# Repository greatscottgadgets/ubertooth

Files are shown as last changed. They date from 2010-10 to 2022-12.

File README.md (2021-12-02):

# Ubertooth

Project Ubertooth is an open source wireless development platform
suitable for Bluetooth experimentation. Ubertooth ships with a capable
BLE (Bluetooth Smart) sniffer and can sniff some data from Basic Rate
(BR) Bluetooth Classic connections.

The latest release is [2020-12-R1](https://github.com/greatscottgadgets/ubertooth/releases/tag/2020-12-R1).
The latest firmware build can be found on the release page.

This release is paired with [libbtbb 2020-12-R1](https://github.com/greatscottgadgets/libbtbb/releases/tag/2020-12-R1).

Instructions for flashing the firmware can be found [on the corresponding readthedocs.io firmware page](https://ubertooth.readthedocs.io/en/latest/firmware.html).
Instructions for building libbtbb can be found [on the corresponding readthedocs.io build_guide page](https://ubertooth.readthedocs.io/en/latest/build_guide.html).

--------------------

# Documentation

Documentation for Ubertooth can be viewed on [Read the Docs](https://ubertooth.readthedocs.io/en/latest/). The raw documenation files for Ubertooth are in the [docs folder](https://github.com/greatscottgadgets/ubertooth/tree/master/docs) in this repository. Documentation changes can be submitted through pull request and suggestions can be made as GitHub issues. 

--------------------

# Getting Help

Before asking for help with Ubertooth, check to see if your question is listed in the [FAQ](https://ubertooth.readthedocs.io/en/latest/faq.html).

For assistance with Ubertooth general use or development, please look at the [issues on the GitHub project](https://github.com/greatscottgadgets/ubertooth/issues). This is the preferred place to ask questions or open issues so that others may locate the answer to your question in the future.

We invite you to join our community discussions on [Discord](https://discord.gg/rsfMw3rsU8). Note that while technical support requests are welcome here, we do not have support staff on duty at all times. Be sure to also submit an issue on GitHub if you’ve found a bug or if you want to ensure that your request will be tracked and not overlooked.

GitHub issues on this repository that are labelled "technical support" by Great Scott Gadgets employees can expect a response time of two weeks. We currently do not have expected response times for other GitHub issues or pull requests for this repository.

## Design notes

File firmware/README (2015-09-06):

For testing a new board, see: assembly_test/README

The general purpose firmware including Bluetooth functions is bluetooth_rxtx.

This firmware is intended to be compiled with a particular toolchain:

    https://launchpad.net/gcc-arm-embedded

If you are using a recent Ubuntu or Debian system, the toolchain can be installed
from their apt repositorities as follows:

    apt-get install gcc-arm-none-eabi

The default hardware target is Ubertooth One.  If you are compiling for
Ubertooth Zero, you must set the environment variable BOARD=UBERTOOTH_ZERO.

By default the bluetooth-rxtx firmware has transmit capabilities.  If you wish
to build firmware without the ability to transmit, you may do so by setting an
envoronment variable called DISABLE_TX.  For example:

    make clean
    DISABLE_TX=1 make bluetooth_rxtx

The resulting firmware will still be named bluetooth_rxtx.bin.dfu but will be
receive only.  It is advisable to make clean first, to clear up any artifacts 
from previous builds that may have transmit functions enabled.

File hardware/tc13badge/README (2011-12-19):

Copyright 2010, 2011 Michael Ossmann

These files are part of Project Ubertooth.

This is a free hardware design; you can redistribute it and/or modify
it under the terms of the GNU General Public License as published by
the Free Software Foundation; either version 2, or (at your option)
any later version.

This design is distributed in the hope that it will be useful,
but WITHOUT ANY WARRANTY; without even the implied warranty of
MERCHANTABILITY or FITNESS FOR A PARTICULAR PURPOSE.  See the
GNU General Public License for more details.

You should have received a copy of the GNU General Public License
along with this design; see the file COPYING.  If not, write to
the Free Software Foundation, Inc., 51 Franklin Street,
Boston, MA 02110-1301, USA.

ToorCon 13 Badge

This is a special purpose Ubertooth design.  See:

http://greatscottgadgets.com/tc13badge/

hardware notes:

Schematic and layout files were designed in KiCad, an open source electronic
design automation package.

PCB description: 2 layer PCB 1.6 mm
DE104iML or equivalent substrate (Er=4.42@2.4GHz TanD=0.016)
double side solder mask black
double side silkscreen white
6 mil min trace width and
6 mil min isolation

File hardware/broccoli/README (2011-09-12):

Copyright 2010, 2011 Michael Ossmann

These files are part of Project Ubertooth.

This is a free hardware design; you can redistribute it and/or modify
it under the terms of the GNU General Public License as published by
the Free Software Foundation; either version 2, or (at your option)
any later version.

This design is distributed in the hope that it will be useful,
but WITHOUT ANY WARRANTY; without even the implied warranty of
MERCHANTABILITY or FITNESS FOR A PARTICULAR PURPOSE.  See the
GNU General Public License for more details.

You should have received a copy of the GNU General Public License
along with this design; see the file COPYING.  If not, write to
the Free Software Foundation, Inc., 51 Franklin Street,
Boston, MA 02110-1301, USA.

project code name: Broccoli

Trying out another wireless transceiver IC (TRC104).  It isn't finished yet.
There are problems with the TRC104 oscillator that need to be resolved before
testing can be completed.  Firmware for this design is being developed in
branches/broccoli but the hardware is in trunk.

hardware notes:

Schematic and layout files were designed in KiCad, an open source electronic
design automation package.

PCB description: 2 layer PCB 1.6 mm
DE104iML or equivalent substrate (Er=4.42@2.4GHz TanD=0.016)
double side solder mask black
double side silkscreen white
6 mil min trace width and
6 mil min isolation

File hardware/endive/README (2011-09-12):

Copyright 2010, 2011 Michael Ossmann

These files are part of Project Ubertooth.

This is a free hardware design; you can redistribute it and/or modify
it under the terms of the GNU General Public License as published by
the Free Software Foundation; either version 2, or (at your option)
any later version.

This design is distributed in the hope that it will be useful,
but WITHOUT ANY WARRANTY; without even the implied warranty of
MERCHANTABILITY or FITNESS FOR A PARTICULAR PURPOSE.  See the
GNU General Public License for more details.

You should have received a copy of the GNU General Public License
along with this design; see the file COPYING.  If not, write to
the Free Software Foundation, Inc., 51 Franklin Street,
Boston, MA 02110-1301, USA.

project code name: Endive

This is an adapter for the E8a programming connector on Dandelion.  It can be
used with either a Renesas E8a or a Pogoprog or similar FTDI board.

hardware notes:

Schematic and layout files were designed in KiCad, an open source electronic
design automation package.

PCB description: 2 layer PCB 1.6 mm
DE104iML or equivalent substrate (Er=4.42@2.4GHz TanD=0.016)
double side solder mask black
double side silkscreen white
10 mil min trace width and
10 mil min isolation

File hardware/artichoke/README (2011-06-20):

Copyright 2010 Michael Ossmann

These files are part of Project Ubertooth.

This is a free hardware design; you can redistribute it and/or modify
it under the terms of the GNU General Public License as published by
the Free Software Foundation; either version 2, or (at your option)
any later version.

This design is distributed in the hope that it will be useful,
but WITHOUT ANY WARRANTY; without even the implied warranty of
MERCHANTABILITY or FITNESS FOR A PARTICULAR PURPOSE.  See the
GNU General Public License for more details.

You should have received a copy of the GNU General Public License
along with this design; see the file COPYING.  If not, write to
the Free Software Foundation, Inc., 51 Franklin Street,
Boston, MA 02110-1301, USA.

project code name: Artichoke

This is candidate to become Ubertooth Two.  It isn't finished yet.

hardware notes:

Schematic and layout files were designed in KiCad, an open source electronic
design automation package.

order of copper layers:
	Front
	Inner3
	Inner2
	Back

PCB description: 4 layer PCB 1.6 mm
	Copper        1   35 um
	Dielectric  1-2   0.35 mm
	Copper        2   18 um
	Dielectric  2-3   0.76 mm
	Copper        3   18 um
	Dielectric  3-4   0.35 mm
	Copper        4   35 um
DE104iML or equivalent substrate (Er=4.42@2.4GHz TanD=0.016)
double side solder mask black
double side silkscreen white
6 mil min trace width and
6 mil min isolation

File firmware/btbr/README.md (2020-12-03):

# UBTBR firmware

This firmware implements partial support of the Bluetooth BR/EDR baseband layer.

## Supported features

- Inquiry/Inquiry scan: Perform inquiry to discover nearby devices, or reply to inquiries to be visible.
- Page/Page scan: Establish a connection as a master, or allow connection as slave.
- Link-Layer: Poor-man link-layer to maintain a connection.
- Monitoring: Spy on pairing procedures of remote devices

## Limitations / TODOs
- Due to limitations of the cc2400, only BR packets are supported.
- Packet types supported: ID, NULL, POLL, FHS, DM*, DH*.
- Link-layer only supports ACL packets.
- Master side of link-layer drains too much battery of the slave (FIXME: POLL less).
- Role-switching and related LMP procedures are not yet implemented.
- Encryption of packets is not yet implemented.

## Host code
The *ubtbr* python modules contains the host control interface and a minimal implementation of the LMP protocol. 

UBTBR can be controlled using the *ubtbr* python module, and the ubertooth-btbr tool.

See host/python/ubtbr/README.

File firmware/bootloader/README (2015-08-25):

bootloader.c is the first level firmware on the Ubertooth.  With this installed
you can update the main application over USB.

The bootloader must be installed using a hardware programmer (serial or JTAG).
For example, a Pogoprog (serial programmer) may be used with the In-System
Programming (ISP) mode.  Once the bootloader is installed, application firmware
may be loaded repeatedly over USB without requiring additional hardware.
Commercially produced Ubertooth devices should have the bootloader installed at
the factory.

Operation:

The bootloader executes every time the device starts up from reset or power
cycle.  Normally it just gets out of the way and passes control to the
application firmware very quickly.  Alternatively it can enter DFU mode which
permits firmware upload and download over USB.  There are two ways to tell the
bootloader that you want it to enter DFU mode:

1. soft bootloader entry: By setting a flag in RAM, the application firmware
can instruct the bootloader to enter DFU mode following a reset (without loss
of power).  For example, with the bluetooth_rxtx firmware running you can
update the firmware via DFU mode using the 'ubertooth-dfu' (located in
host/ubertooth-tools/src/).  Soft entry only works on Ubertooth One, not
Ubertooth Zero.

2. hard bootloader entry (aka pin entry): By connecting two pins on the
expansion header with a jumper during reset (either soft or hard boot), you can
force the bootloader into DFU mode.  When using pin entry, the bootloader will
enter DFU mode for only a few seconds and will then execute the application if
no DFU activity has started during that period.  This allows developers to
permanently or semi-permanently jumper the pins providing a DFU opportunity on
every reset.  The permanent jumper method works on Ubertooth One but not
Ubertooth Zero.

The bootloader indicates DFU mode by flashing the LEDs in a distinctive
pattern.  It also identifies itself as "usb_bootloader" on USB.

During DFU mode, firmware may be uploaded or downloaded using ubertooth-dfu.
For usage instructions, run 'ubertooth-dfu -h'.

It is possible that soft bootloader entry may be broken by installing a faulty
application or an application that does not provide a method of triggering soft
entry.  In this case, pin entry must be used (e.g. by holding a paper clip in
the expansion header while plugging in the device) to "unbrick" the unit.

For Ubertooth One, the pins to connect are pins 1 and 3 of the expansion header
(P4).  For Ubertooth Zero, the pins to connect are pins 1 and 13 of the
expansion header (J1).

The bootloader is installed at 0x0000.  It installs application firmware at
0x4000.

To build the bootloader you will need to install libstdc++ for ARM.
On Debian based systems:
apt-get install libstdc++-arm-none-eabi-newlib

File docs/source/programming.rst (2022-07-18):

===========
Programming
===========

This page describes how to load compiled firmware onto an Ubertooth One. Other pages describe how to write `firmware <https://ubertooth.readthedocs.io/en/latest/firmware.html>`__ or `host code <https://ubertooth.readthedocs.io/en/latest/software.html>`__ for the platform.

There are three ways to program an Ubertooth board: the USB bootloader, the ISP bootloader, and JTAG.

Please note that it is not possible to replace the board's USB bootloader via ubertooth-dfu as there is software protection in place. 

USB bootloader
~~~~~~~~~~~~~~

This is the recommended method of loading code onto an Ubertooth Zero or Ubertooth One provided that the USB bootloader is already installed (at the time of manufacture, for example). If you need to install the bootloader itself, you will have to use either ISP or JTAG.

The bootloader executes every time the device starts up from reset or power cycle. Normally it just gets out of the way and passes control to the application firmware very quickly. Alternatively it can enter Device Firmware Upgrade (DFU) mode which permits firmware upload and download over USB. There are two ways to tell the bootloader that you want it to enter DFU mode:

    #. soft bootloader entry: By setting a flag in RAM, the application firmware can instruct the bootloader to enter DFU mode following a reset (without loss of power). For example, with the bluetooth_rxtx firmware running you can trigger a reset into DFU mode using 'ubertooth-util -f' (located in host/bluetooth_rxtx/). Soft entry only works on Ubertooth One, not Ubertooth Zero.

    #. hard bootloader entry (also known as pin entry): By connecting two pins (for Ubertooth Zero it's pin 1 and 3) on the expansion header with a jumper during reset (either soft or hard boot), you can force the bootloader into DFU mode. When using pin entry, the bootloader will enter DFU mode for only a few seconds and will then execute the application if no DFU activity has started during that period. This allows developers to permanently or semi-permanently jumper the pins providing a DFU opportunity on every reset. This method works on Ubertooth One but not Ubertooth Zero.

The bootloader indicates DFU mode by flashing the LEDs in a distinctive pattern. It also identifies itself as "usb_bootloader" on USB.

During DFU mode, firmware may be uploaded or downloaded using ubertooth-dfu.

It is possible that soft bootloader entry may be broken by installing a faulty application or an application that does not provide a method of triggering soft entry. In this case, pin entry must be used (e.g. by holding a paper clip in the expansion header while plugging in the device) to "unbrick" the unit.

For Ubertooth One, the pins to connect are pins 1 and 3 of the expansion header (P4). For Ubertooth Zero, the pins to connect are pins 1 and 13 of the expansion header (J1).

ISP bootloader
~~~~~~~~~~~~~~

The LPC175x features an In-System Programming (ISP) bootloader that allows code to be loaded over a serial interface. In order to use ISP, you will need `lpc21isp <http://sourceforge.net/projects/lpc21isp>`__ and a 3.3V serial programming device such as one of the following:

Pogoprog
^^^^^^^^

The official Ubertooth ISP programmer is Pogoprog, an open source board that can be assembled using a process similar to Ubertooth One assembly.

An FTDI Basic Breakout - 3.3V
^^^^^^^^^^^^^^^^^^^^^^^^^^^^^

You can use SparkFun's `FTDI Basic Breakout - 3.3V <http://www.sparkfun.com/products/9873>`__ to program an Ubertooth. Adafruit's `FTDI Friend <http://www.adafruit.com/index.php?main_page=product_info&products_id=284>`__ is a similar board that should work as well. To allow lpc21isp to automatically activate the LPC175x's ISP bootloader, you must modify the board in one of two ways.

Method one: the easy way
++++++++++++++++++++++++

Just short the CTS pin to GND. This will force the microcontroller into ISP mode every time it resets while the programmer is connected. In order to perform a normal reset to run the newly loaded code, you will have to first disconnect the programmer.

Method two: the better way
++++++++++++++++++++++++++

Connect the CTS pin to the RTS pin (pin 3) on the FT232RL using fine gauge wire such as wire wrap wire. This is trickier to solder, but it has the advantage that the pin will be fully controlled by lpc21isp. This means that you can leave the programmer connected to the Ubertooth board throughout multiple program/test cycles.

Using ISP
+++++++++

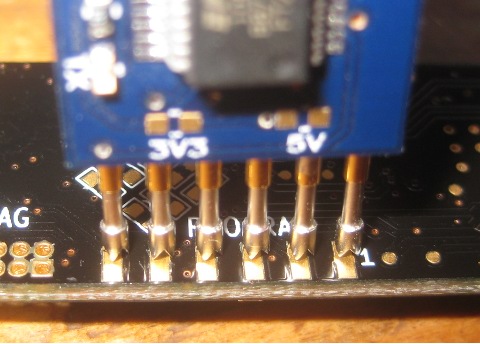
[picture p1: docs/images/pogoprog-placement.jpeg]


Warning: Code loaded via ISP will blow away the bootloader. It is generally recommended to use this method only for installing the bootloader itself.

Connect your serial programmer to the Ubertooth board and type "make program" in the firmware source code directory. If you have a precompiled binary in .hex format, you can invoke lpc21isp directly with "lpc21isp -control firmware.hex /dev/ttyUSB0 230400 4000" (replacing firmware.hex with the firmware filename and /dev/ttyUSB0 with the device file of your serial programmer.

JTAG
^^^^

Warning: Code loaded via JTAG will blow away the bootloader. It is generally recommended to use this method only for installing the bootloader itself.

Connect your ARM Cortex-M3 JTAG debugger (such as one supported by `OpenOCD <http://openocd.berlios.de/web>`__) to the standard Cortex Debug Connector on the Ubertooth One or the non-standard JTAG connector on the Ubertooth Zero. You know what to do.

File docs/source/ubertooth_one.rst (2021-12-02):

=============
Ubertooth One
=============

Ubertooth One is the hardware platform of Project Ubertooth. It supersedes `Ubertooth Zero <https://ubertooth.readthedocs.io/en/latest/ubertooth_zero.html>`__ and is currently the preferred platform.

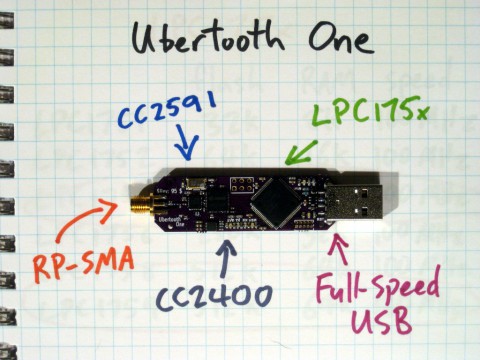
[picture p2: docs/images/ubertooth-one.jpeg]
	

Architecture
~~~~~~~~~~~~

* `RP-SMA <http://en.wikipedia.org/wiki/SMA_connector>`__ RF connector: connects to test equipment, antenna, or dummy load.

* `CC2591 <http://www.ti.com/product/cc2591>`__ RF front end.

* `CC2400 <http://www.ti.com/product/cc2400>`__ wireless transceiver.

* `LPC175x <http://www.nxp.com/products/microcontrollers-and-processors/arm-processors/lpc-cortex-m-mcus/lpc1700-cortex-m3:MC_1403790745385>`__ ARM Cortex-M3 microcontroller with Full-Speed USB 2.0.

* USB A plug: connects to host computer running `Kismet <https://www.kismetwireless.net/>`__ or other host code.

Features
~~~~~~~~

* 2.4 GHz transmit and receive.

* Transmit power and receive sensitivity comparable to a Class 1 Bluetooth device.

* Standard `Cortex Debug Connector <http://infocenter.arm.com/help/topic/com.arm.doc.faqs/attached/13634/cortex_debug_connectors.pdf>`__ (10-pin 50-mil JTAG).

* In-System Programming (ISP) serial connector.

* Expansion connector: intended for inter-Ubertooth communication or other future uses.

* Six indicator LEDs.

Design
~~~~~~

Ubertooth One was designed in `KiCad <https://www.kicad.org/>`__, an open source electronic design automation software package, with surface mount components suitable for `reflow <http://www.sparkfun.com/tutorials/59>`__.

Pins and LEDs
^^^^^^^^^^^^^

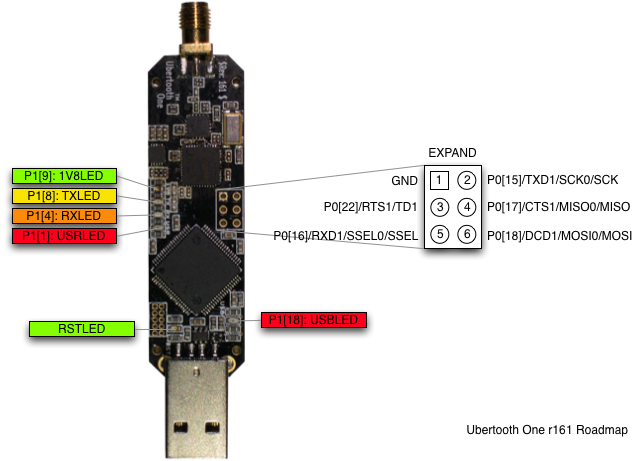
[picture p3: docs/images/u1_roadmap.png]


This diagram shows the location of LEDs and the pins of the expansion connector.

LED guide:

    * RST: indicates that the LPC175x is powered on. This should always be on during operation except during a full reset of the LPC175x (e.g., while entering ISP mode).

    * 1V8: indicates that the CC2400 is being supplied with 1.8 V. Control of this supply depends on firmware. 1V8 power is required to activate the crystal oscillator which is required to activate USB.

    * USB: indicates that USB has passed enumeration and configuration.

    * TX: Control of this LED depends on firmware. It typically indicates radio transmission.

    * RX: Control of this LED depends on firmware. It typically indicates radio reception.

    * USR: Control of this LED depends on firmware.

The TX, RX, and USR LEDs blink in a distinctive chasing pattern when the bootloader is ready to accept USB DFU commands.

Power Usage
^^^^^^^^^^^

These measurements were taken using Ubertooth One running firmware revision 2014-02-R2. Zero_Chaos took these measurements using a Centech CT-USB-PW, available via `eBay <http://www.ebay.com/itm/Century-JAPAN-USB-Power-Meter-voltage-measuring-instrument-Centech-CT-USB-PW-/151281911884>`__ and `others <http://store.mcetech.com/Merchant2/merchant.mvc?Screen=PROD&Product_Code=CT-USB-PW&Category_Code=USBPERIPH>`__.

.. list-table :: 
  :header-rows: 1
  :widths: 1 1 1

  * - Command
    - Description
    - Power draw (amps)
  * -
    - Idle
    - 0.09A
  * - ``ubertooth-dump``
    - Receive
    - 0.13A
  * - ``ubertooth-util -t``
    - Transmit
    - 0.22A
  * - ``ubertooth-dfu --write``
    - Firmware upgrade
    - 0.10A

Demonstration
^^^^^^^^^^^^^

Michael Ossmann presented `Project Ubertooth: Building a Better Bluetooth Adapter <http://www.shmoocon.org/schedule#ubertooth>`__ at `ShmooCon <http://www.shmoocon.org/>`__ 2011.

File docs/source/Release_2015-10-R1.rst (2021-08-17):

==================
Release 2015-10-R1
==================

Prerequisites
~~~~~~~~~~~~~

There are some prerequisites that need to be installed before building libbtbb and the Ubertooth tools. Many of these are available from your operating system's package repositories, for example:

Debian/Ubuntu
^^^^^^^^^^^^^

	.. code-block:: sh

		sudo apt-get install cmake libusb-1.0-0-dev make gcc g++ libbluetooth-dev \
		pkg-config libpcap-dev python-numpy python-pyside python-qt4

Fedora / Red Hat
^^^^^^^^^^^^^^^^

	.. code-block:: sh

		su -c "yum install libusb1-devel make gcc wget tar bluez-libs-devel"

Mac OS X users can use either MacPorts or Homebrew to install the required packages:
^^^^^^^^^^^^^^^^^^^^^^^^^^^^^^^^^^^^^^^^^^^^^^^^^^^^^^^^^^^^^^^^^^^^^^^^^^^^^^^^^^^^

	.. code-block:: sh

		sudo port install libusb wget cmake python27 py27-numpy py27-pyside
		or
		brew install libusb wget cmake pkg-config homebrew/dupes/libpcap

libbtbb
~~~~~~~

Next the Bluetooth baseband library (libbtbb) needs to be built for the Ubertooth tools to decode Bluetooth packets:

	.. code-block:: sh

		wget https://github.com/greatscottgadgets/libbtbb/archive/2015-10-R1.tar.gz -O libbtbb-2015-10-R1.tar.gz
		tar xf libbtbb-2015-10-R1.tar.gz
		cd libbtbb-2015-10-R1
		mkdir build
		cd build
		cmake ..
		make
		sudo make install

**Linux users:** if you are installing for the first time, or you receive errors about finding the library, you should run:

	.. code-block:: sh

		sudo ldconfig

Wireshark
~~~~~~~~~

Wireshark version 1.12 and newer includes the Ubertooth BLE plugin by default. It is also possible to `capture BLE from Ubertooth directly into Wireshark <https://ubertooth.readthedocs.io/en/latest/capturing_BLE_Wireshark.html>`__ with a little work.

The Wireshark BTBB and BR/EDR plugins allow Bluetooth baseband traffic that has been captured using Kismet to be analysed and disected within the Wireshark GUI. They are built separately from the rest of the Ubertooth and libbtbb software. The directory passed to cmake as ``MAKE_INSTALL_LIBDIR`` varies from system to system, but it should be the location of existing Wireshark plugins, such as ``asn1.so`` and ``ethercat.so``.

	.. code-block:: sh

		sudo apt-get install wireshark wireshark-dev libwireshark-dev cmake
		cd libbtbb-2015-10-R1/wireshark/plugins/btbb
		mkdir build
		cd build
		cmake -DCMAKE_INSTALL_LIBDIR=/usr/lib/x86_64-linux-gnu/wireshark/libwireshark3/plugins ..
		make
		sudo make install

Then repeat for the BT BR/EDR plugin:

	.. code-block:: sh

		sudo apt-get install wireshark wireshark-dev libwireshark-dev cmake
		cd libbtbb-2015-10-R1/wireshark/plugins/btbredr
		mkdir build
		cd build
		cmake -DCMAKE_INSTALL_LIBDIR=/usr/lib/x86_64-linux-gnu/wireshark/libwireshark3/plugins ..
		make
		sudo make install

Third Party Software
~~~~~~~~~~~~~~~~~~~~

There are a number of pieces of `third party software <https://ubertooth.readthedocs.io/en/latest/third_party_software.html>`__ that support the Ubertooth. Some support Ubertooth out of the box, while others require plugins to be built.

Firmware
^^^^^^^^

This completes the install of the Ubertooth tools, the next step is to look at the getting started guide. You should always `update the firmware <https://ubertooth.readthedocs.io/en/latest/firmware.html>`__ on the Ubertooth device to match the software release version that you are using.

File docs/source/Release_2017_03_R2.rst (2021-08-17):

==================
Release 2017-03-R2
==================

`for Release 2015-10-R1 see here <https://ubertooth.readthedocs.io/en/latest/Release_2015-10-R1.html>`__

Prerequisites
~~~~~~~~~~~~~

There are some prerequisites that need to be installed before building libbtbb and the Ubertooth tools. Many of these are available from your operating system's package repositories, for example:

Debian / Ubuntu

	.. code-block:: sh

		sudo apt-get install cmake libusb-1.0-0-dev make gcc g++ libbluetooth-dev \
		pkg-config libpcap-dev python-numpy python-pyside python-qt4

Fedora / Red Hat

	.. code-block:: sh

		su -c "yum install libusb1-devel make gcc wget tar bluez-libs-devel"

Mac OS X users can use either MacPorts or Homebrew to install the required packages:

	.. code-block:: sh

		sudo port install libusb wget cmake python27 py27-numpy py27-pyside
		or
		brew install libusb wget cmake pkg-config libpcap

FreeBSD users can install the host tools and library directly from the ports and package system:

	.. code-block:: sh

		sudo pkg install ubertooth

libbtbb
~~~~~~~

Next the Bluetooth baseband library (libbtbb) needs to be built for the Ubertooth tools to decode Bluetooth packets:

	.. code-block:: sh

		wget https://github.com/greatscottgadgets/libbtbb/archive/2017-03-R2.tar.gz -O libbtbb-2017-03-R2.tar.gz
		tar xf libbtbb-2017-03-R2.tar.gz
		cd libbtbb-2017-03-R2
		mkdir build
		cd build
		cmake ..
		make
		sudo make install

Linux users: if you are installing for the first time, or you receive errors about finding the library, you should run:	

	.. code-block:: sh

		sudo ldconfig

Ubertooth tools
~~~~~~~~~~~~~~~

The Ubertooth repository contains host code for sniffing Bluetooth packets, configuring the Ubertooth and updating firmware. All three are built and installed by default using the following method:

	.. code-block:: sh

		wget https://github.com/greatscottgadgets/ubertooth/releases/download/2017-03-R2/ubertooth-2017-03-R2.tar.xz -O ubertooth-2017-03-R2.tar.xz
		tar xf ubertooth-2017-03-R2.tar.xz
		cd ubertooth-2017-03-R2/host
		mkdir build
		cd build
		cmake ..
		make
		sudo make install

Linux users: if you are installing for the first time, or you receive errors about finding the library, you should run:

	.. code-block:: sh

		sudo ldconfig

Wireshark
~~~~~~~~~

Wireshark version 1.12 and newer includes the Ubertooth BLE plugin by default. It is also possible to `capture BLE from Ubertooth directly into Wireshark <https://ubertooth.readthedocs.io/en/latest/capturing_BLE_Wireshark.html>`__ with a little work.

The Wireshark BTBB and BR/EDR plugins allow Bluetooth baseband traffic that has been captured using Kismet to be analysed and disected within the Wireshark GUI. They are built separately from the rest of the Ubertooth and libbtbb software. The directory passed to cmake as ``MAKE_INSTALL_LIBDIR`` varies from system to system, but it should be the location of existing Wireshark plugins, such as ``asn1.so`` and ``ethercat.so``.

	.. code-block:: sh

		sudo apt-get install wireshark wireshark-dev libwireshark-dev cmake
		cd libbtbb-2017-03-R2/wireshark/plugins/btbb
		mkdir build
		cd build
		cmake -DCMAKE_INSTALL_LIBDIR=/usr/lib/x86_64-linux-gnu/wireshark/libwireshark3/plugins ..
		make
		sudo make install

Then repeat for the BT BR/EDR plugin:

	.. code-block:: sh

		sudo apt-get install wireshark wireshark-dev libwireshark-dev cmake
		cd libbtbb-2017-03-R2/wireshark/plugins/btbredr
		mkdir build
		cd build
		cmake -DCMAKE_INSTALL_LIBDIR=/usr/lib/x86_64-linux-gnu/wireshark/libwireshark3/plugins ..
		make
		sudo make install

Third Party Software
~~~~~~~~~~~~~~~~~~~~

There are a number of pieces of `third party software <https://ubertooth.readthedocs.io/en/latest/third_party_software.html>`__ that support the Ubertooth. Some support Ubertooth out of the box, while others require plugins to be built.

Firmware
^^^^^^^^

This completes the install of the Ubertooth tools, the next step is to look at the getting started guide. You should always `update the firmware <https://ubertooth.readthedocs.io/en/latest/firmware.html>`__ on the Ubertooth device to match the software release version that you are using.

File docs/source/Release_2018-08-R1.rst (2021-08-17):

======================================
Release 2018-08-R1: the DEFCON release
======================================

`for Release 2017-03-R2 see here <https://ubertooth.readthedocs.io/en/latest/Release_2017_03_R2.html>`__

Preequisites
~~~~~~~~~~~~

There are some prerequisites that need to be installed before building libbtbb and the Ubertooth tools. Many of these are available from your operating system's package repositories, for example:

Debian / Ubuntu

	.. code-block:: sh

		sudo apt-get install cmake libusb-1.0-0-dev make gcc g++ libbluetooth-dev \
		pkg-config libpcap-dev python-numpy python-pyside python-qt4

Fedora / Red Hat

	.. code-block:: sh

		su -c "yum install libusb1-devel make gcc wget tar bluez-libs-devel"s

Mac OS X users can use either MacPorts or Homebrew to install the required packages:

	.. code-block:: sh

		brew install libusb wget cmake pkg-config libpcap
		or
		sudo port install libusb wget cmake python27 py27-numpy py27-pyside

FreeBSD users can install the host tools and library directly from the ports and package system:

	.. code-block:: sh

		sudo pkg install ubertooth

libbtbb
~~~~~~~

Next the Bluetooth baseband library (libbtbb) needs to be built for the Ubertooth tools to decode Bluetooth packets:

	.. code-block:: sh

		wget https://github.com/greatscottgadgets/libbtbb/archive/2018-08-R1.tar.gz -O libbtbb-2018-08-R1.tar.gz
		tar -xf libbtbb-2018-08-R1.tar.gz
		cd libbtbb-2018-08-R1
		mkdir build
		cd build
		cmake ..
		make
		sudo make install	

Linux users: if you are installing for the first time, or you receive errors about finding the library, you should run:

	.. code-block:: sh

		sudo ldconfig

Ubertooth tools
~~~~~~~~~~~~~~~

The Ubertooth repository contains host code for sniffing Bluetooth packets, configuring the Ubertooth and updating firmware. All three are built and installed by default using the following method:

	.. code-block:: sh

		wget https://github.com/greatscottgadgets/ubertooth/releases/download/2018-08-R1/ubertooth-2018-08-R1.tar.xz
		tar xf ubertooth-2018-08-R1.tar.xz
		cd ubertooth-2018-08-R1/host
		mkdir build
		cd build
		cmake ..
		make
		sudo make install

Linux users: if you are installing for the first time, or you receive errors about finding the library, you should run:

	.. code-block:: sh

		sudo ldconfig

Wireshark
~~~~~~~~~

Wireshark version 1.12 and newer includes the Ubertooth BLE plugin by default. It is also possible to `capture BLE from Ubertooth directly into Wireshark <https://ubertooth.readthedocs.io/en/latest/capturing_BLE_Wireshark.html>`__ with a little work.

The Wireshark BTBB and BR/EDR plugins allow Bluetooth baseband traffic that has been captured using Kismet to be analysed and disected within the Wireshark GUI. They are built separately from the rest of the Ubertooth and libbtbb software.

The directory passed to cmake as ``MAKE_INSTALL_LIBDIR`` varies from system to system, but it should be the location of existing Wireshark plugins, such as ``asn1.so`` and ``ethercat.so``. On macOS this is likely ``/Applications/Wireshark.app/Contents/PlugIns/wireshark/``.

	.. code-block:: sh

		sudo apt-get install wireshark wireshark-dev libwireshark-dev cmake
		cd libbtbb-2018-08-R1/wireshark/plugins/btbb
		mkdir build
		cd build
		cmake -DCMAKE_INSTALL_LIBDIR=/usr/lib/x86_64-linux-gnu/wireshark/libwireshark3/plugins ..
		make
		sudo make install

Then repeat for the BT BR/EDR plugin:

	.. code-block:: sh

		sudo apt-get install wireshark wireshark-dev libwireshark-dev cmake
		cd libbtbb-2018-08-R1/wireshark/plugins/btbredr
		mkdir build
		cd build
		cmake -DCMAKE_INSTALL_LIBDIR=/usr/lib/x86_64-linux-gnu/wireshark/libwireshark3/plugins ..
		make
		sudo make install

Third Party Software
~~~~~~~~~~~~~~~~~~~~

There are a number of pieces of `third party software <https://ubertooth.readthedocs.io/en/latest/third_party_software.html>`__ that support the Ubertooth. Some support Ubertooth out of the box, while others require plugins to be built.

Firmware
^^^^^^^^

This completes the install of the Ubertooth tools, the next step is to look at the getting started guide. You should always `update the firmware <https://ubertooth.readthedocs.io/en/latest/firmware.html>`__ on the Ubertooth device to match the software release version that you are using.

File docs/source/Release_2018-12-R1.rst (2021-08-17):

==================
Release 2018-12-R1
==================

Prerequisites
~~~~~~~~~~~~~

There are some prerequisites that need to be installed before building libbtbb and the Ubertooth tools. Many of these are available from your operating system's package repositories, for example:

Debian / Ubuntu / Kali

	.. code-block:: sh

		sudo apt-get install cmake libusb-1.0-0-dev make gcc g++ libbluetooth-dev \
		  pkg-config python3-numpy python3-qtpy

Fedora / Red Hat

	.. code-block:: sh

		su -c "yum install libusb1-devel make gcc wget tar bluez-libs-devel"

Mac OS X users can use either MacPorts or Homebrew to install the required packages:

	.. code-block:: sh

		brew install libusb wget cmake pkg-config
		or
		sudo port install libusb wget cmake python38 py38-numpy py38-qtpy

FreeBSD users can install the host tools and library directly from the ports and package system:

	.. code-block:: sh

		sudo pkg install ubertooth

libbtbb
~~~~~~~

Next the Bluetooth baseband library (libbtbb) needs to be built for the Ubertooth tools to decode Bluetooth packets:

	.. code-block:: sh

		wget https://github.com/greatscottgadgets/libbtbb/archive/2018-12-R1.tar.gz -O libbtbb-2018-12-R1.tar.gz
		tar -xf libbtbb-2018-12-R1.tar.gz
		cd libbtbb-2018-12-R1
		mkdir build
		cd build
		cmake ..
		make
		sudo make install

Linux users: if you are installing for the first time, or you receive errors about finding the library, you should run:

	.. code-block:: sh

		sudo ldconfig

Ubertooth tools
~~~~~~~~~~~~~~~

The Ubertooth repository contains host code for sniffing Bluetooth packets, configuring the Ubertooth and updating firmware. All three are built and installed by default using the following method:

	.. code-block:: sh

		wget https://github.com/greatscottgadgets/ubertooth/releases/download/2018-12-R1/ubertooth-2018-12-R1.tar.xz
		tar xf ubertooth-2018-12-R1.tar.xz
		cd ubertooth-2018-12-R1/host
		mkdir build
		cd build
		cmake ..
		make
		sudo make install

Linux users: if you are installing for the first time, or you receive errors about finding the library, you should run:

	.. code-block:: sh

		sudo ldconfig

Wireshark
~~~~~~~~~

Wireshark version 1.12 and newer includes the Ubertooth BLE plugin by default. It is also possible to `capture BLE from Ubertooth directly into Wireshark <https://ubertooth.readthedocs.io/en/latest/capturing_BLE_Wireshark.html>`__ with a little work.

The Wireshark BTBB and BR/EDR plugins allow Bluetooth baseband traffic that has been captured using Kismet to be analysed and disected within the Wireshark GUI. They are built separately from the rest of the Ubertooth and libbtbb software.

The directory passed to cmake as ``MAKE_INSTALL_LIBDIR`` varies from system to system, but it should be the location of existing Wireshark plugins, such as ``asn1.so`` and ``ethercat.so``. On macOS this is likely ``/Applications/Wireshark.app/Contents/PlugIns/wireshark/``.

	.. code-block:: sh 

		sudo apt-get install wireshark wireshark-dev libwireshark-dev cmake
		cd libbtbb-2018-12-R1/wireshark/plugins/btbb
		mkdir build
		cd build
		cmake -DCMAKE_INSTALL_LIBDIR=/usr/lib/x86_64-linux-gnu/wireshark/libwireshark3/plugins ..
		make
		sudo make install	

Then repeat for the BT BR/EDR plugin:

	.. code-block:: sh

		sudo apt-get install wireshark wireshark-dev libwireshark-dev cmake
		cd libbtbb-2018-12-R1/wireshark/plugins/btbredr
		mkdir build
		cd build
		cmake -DCMAKE_INSTALL_LIBDIR=/usr/lib/x86_64-linux-gnu/wireshark/libwireshark3/plugins ..
		make
		sudo make install

Third Party Software
~~~~~~~~~~~~~~~~~~~~

There are a number of pieces of `third party software <https://ubertooth.readthedocs.io/en/latest/third_party_software.html>`__ that support the Ubertooth. Some support Ubertooth out of the box, while others require plugins to be built.

Firmware
^^^^^^^^

This completes the install of the Ubertooth tools, the next step is to look at the getting started guide. You should always `update the firmware <https://ubertooth.readthedocs.io/en/latest/firmware.html>`__ on the Ubertooth device to match the software release version that you are using.

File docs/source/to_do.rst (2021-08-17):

=========
ToDo List
=========

PCAP
~~~~

* Obtain DLT/linktype from libPCAP devs for BTBB, see `here <https://ubertooth.readthedocs.io/en/latest/bluetooth_captures_PCAP.html>`__.

* Define format for including meta-data (using PPI), see `here <https://ubertooth.readthedocs.io/en/latest/bluetooth_captures_PCAP.html>`__.

* Move Wireshark plugins to Wireshark repo.

* Add pcap support to ubertooth tools (currently only in kismet) by moving it to libbtbb.

Basic rate / libbtbb
~~~~~~~~~~~~~~~~~~~~

* Better handling of AFH maps when trying clock values. The code currently makes the assumption that AFH is enabled but all channels are in use.

* Detect syncword on Ubertooth for known piconets

* Make logging configurable - possibly combine text based logging, file dumps and pcap writing in to one logging system.

Releases
~~~~~~~~

* Binary packages for both libbtbb and ubertooth - rpm, deb, others?

* More frequent releases - requires better testing of code in git and separation of half-implemented features. This is more about process than an actionable todo item.

* DONE: Add uninstall to Makefile.

* Add WICD headers to support windows users (requires switch to libusbx).

GR-Bluetooth
~~~~~~~~~~~~

* Finish migration to libbtbb.

* Add BTLE support.

* General performance improvements (there must be some!).

Bigger / more vague projects
~~~~~~~~~~~~~~~~~~~~~~~~~~~~

* Transmit basic rate packets - inquiry scan to start with.

* Implement full BTLE device in firmware.

* ANT/ANT+ sniffing.

    * `http://www.thisisant.com/developer/resources/downloads/#documents_tab <http://www.thisisant.com/developer/resources/downloads/#documents_tab>`__

    * `http://www.thisisant.com/developer/resources/tech-faq/ <http://www.thisisant.com/developer/resources/tech-faq/>`__

* Communicate between Ubertooth devices using SPI on the expansion port.

* Communicate with other devices using SPI on the expansion port.

* Write to SD card using SPI on the expansion port.

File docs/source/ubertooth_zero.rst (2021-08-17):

==============
Ubertooth Zero
==============

Ubertooth Zero was the first working prototype hardware platform of Project Ubertooth. It has been superseded by `Ubertooth One <https://ubertooth.readthedocs.io/en/latest/ubertooth_one.html>`__.

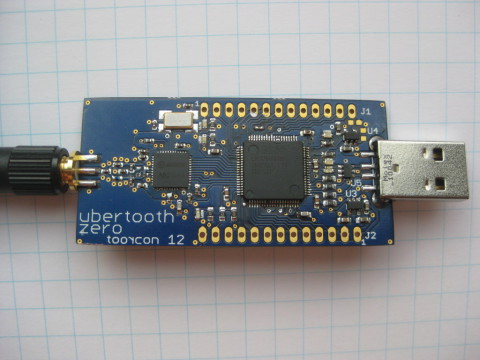
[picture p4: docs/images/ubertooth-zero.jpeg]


Architecture
~~~~~~~~~~~~

* `RP-SMA <http://en.wikipedia.org/wiki/SMA_connector>`__ RF connector: connects to test equipment, antenna, or dummy load.

* `CC2400 <http://focus.ti.com/docs/prod/folders/print/cc2400.html>`__ wireless transceiver IC.

* `LPC175x <http://ics.nxp.com/products/lpc1000/lpc17xx/>`__ ARM Cortex-M3 microcontroller with Full-Speed USB 2.0.

* USB A plug: connects to host computer running Kismet or other host code.

Features
~~~~~~~~

* 2.4 GHz transmit and receive.

* Transmit power and receive sensitivity comparable to a Class 3 Bluetooth device.

* Non-standard JTAG connector.

* In-System Programming (ISP) serial connector.

* Expansion connector: intended for inter-Ubertooth communication or other future uses.

* Six indicator LEDs.

Design
~~~~~~

Ubertooth Zero was designed in `CadSoft EAGLE <http://www.cadsoft.de/>`__ with surface mount components suitable for `reflow <http://www.sparkfun.com/tutorials/59>`__.

Demonstration
~~~~~~~~~~~~~

Michael Ossmann presented Ubertooth Zero, a preview (video: part 1, part 2) at ToorCon 12 in October, 2010.

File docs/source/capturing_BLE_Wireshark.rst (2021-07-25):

Capturing BLE in Wireshark
~~~~~~~~~~~~~~~~~~~~~~~~~~

You can capture BLE in Wireshark with standard Wireshark builds. This guide assumes Linux.

    #. Run the command: ``mkfifo /tmp/pipe``
    #. Open Wireshark
    #. Click Capture -> Options
    #. Click "Manage Interfaces" button on the right side of the window
    #. Click the "New" button
    #. In the "Pipe" text box, type "/tmp/pipe"
    #. Click Save, then click Close
    #. Click "Start"

In a terminal, run ``ubertooth-btle``:

	.. code-block:: sh

		ubertooth-btle -f -c /tmp/pipe

In the Wireshark window you should see packets scrolling by.

Note: If you get `User encapsulation not handled: DLT=147, check your Preferences->Protocols->DLT_USER <https://github.com/greatscottgadgets/ubertooth/issues/61>`__ the steps you want are:

    #. Click Edit -> Preferences
    #. Click Protocols -> DLT_USER
    #. Click Edit (Encapsulations Table)
    #. Click New
    #. Under DLT, select "User 0 (DLT=147)" (adjust this selection as appropriate if the error message showed a different DLT number than 147)
    #. Under Payload Protocol, enter: btle
    #. Click OK
    #. Click OK

Capturing BLE in scapy
^^^^^^^^^^^^^^^^^^^^^^

#. Do not use mkfifo for the filename, it will cause scapy to slow dramatically.

#. In a terminal, run ubertooth-btle:

	.. code-block:: sh

		ubertooth-btle -f -q /tmp/pipe

#. Open python and run:

	.. code-block:: sh

		from scapy.all import *
		p = sniff(offline='/tmp/pipe')

p is now a list of the packets captured!

Sniffing connection data
^^^^^^^^^^^^^^^^^^^^^^^^

With recent Ubertooth firmware, only advertisements are captured by default. Once you have identified the device address of the target device you would like to sniff, run:

	.. code-block:: sh

		ubertooth-btle -t aa:bb:cc:dd:ee:ff

The Ubertooth will follow connections involving this target until -t none is passed or the device is reset.

You may need to attempt connecting several times until Ubertooth is able to follow the connection successfully.

Capturing from a remote host
^^^^^^^^^^^^^^^^^^^^^^^^^^^^

You can use `sshdump <https://www.wireshark.org/docs/man-pages/sshdump.html>`__ to remotely capture packets from a Ubertooth attached to another host or virtual machine. In the Wireshark UI, this may show up as an interface named "SSH remote capture: ``sshdump``" which needs to be configured first with the following "remote capture command":

	.. code-block:: sh

		killall ubertooth-btle; unlink /tmp/btlepipe; mkfifo /tmp/btlepipe; ubertooth-btle -f -c /tmp/btlepipe &>/dev/null & cat /tmp/btlepipe

The "remote interface" option is ignored and can be set to any value.

Useful display filters
^^^^^^^^^^^^^^^^^^^^^^

Only connection requests and non-zero data packets:

	.. code-block:: sh

		btle.data_header.length > 0 || btle.advertising_header.pdu_type == 0x05

Only attribute read responses, write requests, and notifications:

	.. code-block:: sh

		btatt.opcode in { 0x0b 0x12 0x1b }

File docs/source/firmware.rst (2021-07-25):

========
Firmware
========

How To Update Firmware
~~~~~~~~~~~~~~~~~~~~~~

First, grab the `latest Ubertooth release <https://github.com/greatscottgadgets/ubertooth/releases/latest>`__. Then, extract the archive and change into directory ``ubertooth-one-firmware-bin``.

You may then run the ``ubertooth-dfu`` command like so:

	.. code-block:: Sh

		$ ubertooth-dfu -d bluetooth_rxtx.dfu -r
		Switching to DFU mode...
		Checking firmware signature
		........................................
		........................................
		................

The device will automatically enter DFU mode and flash the firmware.

If you see ``control message unsupported`` at the end, this means that resetting the device failed. You can handle this by running ``ubertooth-util -r`` or just unplugging the USB cable from the Ubertooth and reconnecting it.

Troubleshooting:

If you run into an error such as "libUSB Error: Command Error: (-1)" or the Ubertooth's 4 LEDs next to each other perform a distinctive chasing pattern, after extracting the archive of the latest Ubertooth release, change into the ``firmware`` directory. Then, run:

	.. code-block:: sh

		make clean all && make
		ubertooth-dfu -r -d bluetooth_rxtx/bluetooth_rxtx.dfu

If your Ubertooth Ones has no firmware or broken firmware and doesn't show up when issuing ``lsusb``, you can force the Ubertooth One into DFU mode by connecting pins 1 and 3 on the EXPAND header (P4):

	

You should see the following appear in dmesg:

	.. code-block:: sh

		[ 1323.391369] usb 1-10: new full-speed USB device number 7 using xhci_hcd
		[ 1323.541063] usb 1-10: New USB device found, idVendor=1d50, idProduct=6002, bcdDevice= 1.05
		[ 1323.541069] usb 1-10: New USB device strings: Mfr=1, Product=2, SerialNumber=3
		[ 1323.541073] usb 1-10: Product: Ubertooth One
		[ 1323.541077] usb 1-10: Manufacturer: Great Scott Gadgets
		[ 1323.541080] usb 1-10: SerialNumber: 07b00004c81435ae82624953861e00f5
		[ 1341.978766] usb 1-10: USB disconnect, device number 7

The device will only stay in dfu mode for a few seconds, so you have to quickly issue the ubertooth-dfu command to flash.

What Version Am I Running? 
^^^^^^^^^^^^^^^^^^^^^^^^^^

In non-DFU mode, you can obtain firmware information with ``ubertooth-util -v``. Note that the version shown should match the one you just installed:

	.. code-block:: sh

		$ ubertooth-util -v
		Firmware version: 2018-12-R1 (API:1.05)
		$ ubertooth-util -V
		ubertooth 2018-12-R1 (mikeryan@steel) Tue Aug  7 15:33:06 PDT 2018

Developing Firmware
^^^^^^^^^^^^^^^^^^^

You'll need a toolchain that supports ARM Cortex-M3. The Makefiles in the firmware directory are designed for GCC and a Linux-based toolchain, specifically ``arm-none-eabi-gcc and libnewlib-arm-none-eabi``. If you are running a Debian based distribution, you can run:

	.. code-block:: sh

		apt-get install gcc-arm-none-eabi libnewlib-arm-none-eabi

Otherwise it can be downloaded from `https://launchpad.net/gcc-arm-embedded <https://launchpad.net/gcc-arm-embedded>`__, just unpack the archive and add the bin directory to your PATH.

To build the firmware, start from the directory where you cloned or unpacked the source and run the following:

	.. code-block:: sh

		cd firmware/bluetooth_rxtx/
		make

This will produce a file named bluetooth_rxtx.dfu which can be written to the Ubertooth using

	.. code-block:: sh

		ubertooth-dfu -d bluetooth_rxtx.dfu -r

Although firmware source and binary images can be found in the release downloads, you will probably want fresh code from git if you are planning to modify the firmware.

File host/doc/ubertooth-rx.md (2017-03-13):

# UBERTOOTH-RX 1 "March 2017" "Project Ubertooth" "User Commands"

## NAME

ubertooth-rx(1) - Classic Bluetooth discovery, sniffing, and decoding

## SYNOPSIS

    ubertooth-rx [ -l <lap> [ -u <uap ] ]
    ubertooth-rx -z

## DESCRIPTION

ubertooth-rx(1) is the primary interface into Classic Bluetooth (BR)
functionality provided by Ubertooth. It has two main modes of operation:
piconet following and survey mode. In either mode, ubertooth-rx(1) is
able to discover undiscoverable devices. See [DISCOVERING UNDISCOVERABLE
DEVICES][].

In piconet following mode, the tool will follow the first piconet it
fully identifies. In survey mode the device will attempt to identify all
piconets in a given area and display them after either a timeout or
manual interruption.

Piconet following is the main mode entered when no arguments are passed
to the command or a LAP and optionally a UAP are provided. If no
arguments are passed, the tool will attempt to calculate the UAP for any
observed LAPs. If a LAP is passed, the UAP will be calculated for that
specific LAP. Once a LAP and UAP have been recovered, the tool will
attempt to recover the clock value, and if that succeeds it will follow
that piconet.

Survey mode, entered using `-z`, will record all LAPs and attempt to
calculate the UAPs for any observed LAPs. This mode can be combined with
a timeout using `-t`, and it can be interrupted at any time using
`ctrl-C`.

## EXAMPLES

Follow the first piconet whose LAP, UAP, and clock are recovered from
the air:

    ubertooth-rx

For a given LAP, calculate the UAP and recover the clock, then follow:

    ubertooth-rx -l 112233

For a given LAP and UAP, recover the clock then follow:

    ubertooth-rx -l 112233 -u ab

Enter survey mode for 20 seconds, and print out the BD ADDRs of all
observed piconets:

    ubertooth-rx -z -t 20

## OPTIONS

Major modes:

 - `-l <lap>` :
   Limit UAP recovery, clock recovery, and piconet following to a given
   LAP. Format is 3 bytes / 6 hex characters.

 - `-u <uap>` :
   Limit clock recovery and piconet following to a given UAP. Must be
   used in conjunction with `-l`. Format is 1 byte / 2 hex characters.

 - `-z` :
   Survey mode: recover all LAP and UAP pairs and display them. Will run
   indefinitely until interrupted with `ctrl-C` unless paired with `-t`.

Options:

 - `-i <input>` :
   Input file. If not specified will perform live capture using
   Ubertooth.

 - `-c <0-79>` :
   Fixed channel for all major modes. If not specified will sweep
   through all channels.

 - `-e <0-4>` :
   Maximum access code bit errors. [Default: 2]

 - `-t <seconds>` :
   Timeout in seconds. If not specified will run indefinitely. Suggested
   values for `-z`: 20-60 seconds.

Output options:

 - `-r <file.pcapng>` :
   Capture packets to PcapNG
 - `-q <file.pcap>` :
   Capture packets to PCAP
 - `-d <file.bin>` :
   Capture packets to binary file suitable for use with `-i`.

Miscellaneous:

 - `-V` :
   Version information

 - `-U<0-7>` :
   Which Ubertooth device to use

## DISCOVERING UNDISCOVERABLE DEVICES

Classic Bluetooth piocnets are defined by the Lower Address Part (LAP)
and Upper Address Part (UAP) of the master device. These are elements
of the master device's Bluetooth Address (BD ADDR).

Consider the following BD ADDR:

    22:44:66:88:AA:BB

The lower address part (LAP) is the lower 24 bits, so `88:AA:BB`. In the
context of this tool, the value is written `88AABB`. The upper address
part is the next 8 bits, so `66`. The `22:44` is called the
Non-significant Address Part (NAP) and as you might imagine it is not
significant.

In piconet following mode, the tool will recover LAP values from the air
and attempt to calculate the UAP from those. It will go on to follow the
piconet if it can recover the clock value. In survey mode, the tool will
simply recover LAP and UAP values.

To convert LAP + UAP pairs back into Bluetooth addresses, do the reverse
of the above. For example, if the tool recovers a LAP of 36A2B4 and a
UAP of 98, the associated Bluetooth address is `??:??:98:36:A2:B4`. Any
value can be substituted into the ?? slots and most Bluetooth tools will
still work. For example, `hcitool name 00:00:98:36:A2:B4` will establish
a connection to the device and return its name.

This attack works against discoverable and undiscoverable devices alike.

## SEE ALSO

ubertooth-scan(1): active device scanning and inquiry using Ubertooth
and BlueZ

ubertooth(7): overview of Project Ubertooth

D. Spill and A. Bittau. "BlueSniff: Eve Meets Alice and Bluetooth."
USENIX WOOT 2007.

## AUTHOR

This manual page was written by Mike Ryan.

## COPYRIGHT

ubertooth-rx(1) is Copyright (c) 2010-2017 Michael Ossmann, Dominic
Spill, and others. This tool is released under the GPLv2. Refer to
`COPYING` for further details.

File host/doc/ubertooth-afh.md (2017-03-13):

# UBERTOOTH-AFH 1 "March 2017" "Project Ubertooth" "User Commands"

## NAME

ubertooth-afh(1) - passive detection of AFH channel map

## SYNOPSIS

    ubertooth-afh -u <uap> -l <lap> [-r] [-m <seconds>]

## DESCRIPTION

Classic Bluetooth piconets commonly make use of Adaptive Frequency
Hopping (AFH) to avoid interference with other signals in 2.4 GHz. This
tool attempts to determine the AFH map being used for a given piconet
identified by UAP and LAP.

At a minimum you must provide UAP and LAP. See ubertooth-rx(1) for a
method for sniffing these over the air and details on where else to find
them. By default the tool will only print the AFH map when it is
updated. By providing the `-r` flag, the AFH map will be printed out in
binary form once per second.

## OPTIONS

 - `-l <LAP>` :
   LAP of target piconet (3 bytes / 6 hex digits)
 - `-u <UAP>` :
   UAP of target piconet (1 byte / 2 hex digits)
 - `-m <int>` :
   threshold for channel removal (default: 5)
 - `-r` :
   print AFH channel map once every second (default: print on update)

Other options:

 - `-t <seconds>` :
   timeout for initial AFH map detection (not required)
 - `-e <0-4>` :
   maximum access code errors (default: 2, range: 0-4)
 - `-V` :
   print version information
 - `-U <0-7>` :
   set ubertooth device to use

## SEE ALSO

ubertooth-rx(1): a tool for finding UAP and LAP

ubertooth(7): overview of Project Ubertooth

## AUTHOR

This manual page was written by Mike Ryan.

## COPYRIGHT

ubertooth-afh(1) is Copyright (c) 2015-2017. This tool is released under the
GPLv2. Refer to `COPYING` for further details.

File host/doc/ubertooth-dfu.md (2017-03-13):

# UBERTOOTH-DFU 1 "March 2017" "Project Ubertooth" "User Commands"

## NAME

ubertooth-dfu(1) - Device firmware update for Ubertooth

## SYNOPSIS

To update firmware, run:

    ubertooth-dfu -d bluetooth_rxtx.dfu -r

## DESCRIPTION

ubertooth-dfu(1) is a utility for updating firmware on Ubertooth. It can
also download the currently running firmware from the device.

Running the upload or download command automatically resets the device
into the firmware update bootloader. The USB ID of the Ubertooth will
change in the bootloader, and this may cause problems when attempting to
update firmware from inside a VM.

In the DFU bootloader, the TX, RX, and USR LEDs will turn on and off in
sequence. If this does not occur, you can try to manually force the
device to boot into the bootloader. Refer to [MANUALLY ENTERING
BOOTLOADER][].

## OPTIONS

Major modes:

 - `-d <firmware.dfu>` :
   Download - write DFU file to device
 - `-u <output.dfu>` :
   Upload - read DFU file from device
 - `-r` :
   Reset device after performing operation

Miscellaneous:

 - `-s <file.bin>` :
   Add DFU suffix to binary firmware file
 - `-U <0-7>` :
   Which Ubertooth device to use

## MANUALLY ENTERING BOOTLOADER

If the device does not enter the bootloader when running the upload or
download commands, it is possible to force the device to boot into that
mode when it is inserted. To do so, you will need to jumper two pins on
the expansion header.

The expansion header is a 2x3 pin header between the two largest chips
on the board, about halfway between the USB connector and antenna. It is
labeled "EXPAND" on the back side of the board. Holding the board so USB
is pointed up, on the front side of the board the expansion header looks
like this:

      +-------+
    6 + O | O | 3
      +---+---+
    5 + O | O | 2
      +---+---+
    4 + O | X | 1
      +---+---+

PIN #1, marked X, is square.

With Ubertooth unplugged, use a piece of wire, paperclip, staple, etc to
connect pins 1 and 2 together. When it it plugged in, the Ubertooth
should enter bootloader mode (LEDs will be turning on and off in
sequence).

The bootloader will exit after 5 seconds of no activity and boot into
the main firmware.

## SEE ALSO

ubertooth(7): overview of Project Ubertooth

## AUTHOR

This manual page was written by Mike Ryan.

## COPYRIGHT

ubertooth-dfu(1) is Copyright (c) 2010-2017. This tool is released under
the GPLv2. Refer to `COPYING` for further details.

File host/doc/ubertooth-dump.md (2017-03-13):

# UBERTOOTH-DUMP 1 "March 2017" "Project Ubertooth" "User Commands"

## NAME

ubertooth-dump(1) - output a continuous stream of received bits

## SYNOPSIS

    ubertooth-dump [-b] [-c | -l] [-d <filename.bin>]

## DESCRIPTION

This tool dumps the raw bitstream received from the CC2400 radio to
STDOUT or a file (if specified with `-d`). It can configure the radio to
demodulate Classic Bluetooth with `-c` (default), or Bluetooth Low
Energy (BLE) with `-l`. Optionally it can decode the binary data and
print ASCII 0 and 1 using `-b`.'

## OPTIONS

 - `-b` :
   Print ASCII 0 and 1 instead of raw data
 - `-c` :
   Classic Bluetooth modulation (default)
 - `-l` :
   Bluetooth Low Energy (BLE) modulation
 - `-d <filename.bin>` :
   Dump to file instead of stdout
 - `-U <0-7>` :
   which Ubertooth device to use

## SEE ALSO

ubertooth(7): overview of Project Ubertooth

## AUTHOR

This manual page was written by Mike Ryan.

## COPYRIGHT

ubertooth-dump(1) is Copyright (c) 2010-2017. This tool is released under the
GPLv2. Refer to `COPYING` for further details.

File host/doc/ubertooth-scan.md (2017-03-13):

# UBERTOOTH-SCAN 1 "March 2017" "Project Ubertooth" "User Commands"

## NAME

ubertooth-scan(1) - active(Bluez) device scan and inquiry supported by Ubertooth

## SYNOPSIS

ubertooth-scan [-s] [-x]

## DESCRIPTION

This tool uses a normal Bluetooth dongle to perform Inquiry Scans and
Extended Inquiry scans of Bluetooth devices. It uses Ubertooth to
discover undiscoverable devices and can use BlueZ to scan for
discoverable devices.

## EXAMPLES

Use Ubertooth to discover devices and perform Inquiry Scan with BlueZ:

    ubertooth-scan

Use BlueZ and Ubertooth to discover devices and perform Inquiry Scan and
Extended Inquiry Scan:

    ubertooth-scan -s -x

## OPTIONS

 - `-s` :
   hci Scan - use BlueZ to scan for discoverable devices
 - `-x` :
   eXtended scan - retrieve additional information about target devices
 - `-t <seconds>` :
   scan Time - length of time to sniff packets. [Default: 20s]
 - `-e <0-4>` : 
    Maximum Access Code Errors (default: 2)
 - `-b hciN` :
    Bluetooth device (default: hci0)
 - `-U<0-7>` :
    which Ubertooth device to use

## SEE ALSO

ubertooth-rx(1): Discover devices passively with Ubertooth

ubertooth(7): overview of Project Ubertooth

## AUTHOR

This manual page was written by Mike Ryan.

## COPYRIGHT

ubertooth-scan(1) is Copyright (c) 2010-2017. This tool is released under the
GPLv2. Refer to `COPYING` for further details.

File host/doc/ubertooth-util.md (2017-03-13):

# UBERTOOTH-UTIL 1 "March 2017" "Project Ubertooth" "User Commands"

## NAME

ubertooth-util(1) - general purpose Ubertooth utility

## SYNOPSIS

ubertooth-util [-abcdefghijk-ellemenop-qrstuvwxyZ]

## DESCRIPTION

ubertooth-util(1) is a catch-all tool for doing generally useful things
with, to, and about Ubertooth. To get firmware revision and compile
information, run:

    ubertooth-util -vV

To fully reset Ubertooth, run:

    ubertooth-util -r

Other options are available for modifying LED states, setting channel,
and performing miscellaneous radio-related actions. Refer to the
[OPTIONS][] section for full details.

The utility also includes a simple range test tool for use with two
Uberteeth. Refer to [RANGE TEST][] for full details.

## OPTIONS

Common options:

 - `-v` :
   get firmware revision number
 - `-V` :
   get compile info
 - `-I` :
   identify ubertooth device by flashing all LEDs
 - `-d[0-1]` :
   get/set all LEDs
 - `-l[0-1]` :
   get/set USR LED
 - `-S` :
   stop current operation
 - `-r` :
   full reset
 - `-U<0-7>` :
   set ubertooth device to use

Radio options:

 - `-a[0-7]` :
   get/set power amplifier level
 - `-c[2400-2483]` :
   get/set channel in MHz
 - `-C[0-78]` :
   get/set channel
 - `-q[1-225 (RSSI threshold)]` :
   start LED spectrum analyzer
 - `-t` :
   intitiate continuous transmit test
 - `-z` :
   set squelch level

Range test:

 - `-e` :
   start repeater mode
 - `-m` :
   display range test result
 - `-n` :
   initiate range test

Miscellaneous:

 - `-f` :
   activate flash programming (DFU) mode
 - `-i` :
   activate In-System Programming (ISP) mode
 - `-b` :
   get hardware board id number
 - `-p` :
   get microcontroller Part ID
 - `-s` :
   get microcontroller serial number

## RANGE TEST

Using two Uberteeth it is possible to perform a range test. One
Ubertooth acts as a repeated by running:

    ubertooth-util -e

A second Ubertooth (the sender) initiates the range test by running:

    ubertooth-util -n

During the range test the sender Ubertooth will transmit data packets at
increasing power level, listening for repeats from the repeater
Ubertooth. The receiving Ubertooth will validate that the received data
was not corrupted in flight.

The range test results can be displayed on the sender Ubertooth's system
by running:

    ubertooth-util -m

Note that the range test transmits the Cortex M3 microcontroller's
serial number. If you do not wish to broadcast that information
wirelessly, do not use the range test functionality.

## SEE ALSO

ubertooth(7): overview of Project Ubertooth

## AUTHOR

This manual page was written by Mike Ryan.

## COPYRIGHT

ubertooth-util(1) is Copyright (c) 2010-2017. This tool is released under the
GPLv2. Refer to `COPYING` for further details.

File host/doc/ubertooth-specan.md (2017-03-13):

# UBERTOOTH-SPECAN 1 "March 2017" "Project Ubertooth" "User Commands"

## NAME

ubertooth-specan(1) - a spectrum analyzer for Ubertooth

## SYNOPSIS

ubertooth-specan [-l <freq>] [-u <freq>] [-g|G]

## DESCRIPTION

ubertooth-specan(1) is a tool for using Ubertooth as a spectrum analyzer
in the 2.4GHz band. It is often used as a helper for GUI tools, such as
ubertooth-specan-ui or Spectools. It can also produce output suitable for
user with the feedgnuplot tool.

Other options allow upper and lower bounds to be set on the frequencies
monitored. Refer to the [OPTIONS][] section for full details.

## OPTIONS

Options:

 - `-l` :
   lower frequency (default 2402)
 - `-u` :
   upper frequency (default 2480)
 - `-g` :
   format output for feedgnuplot
 - `-G` :
   format output for 3D feedgnuplot
 - `-d<filename>` :
   output to file <filename>
 - `-v` :
   print verbose output to stderr
 - `-U<0-7>` :
   set ubertooth device to use

##EXAMPLES

To monitor the 2.4GHz band and produce a file suitable for feedgnuplot:

   ubertooth-specan -g -d output.dat

To monitor the upper half of the 2.4GHz band, use:

   ubertooth-specan -l 2440

## SEE ALSO

ubertooth(7): overview of Project Ubertooth

## AUTHOR

This manual page was written by Dominic Spill.

## COPYRIGHT

ubertooth-specan(1) is Copyright (c) 2010-2017. This tool is released under the
GPLv2. Refer to `COPYING` for further details.

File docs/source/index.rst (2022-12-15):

Ubertooth
=====================================

.. toctree::
  :maxdepth: 1
  :caption: User Documentation

  ubertooth_one
  build_guide
  faq
  getting_started
  getting_help
  capturing_BLE_Wireshark
  bluetooth_captures_PCAP
  history
  ubertooth_projects_mentions

.. toctree::
  :maxdepth: 1
  :caption: Software

  building_from_git
  software
  third_party_software

.. toctree::
  :maxdepth: 1
  :caption: Firmware

  firmware
  programming

.. toctree::
  :maxdepth: 1
  :caption: Hardware

  assembling_hardware

.. toctree::
  :maxdepth: 1
  :caption: Release Notes  

  Release_2015-10-R1
  Release_2017_03_R2
  Release_2018-08-R1
  Release_2018-12-R1   

.. toctree::
  :maxdepth: 1
  :caption: Retired Content

  to_do
  release_procedure   
  ubertooth_two_wishlist
  ubertooth_zero

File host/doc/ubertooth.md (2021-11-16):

# UBERTOOTH 7 "March 2017" "Project Ubertooth" "Project Ubertooth Overview"

## NAME

ubertooth(7) - Project Ubertooth

## OVERVIEW

Ubertooth is a platform for Bluetooth experimentation. It is able to
sniff Bluetooth Smart (BLE), discover undiscoverable classic Bluetooth
devices, and perform rudimentary sniffing of classic Bluetooth devices.

Ubertooth is **not** a Bluetooth dongle and it will not show up as one
when running `hciconfig`.

## COMMAND LINE TOOLS

The following command line tools included in this package are the
primary means of using Ubertooth. Refer to their manual pages for
example usage and comprehensive documentation.

Useful commands:

 - ubertooth-btle(1) : BLE sniffing and other fun
 - ubertooth-rx(1) : Classic Bluetooth device discovery and rudimentary sniffing
 - ubertooth-scan(1) : Active scanning of undiscoverable devices
 - ubertooth-afh(1) : Detecting the AFH map of a Classic Bluetooth piconet
 - ubertooth-ego(1) : Yuneec E-Go electric skateboard sniffing

Utility commands:

 - ubertooth-dfu(1) : Firmware update tool
 - ubertooth-dump(1) : Dumping raw RF symbols to disk
 - ubertooth-util(1) : "Everything else"

Less useful commands:

 - ubertooth-debug(1) : Peeking and poking registers on the CC2400
 - ubertooth-specan(1) : Raw RSSI values used by graphical specan

## SUPPORT

Ubertooth is an open source project maintained primarily by volunteers.
Please keep that in mind when seeking support.

If you are having issues with a tool or believe you have found a bug,
please file an issue on the project GitHub:
<https://github.com/greatscottgadgets/ubertooth>

For interactive support, join the `#ubertooth` channel on Discord:
<https://discord.gg/rsfMw3rsU8>

## COPYRIGHT

The code and documentation for Project Ubertooth are Copyright 2010-2017
and are available under the terms of the GPLv2. Refer to `COPYING` for
details. Ubertooth is a registered trademark of Great Scott Gadgets.

## AUTHOR

This manual page was written by Mike Ryan.

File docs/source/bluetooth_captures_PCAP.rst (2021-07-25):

==========================
Bluetooth Captures in PCAP
==========================

Overview
~~~~~~~~

Classic PCAP files store a sequence of packets of a single link type. Published link types are `here <http://www.tcpdump.org/linktypes.html>`__. The `pcapng <http://www.winpcap.org/ntar/draft/PCAP-DumpFileFormat.html>`__ format also uses these same link types and the per-packet formatting as PCAP.

Early versions of libbtbb and ubertooth saved PCAP files with the DLT_PPI format, which was expedient but is considered deprecated by the libpcap folks. Best practice is to allocate a DLT for a particular link-layer and define a pseudo-header for that DLT that precedes each packet in the file. Early versions of this article formed a place to collect such a proposal. Now that the DLTs are allocated, and this article serves to collect implementation alternatives and details.

It was possible, and somewhat consistent with DLT_BLUETOOTH_HCI_H4_WITH_PHDR, to allocate a single DLT_BLUETOOTH_LOW_LEVEL to indicate any Bluetooth capture (BR/EDR or LE). However, the preference was to have separate DLT's for BR/EDR baseband and LE link-layer (as per the terms used in the Bluetooth spec).

Since PCAP has general applicability to packet capture, it made sense to provide a vendor-neutral, generic view of Bluetooth capture. The allocated DLTs can be applied to current and future versions of both ubertooth and gr-bluetooth, and potentially other RF capture tools as well. 

Aspects of Bluetooth Capture
~~~~~~~~~~~~~~~~~~~~~~~~~~~~

Sometimes we want to capture and record malformed, truncated, or garbled packets along with ostensibly valid or pristine ones. We also want to capture packets when some link parameters are unknown. When operating promiscuously, the capture tool may accept noise bursts as candidate Bluetooth packets. In extreme cases, the capture tool may not even de-whiten the packets, preferring to do that as a post-processing step. It was therefore important to include some of the receiver metrics in the capture metadata so post-processing and display tools like Wireshark can easily filter out unwanted packets, or avoid redundantly checking packet integrity when it's already known.

Five areas of receiver metadata were contemplated to assist in packet classification:

    #. signal and noise strength

    #. flags and metrics on the validity of unprotected fields (BR sync word, LE access address)

    #. error-correction on BR/EDR when subject to FEC

    #. whether all or portions of the packet is de-whitened

    #. packet-level error-checking already performed at capture (CRC, HEC, MIC)

Since the current ubertooth can recover BR and LE packets, but not EDR payloads, there was also a need to indicate whether the EDR data is present in the packet capture. 

Capture Use Cases Summarized
~~~~~~~~~~~~~~~~~~~~~~~~~~~~

The following use cases apply to both full-band and narrowband capture strategies. There are no particular restrictions imposed under full-band captures. However, for a narrowband captures (e.g. Ubertooth):

    * learning implies the tool transitions from receiving a static channel, or surveying channels, to following particular hop sequence(s), and

    * limited hop sequence(s) (piconets/access addresses) may be followed at a given time.

Hybrid captures are also supported by these use cases and capture formats. For example, one may configure several narrowband (e.g. Ubertooth) or partial-band (e.g. gr-bluetooth) captures, on static channels, and perform post-processing on the set of capture files (either PCAP or PCAPNG). A similar hybrid arrangement is possible to post-process several narrowband capture tools following different hop sequences.

Use cases involving encryption are TBD. 

BR/EDR
^^^^^^

.. list-table ::
  :header-rows: 1
  :widths: 1 1 1 1 1 1 1

  * - Name 	
    - Description 	
    - Comments 	
    - Packets De-whitened? 	
    - Reference LAP 	
    - Reference UAP 	
    - HEC/CRC checking
  * - Promiscuous capture without learning 	
    - All packets that meet the configured RF criteria (e.g. signal strength or SNR), and meet the configured criteria for access-code offenses (e.g. preamble, trailer must be valid), are decoded and stored in the capture file. 	
    - Either PCAP or PCAPNG is equally useful. Capture file may be very large. Post-processing necessary to recover UAP per LAP, and CLK per LAP/UAP, and filter packets of interest. 	
    - No 	
    - Invalid 	
    - Invalid 	
    - No
  * - Promiscuous capture with learning 	
    - Initially operates as above, but as capture tool recovers LAPs, and the associated UAP, and CLK parameters, it is able to perform more processing per packet. 	
    - PCAP or PCAPNG may be used, but the latter is more useful since it includes a record of the capture tool's learning process. Post-processing similar to above may back-annotate, de-whiten, and integrity-check packets captured before the parameters were learned. Essentially, the post-processing mentioned above is split between capture-time and post-capture-time. 	
    - Initially no, later yes 	
    - Initially invalid, later known 	
    - Initially invalid, later known 	
    - Initially no, later optionally performed
  * - Capture of targeted LAPs, with and without learning 	
    - Only captures packets with an access code that includes the targeted LAPs, with a configured tolerance for access code bit errors. The capture tool may or may not attempt to learn the UAP and CLK parameters per configured LAP. 	
    - This is simply a stricter version of the promiscuous captures, where the access code triggering capture is targeted, resulting in a much smaller capture file for the same traffic pattern. Whether the capture tool learns or not, post-processing is useful to back-annotate, modify, and filter packets. 	
    - Initially no, later yes with learning 	
    - Valid 	
    - Initially invalid, later known with learning 	
    - Initially no, later optionally performed with learning
  * - Capture of targeted LAP/UAPs, with and without learning 	
    - Operates as above, except the configured LAP/UAPs are used for all packet capture processing. The capture tool may or may not attempt to learn the CLK alignment per LAP/UAP. 	
    - This is an accelerated version of targeted LAPs, where the associated UAP is not learned. 	
    - Initially no, later yes with learning 	
    - Valid 	
    - Valid 	
    - Initially no, later optionally performed with learning
  * - Capture of known master devices 	
    - Operates as above, except the master devices' internal state (BD_ADDR, CLK) is known at capture time. 	
    - There is no need to passively learn any piconet parameters. 	
    - Yes 	
    - Valid 	
    - Valid 	
    - Optionally performed 

LE
^^^

.. list-table :: 
  :header-rows: 1
  :widths: 1 1 1 1 1 1 

  * - Name 	
    - Description 	
    - Comments 	
    - Packets De-whitened? 	
    - Reference AA 	
    - CRC checking
  * - Promiscuous capture without learning 	
    - All packets that meet the configured RF criteria (e.g. signal strength or SNR), and meet the configured criteria for access address offenses (e.g. preamble must be valid, access address must be well-formed), are stored in the capture file. The captured packets are optionally de-whitened. 	
    - Either PCAP or PCAPNG is equally useful. Capture file may be very large. Post-processing necessary to recover connection parameters, and filter packets of interest. 	
    - Optional 	
    - Valid for Advertising channels only 	
    - Optionally performed for Advertising channels only
  * - Promiscuous capture with learning 	
    - Initially operates as above, except access addresses are learned by the capture tool, e.g. by accumulating candidates on Data channels or processing CONNECT_REQ PDUs on Advertising channels. 	
    - Access addresses learned by profiling Data channels cannot be CRC-checked, because the CRCInit parameter is unknown. 	
    - Yes (but optional) 	
    - Initially valid for Advertising channels only, but later valid for Data channels as access addresses are learned 	
    - Optionally performed for Advertising channels or Data channels where CRCInit is known for the access address
  * - Targeted capture 	
    - Specific BD_ADDRs are selected, and the associated access addresses are whitelisted for capture when data from a CONNECT_REQ PDU involving those BD_ADDRs is processed 	
    - The contents of the CONNECT_REQ PDU may be found by capturing Advertising channels or configured into the capture tool directly. 	
    - Yes (but optional) 	
    - Valid 	
    - Optionally performed 

Session Meta Information (Proposed)
~~~~~~~~~~~~~~~~~~~~~~~~~~~~~~~~~~~

Often there is meta-information that is recovered during the Bluetooth air capture, during post-processing, or provided out-of-band. Here we enumerate `PCAPNG options <http://www.winpcap.org/ntar/draft/PCAP-DumpFileFormat.html#sectionopt>`__ for use within the `interface description block <http://www.winpcap.org/ntar/draft/PCAP-DumpFileFormat.html#sectionidb>`__ for Bluetooth captures.

Some of these session-oriented data have time-windows that bound their applicability. A timestamp pair is used to define such a window. Timestamps are stored in same precision as indicated in ts_resol field of the `capture interface <http://www.winpcap.org/ntar/draft/PCAP-DumpFileFormat.html#sectionidb>`__. When both timestamps are equal (e.g. both zero), the meta-datum applies for the entire capture session.

PCAPNG options with MSB set are available for local use. We simply state that the interface options enumerated below are local to the DLTs allocated for Bluetooth RF captures. The most-significant byte for all interface option codes below is 0xd3, which was selected as unlikely to conflict with other local interface options that might be in use in PCAPNG generally. The ranges of least-significant bytes allocated below to option codes are: general Bluetooth is 0x0-0x3f, BR/EDR is 0x40-0x7f, and LE is 0x80-0xbf, with 0xc0-0xff reserved. 

BREDR_BD_ADDR
^^^^^^^^^^^^^

This record provides Bluetooth device addresses (BD_ADDRs) that may be present in the packet capture. BD_ADDRs are useful in post-processing or display tools to provide unique identification of the devices involved in piconet communication.

Device addresses may be recovered by the capture tool or provided by the user as a parameter to the capture session. In either case, this BREDR_BD_ADDR record may appear in the PCAPNG capture file.

When recovered by the capture tool, the UAP may be partly recovered by determining the channel hop sequence. Only the 4 least-significant bits of the UAP are used in hop-sequence determination. UAPs are also used in the BR/EDR Header Error Check, and payload Cyclic Redundancy Check generation, and may be recovered by accumulating candidates from the captured Bluetooth packets. In these cases, the UAP recorded may be masked to indicate which bits are known with certainty.

The UAP and NAP are available in the clear as fields within the FHS Packet. When captured directly, or when provided as a capture session parameter, the UAP and NAP may be recorded with certainty (all mask bits set).

The capture tool may store multiple records for the same BD_ADDR, as long as subsequent records indicate more certainty in the known UAP bits or add a known NAP. This sort of situation might occur if a capture tool starts out without knowing any UAP bits, then determines some UAP bits from hop-sequence following, more UAP bits from HEC and CRC prediction, and finally the full BD_ADDR contents after capturing an applicable FHS packet. 

Option Structure
++++++++++++++++

::

	 0                   1                   2                   3
	 0 1 2 3 4 5 6 7 8 9 0 1 2 3 4 5 6 7 8 9 0 1 2 3 4 5 6 7 8 9 0 1
	+-+-+-+-+-+-+-+-+-+-+-+-+-+-+-+-+-+-+-+-+-+-+-+-+-+-+-+-+-+-+-+-+
	|            0xd340             |               8               |
	+-+-+-+-+-+-+-+-+-+-+-+-+-+-+-+-+-+-+-+-+-+-+-+-+-+-+-+-+-+-+-+-+
	|                    LAP                        |      UAP      |
	+-+-+-+-+-+-+-+-+-+-+-+-+-+-+-+-+-+-+-+-+-+-+-+-+-+-+-+-+-+-+-+-+
	|              NAP              |   UAP_mask    |   NAP_valid   |
	+-+-+-+-+-+-+-+-+-+-+-+-+-+-+-+-+-+-+-+-+-+-+-+-+-+-+-+-+-+-+-+-+

Description
+++++++++++

The option code and length are expressed in the native endianness used by PCAPNG. All multi-octet fields defined below are expressed in little-endian format.

The **LAP** field is the Lower Address Part of the the Bluetooth device address, as per Bluetooth spec Volume 2, Part B, Section 1.2.

The **UAP** field is the Upper Address Part of the the Bluetooth device address, as per Bluetooth spec Volume 2, Part B, Section 1.2.

The **NAP** field is the Network Address Part of the the Bluetooth device address, as per Bluetooth spec Volume 2, Part B, Section 1.2.

The **UAP_mask** field has its bits set to indicate which bits of the UAP are known with certainty.

The **NAP_valid** field is a flag in the least-significant bit that indicates whether the NAP field is populated with valid data. All other bits of this field are reserved and must be zero. 

C Structure
+++++++++++

::

	typedef struct _brder_bdaddr {
	        uint8_t  LAP[3];
	        uint8_t  UAP;
	        uint16_t NAP;
	        uint8_t  UAP_mask;
	        uint8_t  NAP_valid;
	} bredr_bdaddr;

BREDR_CLK 
^^^^^^^^^

This record provides Bluetooth Clock alignment information. The alignment timestamp used in this record is the same precision as the PCAPNG interface header indicates.

Some capture tools estimate the master device clock by inspecting packets and building confidence in the estimate. This record provides a mask that has bits set for known master clock bits. This distinguishes known bits from unknown bits as the master clock estimate improves. Consequently, multiple BREDR_CLK records may appear in the PCAPNG capture file for the same LAP/UAP, provided that subsequent entries offer a better estimate of the device clock.

The information record may be formed as a result of capturing a Bluetooth FHS packet, in which case the CLK_mask should indicate all CLK bits are known. 

Option Structure
++++++++++++++++

::

	 0                   1                   2                   3
	 0 1 2 3 4 5 6 7 8 9 0 1 2 3 4 5 6 7 8 9 0 1 2 3 4 5 6 7 8 9 0 1
	+-+-+-+-+-+-+-+-+-+-+-+-+-+-+-+-+-+-+-+-+-+-+-+-+-+-+-+-+-+-+-+-+
	|            0xd341             |              20               |
	+-+-+-+-+-+-+-+-+-+-+-+-+-+-+-+-+-+-+-+-+-+-+-+-+-+-+-+-+-+-+-+-+
	|                                                               |
	|                      alignment timestamp                      |
	|                                                               |
	+-+-+-+-+-+-+-+-+-+-+-+-+-+-+-+-+-+-+-+-+-+-+-+-+-+-+-+-+-+-+-+-+
	|                    LAP                        |      UAP      |
	+-+-+-+-+-+-+-+-+-+-+-+-+-+-+-+-+-+-+-+-+-+-+-+-+-+-+-+-+-+-+-+-+
	|                              CLK                              |
	+-+-+-+-+-+-+-+-+-+-+-+-+-+-+-+-+-+-+-+-+-+-+-+-+-+-+-+-+-+-+-+-+
	|                            CLK_mask                           |
	+-+-+-+-+-+-+-+-+-+-+-+-+-+-+-+-+-+-+-+-+-+-+-+-+-+-+-+-+-+-+-+-+

Description
+++++++++++

The option code and length are expressed in the native endianness used by PCAPNG. All multi-octet fields defined below are expressed in little-endian format.

The **Alignment Timestamp** is a PCAPNG-resolution timestamp that serves as a reference point for **CLK** associated with the Bluetooth master device referenced by **LAP** and **UAP**.

The **LAP** field is the Lower Address Part of the the Bluetooth device address, as per Bluetooth spec Volume 2, Part B, Section 1.2.

The **UAP** field is the Upper Address Part of the the Bluetooth device address, as per Bluetooth spec Volume 2, Part B, Section 1.2.

The **CLK** field is the native clock of the Bluetooth device, with bits 0-1 and bits 28-31 always zero.

The **CLK_mask** field determines which bits of **CLK** are valid, with bits 0-1 and bits 28-31 always zero. 

C Structure
+++++++++++

::

	typedef struct _brder_bdaddr {
	        uint64_t ns;
	        uint8_t  LAP[3];
	        uint8_t  UAP;
	        uint32_t CLK;
	        uint32_t CLK_mask;
	} bredr_bdaddr;

BT_WIDEBAND_RF_INFO 
^^^^^^^^^^^^^^^^^^^
Some capture tools, e.g. gr-bluetooth, allow for intentional aliasing such that multiple Bluetooth channels appear as superimposed images within a relatively narrow baseband.

Here we define a generic wideband RF information structure so aliasing conditions may be recorded in the PCAPNG capture file.

A post-processing or display tool might use this information to indicate the set of possible RF channels ascribed to each captured packet. BT_WIDEBAND_RF_INFO only applies to packets captured under the applicable interface, where the packet's Flags field indicates the RF channel was subject to aliasing. 

Option Structure
++++++++++++++++

::

	 0                   1                   2                   3
	 0 1 2 3 4 5 6 7 8 9 0 1 2 3 4 5 6 7 8 9 0 1 2 3 4 5 6 7 8 9 0 1
	+-+-+-+-+-+-+-+-+-+-+-+-+-+-+-+-+-+-+-+-+-+-+-+-+-+-+-+-+-+-+-+-+
	|            0xd300             |              16               |
	+-+-+-+-+-+-+-+-+-+-+-+-+-+-+-+-+-+-+-+-+-+-+-+-+-+-+-+-+-+-+-+-+
	|                   centre frequency in Hz                      |
	+-+-+-+-+-+-+-+-+-+-+-+-+-+-+-+-+-+-+-+-+-+-+-+-+-+-+-+-+-+-+-+-+
	|                   analog bandwidth in Hz                      |
	+-+-+-+-+-+-+-+-+-+-+-+-+-+-+-+-+-+-+-+-+-+-+-+-+-+-+-+-+-+-+-+-+
	|                 intermediate frequency in Hz                  |
	+-+-+-+-+-+-+-+-+-+-+-+-+-+-+-+-+-+-+-+-+-+-+-+-+-+-+-+-+-+-+-+-+
	|                  sampling bandwidth in Hz                     |
	+-+-+-+-+-+-+-+-+-+-+-+-+-+-+-+-+-+-+-+-+-+-+-+-+-+-+-+-+-+-+-+-+

Description
+++++++++++

The option code and length are expressed in the native endianness used by PCAPNG. All multi-octet fields defined below are expressed in little-endian format.

The **Centre Frequency** field determines the centre of the RF capture, in Hz.

The **Analog Bandwidth** field determines the passband width of the analog section employed in the capture tool. It is measured from band centre to the band edge, in Hz.

The **Intermediate Frequency** field determines the intermediate carrier frequency used in the analog receiver, relative to the **Centre Frequency**, in Hz.

The **Sampling Bandwidth** field determines the digital sampling bandwidth employed in the capture tool, in Hz. 

C Structure
+++++++++++

::

	typedef struct _bt_wideband_rf_info {
	        uint32_t centre_freq_hz;
	        uint32_t analog_bw_hz;
	        int32_t  intermediate_freq_hz;
	        uint32_t sampling_bw_hz;
	} bt_wideband_rf_info;

LE_LL_CONNECTION_INFO 
^^^^^^^^^^^^^^^^^^^^^

This record provides context for a BTLE connection so that a post-processor or display tool may perform a more in-depth packet analysis. The following fields may be applied:

    * InitA, the initiator's public or random device address, may be used to connect packets with a device.

    * AdvA, the advertiser's public or random device address, may be used to connect packets with a device.

    * AA, the access address, connects a given LE packet to the rest of the data in this record (since all LE packets contain an AA field).

    * CRCInit, the 24-bit LFSR initial value, may be used to verify per-packet CRC integrity.

    * WinSize, WinOffset, Interval, and Latency may be used to verify adherence to RF transmission rules.

    * Timeout may be used to infer connection loss when packets are absent.

    * ChM, the allowable RF channel map, and Hop, may be used to verify the RF hop sequence.

The format of this record matches the CONNECT_REQ PDU used in the LE link layer. It is anticipated records of this nature would accrue in the capture file as follows:

    #. when a CONNECT_REQ PDU is captured, a record is stored with the PDU contents, and the capture tool considers the values current for the indicated AA.

    #. when a LL_CONNECTION_UPDATE_REQ PDU is captured after a CONNECT_REQ PDU, for the same AA:

        #. a new record is created, updating the WinSize, WinOffset, Interval, Latency, and Timeout fields.

        #. the valid-from timestamp is determined by the Instant parameter of the LL_CONNECTION_UPDATE_REQ PDU.

        #. the other parameters in this record are populated with those values already considered current.

        #. at the indicated instant, capture tool considers the updated values current for the indicated AA.

    #. when a LL_CHANNEL_MAP_REQ PDU is captured after a CONNECT_REQ PDU, for the same AA:

        #. a new record is created, updating the ChM field.

        #. the valid-from timestamp is determined by the Instant parameter of the LL_CHANNEL_MAP_REQ PDU.

        #. the other parameters in this record are populated with those values already considered current.

        #. at the indicated instant, capture tool considers the updated ChM current for the indicated AA.

It is noted that an LE packet capture may contain all the information necessary to synthesize these records. Therefore, these records may be created during capture or afterwards, as a post-processing step. In the latter case, a classic PCAP file may be converted to PCAPNG. 

Option Structure
++++++++++++++++

::

	 0                   1                   2                   3
	 0 1 2 3 4 5 6 7 8 9 0 1 2 3 4 5 6 7 8 9 0 1 2 3 4 5 6 7 8 9 0 1
	+-+-+-+-+-+-+-+-+-+-+-+-+-+-+-+-+-+-+-+-+-+-+-+-+-+-+-+-+-+-+-+-+
	|            0xd380             |              42               |
	+-+-+-+-+-+-+-+-+-+-+-+-+-+-+-+-+-+-+-+-+-+-+-+-+-+-+-+-+-+-+-+-+
	|                                                               |
	|                    valid from timestamp                       |
	|                                                               |
	+-+-+-+-+-+-+-+-+-+-+-+-+-+-+-+-+-+-+-+-+-+-+-+-+-+-+-+-+-+-+-+-+
	|                                                               |
	|            InitA              +-+-+-+-+-+-+-+-+-+-+-+-+-+-+-+-+
	|                               |                               |
	+-+-+-+-+-+-+-+-+-+-+-+-+-+-+-+-+             AdvA              |
	|                                                               |
	+-+-+-+-+-+-+-+-+-+-+-+-+-+-+-+-+-+-+-+-+-+-+-+-+-+-+-+-+-+-+-+-+
	|                              AA                               |
	+-+-+-+-+-+-+-+-+-+-+-+-+-+-+-+-+-+-+-+-+-+-+-+-+-+-+-+-+-+-+-+-+
	|                     CRCInit                   |    WinSize    |
	+-+-+-+-+-+-+-+-+-+-+-+-+-+-+-+-+-+-+-+-+-+-+-+-+-+-+-+-+-+-+-+-+
	|            WinOffset          |           Interval            |
	+-+-+-+-+-+-+-+-+-+-+-+-+-+-+-+-+-+-+-+-+-+-+-+-+-+-+-+-+-+-+-+-+
	|             Latency           |           Timeout             |
	+-+-+-+-+-+-+-+-+-+-+-+-+-+-+-+-+-+-+-+-+-+-+-+-+-+-+-+-+-+-+-+-+
	|                                                               |
	|    ChM        +-+-+-+-+-+-+-+-+-+-+-+-+-+-+-+-+-+-+-+-+-+-+-+-+
	|               |   Hop+SCA     |             pad               |
	+-+-+-+-+-+-+-+-+-+-+-+-+-+-+-+-+-+-+-+-+-+-+-+-+-+-+-+-+-+-+-+-+

Description
+++++++++++

The definition of the fields are found in the Bluetooth specification Volume 6, Part B, Sections 2.3.3.1, 2.4.2.1, and 2.4.2.2. 

C Structure
+++++++++++

::

	typedef struct _le_ll_connection_info {
	        uint64_t valid_from_ts;
	        uint8_t  InitA[6];
	        uint8_t  AdvA[6];
	        uint32_t AA;
	        uint8_t  CRCInit[3];
	        uint8_t  WinSize;
	        uint16_t WinOffset;
	        uint16_t Interval;
	        uint16_t Latency;
	        uint16_t Timeout;
	        uint8_t  ChM[5];
	        uint8_t  HopAndSCA;
	} le_ll_connection_info;

Under Development
^^^^^^^^^^^^^^^^^

* BR/EDR

    * link-key info: link-key (16 bytes) + 2 BR_ADDR (12 bytes) + 2 timestamps (16 bytes)

    * E0 encryption info: BR_ADDR (6 bytes) + 2 timestamps (16 bytes) + keylen (1 bytes) + key (N bytes)

    * AES-CCM session info: session key (16 bytes) + nonce (13 bytes) + BR_ADDR (6 bytes) + 2 timestamps (16 bytes)

* LE

    * AES-CCM session info: session key (16 bytes) + nonce (13 bytes) + AA (4 bytes) + 2 timestamps (16 bytes)

Allocated DLTs
~~~~~~~~~~~~~~

Common to the following pseudoheaders:

    * mandatory fields:

        * a rf_channel field, although channels differ between BR/EDR and LE.

        * a flags field that indicates which optional fields are present, and other boolean metadata.

    * optional fields:

        * signal power and noise power, probably used by more sophisticated capture tools.

The remaining fields are specific to the BR/EDR and LE capture process, including the packet quality indicators mentioned above. 

LINKTYPE_BLUETOOTH_BREDR_BB 
^^^^^^^^^^^^^^^^^^^^^^^^^^^

* only covers BR/EDR baseband packets, Bluetooth spec Vol.2 Part B.

* each packet includes a packed pseudoheader described below, optionally followed by the decoded BR/EDR baseband PAYLOAD.

    * here decoded is used in the same sense as Bluetooth spec Vol 2 Part B Section 7.

    * BR/EDR PAYLOAD formats are described in Bluetooth spec Vol 2 Part B Section 6.1 and 6.6.

* the packet SYNC WORD (sec 6.3) is not stored, rather the LAP is recovered and stored in the pseudoheader.

* the packet HEADER (sec 6.4) is decoded and stored in the pseudoheader.

* further downstream receiver processing may or may not be performed on the PAYLOAD.

    * refer to figure 7.2 of Bluetooth spec Vol 2 Part B.

    * de-whitening, CRC checking, decryption, and MIC checking, are optional.

    * flags in the pseudo-header indicate which of these have been performed.

    * none of these optional processing steps affect the length of the stored packet PAYLOAD.

Packet Structure
++++++++++++++++

::

	+---------------------------+
	|         RF Channel        |
	|         (1 Octet)         |
	+---------------------------+
	|        Signal Power       |
	|         (1 Octet)         |
	+---------------------------+
	|        Noise Power        |
	|         (1 Octet)         |
	+---------------------------+
	|    Access Code Offenses   |
	|         (1 Octet)         |
	+---------------------------+
	|   Payload Transport Rate  |
	|         (1 Octet)         |
	+---------------------------+
	|   Corrected Header Bits   |
	|         (1 Octet)         |
	+---------------------------+
	|  Corrected Payload Bits   |
	|        (2 Octets)         |
	+---------------------------+
	|    Lower Address Part     |
	|        (4 Octets)         |
	+---------------------------+
	|       Reference LAP       |
	|        (3 Octets)         |
	+---------------------------+
	|       Reference UAP       |
	|         (1 Octet)         |
	+---------------------------+
	|     BT Packet Header      |
	|        (4 Octets)         |
	+---------------------------+
	|          Flags            |
	|        (2 Octets)         |
	+---------------------------+
	|    BR or EDR Payload      |
	.                           .
	.                           .
	.                           .

Description
+++++++++++

All multi-octet fields are expressed in little-endian format. Fields with a corresponding **Flags** bit are only considered valid when the bit is set.

The **RF Channel** field ranges 0 to 78. It reflects the value described in the Bluetooth specification Volume 2, Part A, Section 2.

The **Signal Power** and **Noise Power** fields are signed integers expressing values in dBm.

The **Access Code Offenses** field is an unsigned integer indicating the number of deviations from the valid access code that led to the packet capture. Access codes are interpreted as described in Bluetooth specification Volume 2, Part B, Section 6.3.

The **Payload Transport Rate** field represents a column of Bluetooth specification Volume 2, Part B, Section 6.5, Table 6.2, and is interpreted as two nibbles as follows.

    * 0x.0 indicates the BT payload was BR and captured with GFSK demodulation

    * 0x.1 indicates the BT payload was EDR and captured with PI/2-DQPSK demodulation

    * 0x.2 indicates the BT payload was EDR and captured with 8DPSK demodulation

    * 0x0. indicates the packet logical transport is any (link parameters unknown)

    * 0x1. indicates the packet logical transport is SCO

    * 0x2. indicates the packet logical transport is eSCO

    * 0x3. indicates the packet logical transport is ACL

    * 0x4. indicates the packet logical transport is CSB

    * 0xff indicates this is an ID packet so BT Packet Header is ignored and there is no payload

All other values of the **Payload Transport Rate** field are reserved.

The **Corrected Header Bits** field is an unsigned integer indicating the number of corrected bits in the 18-bit **BT Packet Header**. The valid range is 0 to 18.

The **Corrected Payload Bits** field is a signed integer indicating the number of errored and corrected bits in the captured BT payload. Interpretation of this field corresponds to the **Payload Transport Rate**. The value ranges from 0 to 80 when the BT payload was captured at R=1/3 as per Bluetooth specification Volume 2, Part B, Section 7.4. The value ranges from -360 to +180 when the BT payload was captured at R=2/3 as per Bluetooth specification Volume 2, Part B, Section 7.5. A negative number indicates the field absolute value is the sum of the number of corrected and uncorrectable bits.

The **Lower Address Part** field is the 24-bit value recovered from the captured SYNC WORD as defined in Bluetooth specification Volume 2, Part B, Section 6.3.3. The most significant byte of this field is reserved and must be zero.

The **Reference LAP** field corresponds to the **Lower Address Part** configured into the capture tool that led to the capture of this packet.

The **Reference UAP** field corresponds to the **Upper Address Part** configured into the capture tool and corresponds to the **Reference LAP**.

The **BT Packet Header** field is the 18-bit value recovered from the packet capture, and is defined in Bluetooth specification Volume 2, Part B, Section 6.4. The most significant 14 bits are reserved and must be zero.

The **Flags** field represents packed bits defined as follows.

    * 0x0001 indicates the **BT Packet Header** and **BR or EDR Payload** are de-whitened.

    * 0x0002 indicates the **Signal Power** field is valid.

    * 0x0004 indicates the **Noise Power** field is valid.

    * 0x0008 indicates the **BR or EDR Payload** is decrypted

    * 0x0010 indicates the **Reference LAP** is valid and led to this packet being captured

    * 0x0020 indicates the **BR or EDR Payload** is present and follows this field

    * 0x0040 indicates the **RF Channel** field is subject to aliasing

    * 0x0080 indicates the **Reference UAP** field is valid for HEC and CRC checking

    * 0x0100 indicates the HEC portion of the **BT Packet Header** was checked

    * 0x0200 indicates the HEC portion of the **BT Packet Header** passed its check

    * 0x0400 indicates the CRC portion of the **BR or EDR Payload** was checked

    * 0x0800 indicates the CRC portion of the **BR or EDR Payload** passed its check

    * 0x1000 indicates the MIC portion of the decrypted **BR or EDR Payload** was checked

    * 0x2000 indicates the MIC portion of the decrypted **BR or EDR Payload** passed its check

All other bit positions of the **Flags** field are reserved and must be zero.

The decoded **BR or EDR Payload** optionally follows the previous fields, and is formatted as detailed in Bluetooth specification Volume 2, Part B, Section 6. The packet is decoded per Bluetooth specification Volume 2, Part B, Section 7. All multi-octet values in the **BR or EDR Payload** are always expressed in little-endian format, as is the normal Bluetooth practice. 

C Structure
+++++++++++

::

	typedef struct _pcap_bluetooth_bredr_bb_header {
	        uint8_t rf_channel;
	        int8_t signal_power;
	        int8_t noise_power;
	        uint8_t access_code_offenses;
	        uint8_t payload_transport_rate;
	        uint8_t corrected_header_bits; 
	        int16_t corrected_payload_bits;
	        uint32_t lap;
	        uint32_t ref_lap_uap;
	        uint32_t bt_header;
	        uint16_t flags;
	        uint8_t  br_edr_payload[0];
	} pcap_bluetooth_bredr_bb_header;

LINKTYPE_BLUETOOTH_LE_LL_WITH_PHDR 
^^^^^^^^^^^^^^^^^^^^^^^^^^^^^^^^^^

* supplements DLT_BLUETOOTH_LE_LL which already exists but is not used for RF captures.

* only covers LE link layer packets, Bluetooth spec Vol.6 Part B.

* each packet includes a packed pseudoheader described below, followed by the LE link-layer packet consisting of ACCESS ADDRESS, PDU, and CRC, but excluding the PREAMBLE.

    * reference Bluetooth spec Vol.6 Part B sec 2 for formatting.

* not all receiver processing need be performed at capture time.

    * refer to figures 3.1 of Bluetooth spec Vol 6 Part B.

    * de-whitening, CRC checking, decryption, and MIC checking, are optional.

    * flags in the pseudo-header indicate which of these have been performed.

    * none of these optional processing steps affect the length of the stored packet data.

Packet Structure
++++++++++++++++

::

	+---------------------------+
	|         RF Channel        |
	|         (1 Octet)         |
	+---------------------------+
	|        Signal Power       |
	|         (1 Octet)         |
	+---------------------------+
	|        Noise Power        |
	|         (1 Octet)         |
	+---------------------------+
	|  Access Address Offenses  |
	|         (1 Octet)         |
	+---------------------------+
	| Reference Access Address  |
	|        (4 Octets)         |
	+---------------------------+
	|          Flags            |
	|        (2 Octets)         |
	+---------------------------+
	|  LE Packet (no preamble)  |
	.                           .
	.                           .
	.                           .

Description
+++++++++++

All multi-octet fields are expressed in little-endian format. Fields with a corresponding **Flags** bit are only considered valid when the bit is set.

The **RF Channel** field ranges 0 to 39. It reflects the value described in the Bluetooth specification Volume 6, Part A, Section 2.

The **Signal Power** and **Noise Power** fields are signed integers expressing values in dBm.

The **Access Address Offenses** field is an unsigned integer indicating the number of deviations from the valid access address that led to the packet capture. Access addresses are interpreted as described in Bluetooth specification Volume 6, Part B, Section 2.1.2.

The **Reference Access Address** field corresponds to the Access Address configured into the capture tool that led to the capture of this packet.

The **Flags** field represents packed bits defined as follows.

    * 0x0001 indicates the **LE Packet** is de-whitened.

    * 0x0002 indicates the **Signal Power** field is valid.

    * 0x0004 indicates the **Noise Power** field is valid.

    * 0x0008 indicates the **LE Packet** is decrypted.

    * 0x0010 indicates the **Reference Access Address** is valid and led to this packet being captured.

    * 0x0020 indicates the **Access Address Offenses** field contains valid data.

    * 0x0040 indicates the **RF Channel** field is subject to aliasing.

    * 0x0400 indicates the CRC portion of the **LE Packet** was checked.

    * 0x0800 indicates the CRC portion of the **LE Packet** passed its check.

    * 0x1000 indicates the MIC portion of the decrypted **LE Packet** was checked.

    * 0x2000 indicates the MIC portion of the decrypted **LE Packet** passed its check.

All other bit positions of the **Flags** field are reserved and must be zero.

The **LE Packet** follows the previous fields, and is formatted as detailed in Bluetooth specification Volume 6, Part B, Section 2, but does not include the preamble. All multi-octet values in the **LE Packet** are always expressed in little-endian format, as is the normal Bluetooth practice. 

C Structure
+++++++++++

::

	typedef struct _pcap_bluetooth_le_ll_header {
	        uint8_t rf_channel;
	        int8_t signal_power;
	        int8_t noise_power;
	        uint8_t access_address_offenses;
	        uint32_t ref_access_address;
	        uint16_t flags;
	        uint8_t le_packet[0];
	} pcap_bluetooth_le_ll_header;

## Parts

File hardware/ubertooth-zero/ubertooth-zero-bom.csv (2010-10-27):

Reference Designator | Manufacturer | Manufacturer Part Number | Description | Supplier | Supplier Part Number | Price Each | Quantity | Extended Price | Notes
C61,81 | Murata | GRM1555C1HR50CZ01D | CAP CER .5PF 50V C0G 0402 | Mouser | 81-GRM36C0R5C50 | 0.03 | 2 | 0.06
C62 | Murata | GRM1555C1H5R6DZ01D | CAP CER 5.6PF 50V C0G 0402 | Mouser | 81-GRM1555C1H5R6DZ1D | 0.03 | 1 | 0.03
C421,431 | Murata | GRM1555C1H270JZ01D | CAP CER 27PF 50V 5% C0G 0402 | Mouser | 81-GRM1555C1H270JZ01 | 0.03 | 2 | 0.06
C1,4,5 | Murata | GRM1555C1H680JZ01D | CAP CER 68PF 50V 5% C0G 0402 | Mouser | 81-GRM1555C1H680JZ1D | 0.03 | 3 | 0.09
C3 | Murata | GRM155R71E103KA01D | CAP CER 10000PF 25V 10% X7R 0402 | Mouser | 81-GRM36X103K25 | 0.03 | 1 | 0.03
C2,6,7,16,71 | Murata | GRM155R61A104KA01D | CAP CER .1UF 10V 10% X5R 0402 | Mouser | 81-GRM155R61A104KA01 | 0.02 | 4 | 0.08
L62 | Murata | LQG15HS5N6S02D | INDUCTOR 5.6NH 300MA 0402 | Mouser | 81-LQG15HS5N6S02D | 0.04 | 1 | 0.04
L61,81 | Murata | LQW15AN7N5J00D | INDUCTOR 7.5NH 570MA 0402 | Mouser | 81-LQW15AN7N5J00D | 0.31 | 2 | 0.62
L71 | Murata | LQW15AN27NJ00D | INDUCTOR 27NH 280MA 0402 | Mouser | 81-LQW15AN27NJ00D | 0.31 | 1 | 0.31
R451 | KOA Speer | RK73H1ETTP4302F | Thick Film Resistor 1/16W 43K 1% 0402 | Mouser | 660-RK73H1ETTP4302F | 0.06 | 1 | 0.06
U1 | Texas Instruments | CC2400-RTB1 | IC RF TXRX 2.4GHZ LP 48-QFN | Mouser | 595-CC2400-RTB1 | 9.14 | 1 | 9.14
J3 | Connector City | CONREVSMA003.031 | Reverse Polarized SMA Connector | Mouser | 712-CONREVSMA003.031 | 3.08 | 1 | 3.08 | Lower cost alternative: SparkFun WRL-00592 $1.95, SMA also an option
U2 | NXP | LPC1758FBD80,551 | ARM Cortex M3 Micro Controller | Mouser | 771-LPC1758FBD80551 | 8.67 | 1 | 8.67 | may substitute LPC175x
X1 | Abracon | ABMM2-16.000MHZ-E2-T | Crystal +/-20PPM 16MHz | Mouser | 815-ABMM2-16-E2T | 1.16 | 1 | 1.16
X2 | Molex | 48037-1000 | USB & Firewire Connector TYPE A RA SHLDED PLG SMT AU | Mouser | 538-48037-1000 | 2.22 | 1 | 2.22 | better price at Digi-Key
U5 | NXP | IP4220CZ6,125 | ESD Suppressor USB2.0 ESD PROTECT DUAL | Mouser | 771-IP4220CZ6-T/R | 0.18 | 1 | 0.18
U4 | Microchip | MCP1801T-1802I/OT | Low Dropout (LDO) Regulators Hi PSRR 150 mA LDO Vin 10V max Vout 1.8V | Mouser | 579-MCP1801T-1802IOT | 0.52 | 1 | 0.52
U3 | Vishay/Siliconix | SI9183DT-33-T1-E3 | Low Dropout (LDO) Regulator 150mA 3.3V | Mouser | 781-SI9183DT-33-E3 | 0.28 | 1 | 0.28
C14,15,17,18,20,22 | TDK | C1608X7R1E104K | CAP CER 0603 0.1uF 25volts X7R 10% | Mouser | 810-C1608X7R1E104K | 0.03 | 6 | 0.18
R5,6,7,8,9,11 | Xicon | 301-330-RC | Thick Film Resistor 1/16W 330OHMS 5% 0603 | Mouser | 301-330-RC | 0.03 | 6 | 0.18
R1,10,13 | Xicon | 301-10K-RC | Thick Film Resistor 1/16W 10KOHMS 5% 0603 | Mouser | 301-10K-RC | 0.03 | 2 | 0.06
C9 | TDK | C1608C0G1H101J | CAP CER 0603 100pF 50volts C0G 5% | Mouser | 810-C1608C0G1H101J | 0.03 | 1 | 0.03
C8 | TDK | C1608C0G1H221J | CAP CER 0603 220pF 50volts C0G 5% | Mouser | 810-C1608C0G1H221J | 0.03 | 1 | 0.03
R4 | Xicon | 301-1.5K-RC | Thick Film Resistor 1/16W 1.5KOHMS 5% | Mouser | 301-1.5K-RC | 0.03 | 1 | 0.03
R2,3 | Vishay/Dale | CRCW060333R0FKEA | Thick Film Resistor 1/10W 33ohms 1% 0603 | Mouser | 71-CRCW0603-33-E3 | 0.06 | 2 | 0.12
C19,21,23,24 | Murata | GRM188R60J105KA01J | CAP CER 0603 1uF 6.3volts X5R 10% | Mouser | 81-GRM18R60J105KA01J | 0.04 | 4 | 0.16
LEDs |  |  | 0603 LED, various colors |  |  | 0.10 | 6 | 0.60

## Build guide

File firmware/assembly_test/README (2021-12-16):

Follow this procedure to test, rework, and program a new Ubertooth One.  For
reference, see ubertooth-one-hardware/ubertooth-one-assembly.pdf and
ubertooth-one-hardware/ubertooth-one-schematic.pdf in the release package or
use KiCad to view the design files located in hardware/ubertooth-one.

Required Equipment

  - Equipment Under Test (EUT): Ubertooth One with 2 dBi antenna

  - Personal Computer (PC) with two open USB ports

  - Pogoprog, a serial programmer for Ubertooth One

  - USB Mini-B cable to connect Pogoprog to PC

  - USB A extension cable or USB hub to allow access to underside of Ubertooth
	One while it is plugged into the PC

  - A Bluetooth device such as a mobile phone

  - Multi-meter (voltmeter and continuity tester)

Required Software

  - lpc21isp

Visual Inspection

  1. Check EUT for missing components.

  2. Check that components are installed with the correct orientation and
  placement.

  3. Check in particular that R1 and C12 are not soldered together (one side,
  GND, may be together, but the side closest to U1 should not be).

Electrical Inspection

  1. Verify no conductivity across C18.

  2. Verify no conductivity across C22.

  3. Verify no conductivity across C32.
 
  If shorts are detected, carefully inspect (in order) the three capacitors
  listed above, the voltage regulator (U7), bypass capacitors, and all IC pins.

Power On EUT

  1. Connect to EUT the 2 dBi antenna.  Check that the antenna fully screws
  onto the RP-SMA connector.

  2. Plug EUT in to PC with USB A extension cable or USB hub.

  3. The "RST" LED (D5) should be illuminated.  No other LED should be fully
  illuminated, though they may be dimly lit.  D5 indicates that U4 has been
  powered on and passed reset.  If D5 does not illuminate, check D5, R8, R9,
  and pins 11 and 14 on U4.

Program EUT with assembly_test Firmware

  1. Ensure EUT is plugged into PC.

  2. Plug Pogoprog into PC with USB Mini-B cable.

  3. Hold Pogoprog against the "PROGRAM" pads on the underside of EUT as shown
  in the photograph:

    https://ubertooth.readthedocs.io/en/latest/programming.html#using-isp

  4. on the PC, execute:

    $ make program

  If you have not yet compiled the assembly_test firmware, you will need to
  have a gcc/arm environment set up.  See:

    https://ubertooth.readthedocs.io/en/latest/firmware.html#developing-firmware

  5. The 'make program' command will indicate "Download Finished . . . Now
  launching the brand new code" if successful.  If it was not successful, check
  the orientation and contact between the Pogoprog and sample Ubertooth One,
  make sure both are plugged in, and try again.

Automated Test

  1. Unplug EUT from PC and plug back in.

  2. "RST" LED (D5) should illuminate immediately and remain on throughout this
  test.

  3. "TX" LED (D2), "RX" LED (D3), and "USR" LED (D4) should flash twice
  together.  Flashing indicates that the test program is executing on U4.  If
  any of the three LEDs do not flash, check that LED, the adjacent resistor,
  and pins 73, 74, and 75 of U4.

  4. Next, "1V8" LED (D1) should illuminate and remain on.  This indicates that
  U3 is powered on.  If D1 does not illuminate, check D1, R3, R4, U7, and pin
  72 of U4.

  5. Next, "TX" LED (D2) should flash twice and then illuminate and remain on.
  This indicates that U4 is able to communicate with U3.  If D2 does not flash
  and illuminate, check pins 25-35 on U3 and pins 53, 54, 58, 59, 60, and 70 on
  U4.  Check that there is a 1.8 Volt potential across C18.  Check that there
  is a 3.3 Volt potential across C25.

  6. Next, "RX" LED (D3) should flash four times quickly and then illuminate
  and remain on.  This indicates that the 16 MHz crystal oscillator is active
  and supplying clock to both U3 and U4.  If D3 does not flash and illuminate,
  check X1, C19, C21, C29, C31, pins 21, 42, and 43 on U3, and pins 19 and 20
  on U4.

  7. At this point, four LEDs (D1, D2, D3, and D5) should all be on.

  8. Use a mobile phone or other Bluetooth device approximately 1 meter away
  from EUT to initiate an inquiry.  This function is typically called “search
  for new Bluetooth devices” or similar.

  9. During the inquiry, "USR" LED (D4) may flash and should then illuminate
  and remain on.  If D4 flashes but does not remain on after the inquiry, this
  indicates that RF performance is poor.  If D4 does not flash at all, this
  indicates a total RF failure.  Check that a 2 dBi antenna is securely
  connected to P1.  Check L1, L2, C1, C3, and C5.  Check all pins on U1 and U3.
  Check R1, R2, and R17.  Check all bypass capacitors around U1 and U3.  Check
  pins 50, 51, 61, 62, 63, 64, 65, 68, and 69 on U4.

  10. After D4 illuminates, the "USB" LED (D6) may flash and should then
  illuminate and remain on.  This indicates that the PC has established USB
  communication with EUT.  With some non-Linux operating systems, D6 may not
  illuminate.  Depending on the OS running on the PC, you might see a "found
  new hardware" or "install device driver software" dialog instead of
  illumination of D6.  You should be able to use operating system logging or
  reporting (e.g. dmesg on Linux) to see that a USB device with the product
  name "ubertooth assembly_test" has been detected.  This indicates success.
  Cancel any dialog and visually inspect D6 and R15.

  11. If all six LEDs are on (with the possible exception of D6 as mentioned
  above), the Automated Test is successful.  To repeat the Automated Test,
  unplug EUT from PC and plug in again.

Test Complete

  If your Ubertooth One has passed the assembly test procedure, the recommended
  next steps are:

  1. Install the USB bootloader on your Ubertooth One.  See:

	firmware/bootloader/README

  2. Use the bootloader to install the bluetooth_rxtx application firmware.
  See:

    host/usb_dfu/README

  3. Follow the Getting Started guide:

    https://ubertooth.readthedocs.io/en/latest/getting_started.html

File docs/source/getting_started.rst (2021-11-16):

===============
Getting Started
===============

There are three major components of Project Ubertooth:

    * hardware: The hardware design of Ubertooth One is quite stable. You can `build one <https://ubertooth.readthedocs.io/en/latest/assembling_hardware.html>`__ or `buy one <http://greatscottgadgets.com/ubertoothone>`__.
    * firmware: This is software that executes on the ARM processor on the Ubertooth One itself. This page assumes that you have the USB bootloader plus bluetooth_rxtx firmware installed on your board (which is typically what is installed at the time of assembly). The bluetooth_rxtx firmware is moderately stable but is likely to be enhanced as time goes on.
    * host code: This is software running on a general purpose computer connected to the Ubertooth One via USB. If you have not yet built the host code, please follow the `build guide <https://ubertooth.readthedocs.io/en/latest/build_guide.html>`__.

Ubertooth One is a development platform. The true power of the device is best realized when you start writing your own software and adapting it to your needs. If you are just getting to know the board, however, it can be helpful to try out open source code that others have made available. This guide will help you get started with your Ubertooth One by introducing you to some useful host code from the Ubertooth software repository.

Spectrum Analysis
~~~~~~~~~~~~~~~~~

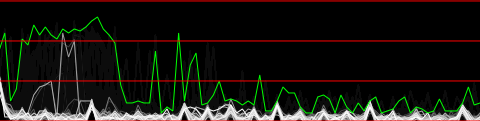
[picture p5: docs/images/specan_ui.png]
	

The first thing you should try with a new Ubertooth One is real-time spectrum analysis. Take a look at Jared's `demonstration video <http://www.sharebrained.com/2011/05/24/ubertooth-spectrum-analysis-fun>`__ for a preview.

Connect an antenna to your Ubertooth One and plug it into your computer. **Never operate your Ubertooth One without an antenna connected.** You should see the RST and 1V8 LEDs illuminate. This indicates that the LPC175x microcontroller is running (RST) and that power is being supplied to the CC2400 wireless transceiver IC (1V8). The USB LED may also light up if your computer's operating system has enumerated and configured the device (typical on Linux). Now you need some host code to tell the Ubertooth One what to do.

Download the latest Project Ubertooth `file release <https://github.com/greatscottgadgets/ubertooth/releases>`__ or check out current development code from the `git repository <https://github.com/greatscottgadgets/ubertooth>`__ and navigate to the ``host/python/specan_ui`` directory. Take a look at the README file and make sure that you have installed the prerequisite software. Then execute ``ubertooth-specan-ui`` as described in the README and watch the 2.4 GHz activity detected by the Ubertooth One.

One possible thing that could go wrong at this point is that your operating system does not grant you permission to communicate with the USB device. Depending on your distribution and preference, this can be fixed on Linux either by adding your user account to the ``usb`` group or by creating a new udev rule such as:

	.. code-block:: sh

		$ echo 'ACTION=="add" BUS=="usb" SYSFS{idVendor}=="1d50" SYSFS{idProduct}=="6002" GROUP:="plugdev" MODE:="0660"' > /etc/udev/rules.d/99-ubertooth.rules

A udev rules file is available in the ``host/build/misc/udev/``. Copy it to ``/etc/udev/rules.d/`` and run the following as root:

	.. code-block:: sh

		# udevadm control --reload-rules

Make sure you are a member of the ``plugdev`` group or change the rule to refer to the group of your choice. After adding the udev rule, unplug the Ubertooth One, reboot or restart udevd, and plug in the Ubertooth One again.

During operation of ubertooth-specan-ui the RX LED should illuminate, and the USR LED should be dimly lit. After you finish trying out ubertooth-specan-ui reset your Ubertooth One by unplugging it and plugging it back in.

LAP Sniffing
~~~~~~~~~~~~

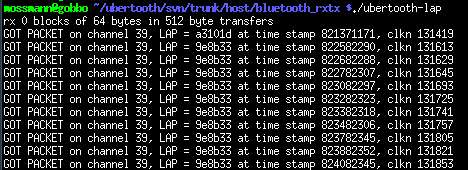
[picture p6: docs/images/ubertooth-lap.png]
	

Bluetooth packets start with a code that is based on the Lower Address Part (LAP) of a particular Bluetooth Device Address (BD_ADDR). The BD_ADDR is a 48 bit MAC address, just like the MAC address of an Ethernet device. The LAP consists of the lower 24 bits of the BD_ADDR and is the only part of the address that is transmitted with every packet.

The most important passive Bluetooth monitoring function is simply capturing the LAP from each packet transmitted on a channel. LAP sniffing allows you to identify Bluetooth devices operating in your vicinity.

In order to sniff LAPs, you'll have to compile the tools in ``host/ubertooth-tools``. These are command line programs intended to work with the bluetooth_rxtx firmware installed on your Ubertooth One. Follow the instructions in the README file in that directory to install the the prerequisite `libbtbb <https://github.com/greatscottgadgets/libbtbb>`__, a library for Bluetooth baseband functions. You can install libbtbb from a `file release <https://github.com/greatscottgadgets/libbtbb/releases>`__ rather than git if you prefer.

Once libbtbb is installed, just type:

	.. code-block:: sh

		mkdir build
		cd build/
		cmake ..
		make

in the ``host`` directory to compile the tools there. Then make sure your Ubertooth One is plugged in and execute:

	.. code-block:: sh

		$ ubertooth-rx

You should see various random LAPs detected. Due to uncertainties in identifying Bluetooth packets without prior knowledge of an address, it is normal for this process to identify false positives. error correction should mitigate this problem, but a small number of false positives may still be seen. When you see the same LAP detected more than once, that is very likely an actual Bluetooth transmission.

Generate some Bluetooth traffic and enjoy the show. I like to use a mobile phone or other Bluetooth device to perform an inquiry (usually called "find new Bluetooth devices" or something similar) to make sure that everything is working properly. An inquiry should produce lots of packets with the LAP 0x9e8b33.

Once you have seen a LAP multiple times, you can be confident that it is a genuine Bluetooth piconet. To find the next byte of the address, the UAP, we can use:

	.. code-block:: sh

		$ ubertooth-rx -l [LAP]

In this mode ubertooth-rx only detects packets from the given piconet and uses them to determine the next byte of the address and some of the internal clock value.

For more information on this process, and the challenges involved in monitoring Bluetooth connections, please read this `blog post <http://ubertooth.blogspot.co.uk/2013/02/motivating-problem.html>`__.

Kismet
~~~~~~

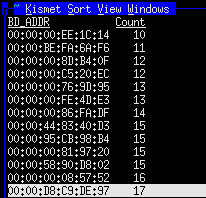
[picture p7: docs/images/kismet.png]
	

More advanced Bluetooth sniffing has been implemented in the form of a plugin for `Kismet <http://www.kismetwireless.net/>`__, the venerable 802.11 monitoring tool. In order to compile the Kismet-Ubertooth plugin, you will need a Kismet source tree matching the installed version. The easiest way to make this work is to uninstall any binary Kismet installation you may have installed and then download the Kismet source and follow the instructions to compile and install from the fresh source code. Once Kismet is installed, follow the instructions in ``host/kismet/plugin-ubertooth/README`` to install and use the plugin.

Notice that Kismet-Ubertooth identifies not only the LAP but also the 8 bit Upper Address Part (UAP) of detected devices as it is able. This is done by analyzing the timing and other characteristics of multiple packets over time. Another advantage of Kismet is that it dumps complete decoded packets to a pcapbtbb file that can be read with a Wireshark plugin that is distributed with `libbtbb <https://github.com/greatscottgadgets/libbtbb>`__. Full packet decoding is only possible when the packet's UAP has been determined.

Where to Go from Here
~~~~~~~~~~~~~~~~~~~~~

I hope you have found this guide helpful in getting to know your Ubertooth One. If you are interested in contributing to the project, or if you need help or would just like to chat about Project Ubertooth, join the `#ubertooth channel on Discord <https://discord.gg/rsfMw3rsU8>`__. Happy hacking!

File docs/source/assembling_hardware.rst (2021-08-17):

===================
Assembling Hardware
===================

The quickest and easiest way to get Ubertooth hardware is to buy it. A list of resellers is available from the `Great Scott Gadgets website <http://greatscottgadgets.com/ubertoothone/>`__. If you choose to build your own hardware, the following steps should help.

Step 0: read these instructions
-------------------------------

Seriously. There are probably things in the later steps that you should know about before getting started.

Step 1: order a PCB
-------------------

You will need a four layer printed circuit board. We recommend using `OSH Park <https://oshpark.com/>`__. Take the Ubertooth One Gerber files from the most recent Project Ubertooth release package (or generate them with KiCad) and send them to your chosen PCB manufacturer. The board is 1.8 square inches, so it will cost ~$18 per set of three. That's one for yourself, one for a friend, and one to screw up! Pogoprog is a two layer board.

If you are building an Ubertooth One, you should also consider building a Pogoprog unless you already have a plan for how you will `program <https://ubertooth.readthedocs.io/en/latest/programming.html>`__ your board.

Step 2: order a stencil
-----------------------

Surface mount soldering is fun and easy if you use a stencil to apply solder paste to your circuit board! Send the top paste Gerber file (ubertooth-one-SoldP_Front.gtp) to a stencil manufacturer such as `OHARARP <http://ohararp.com/stencils>`__, `OSH Stencils <https://www.oshstencils.com/>`__, or `Pololu <https://www.pololu.com/product/446>`__. Alternatively you might plan to use a syringe or a toothpick to apply solder paste, but this is not recommended. You might instead just use a soldering iron, but this is strongly discouraged unless you have successfully soldered QFNs with required ground pads before (and, if you have, you probably aren't reading these instructions anyway).

Step 3: order the parts
-----------------------

Take the bill of materials (bom) from the most recent Project Ubertooth release (or generate it with KiCad) and order the parts. The parts should all be available from one or more online electronics suppliers such as `Mouser <http://www.mouser.com/>`__ or `Digi-key <http://www.digikey.com/>`__. It is important to order some extra parts (especially the tiny ones which fortunately are cheap) in case you lose or damage any components.

You may want to order an antenna too. The `Pulse W1030 <http://www.pulseelectronics.com/products/old_antennas/products__solutions/antennas_for_wireless_devices/wd_antennas/w1030_external_24_ghz_high_gain_short>`__ is a nice size, but you can also find compatible antennas on many commercial Wi-Fi and Bluetooth products. Most any antenna intended for the 2.4 GHz band (such as 802.11b/g/n) is suitable as long as it has an RP-SMA connector, adapter, or pigtail. You could choose an SMA connector instead of RP-SMA; this might especially be convenient for interfacing with benchtop test gear. RP-SMA was selected as the default choice for Project Ubertooth because there are more RP-SMA than SMA antennas floating around on consumer Wi-Fi and Bluetooth gear.

You might prefer to select alternative parts, but be careful of the 1% resistors and all of the 0402 inductors and capacitors in the RF section which have been selected for their particular characteristics. Any LPC175x microcontroller will do, but it is recommended that you choose one with at least 128 kB RAM. And, really, if you're going through all this trouble, why not go with 512 kB?

Step 4: prepare your tools and materials
----------------------------------------

Essential:

    * an electric skillet, one that you don't intend to use for food ever again
    * solder paste (no-clean lead-based solder paste is recommended)
    * a small putty knife or razor blade
    * fine tipped tweezers
    * any soldering iron
    * solder

Strongly recommended:

    * good ventilation
    * a temperature controlled soldering iron: this is more than just having a knob; it should have a temperature sensor in the iron
    * an embossing tool or other high temperature heat gun (even better: a proper hot air rework station)
    * a multitester with LED/diode test mode
    * desoldering braid
    * brass sponge
    * helping hands
    * magnifying glass

Step 5: apply solder paste
--------------------------

Using your stencil and a putty knife, apply the solder paste as described in this `tutorial <https://www.sparkfun.com/tutorials/58>`__.

Step 6: place the parts
-----------------------

With fine tipped tweezers, carefully place the parts on the board. If you have to move a part, pick it up and place it again rather than sliding it around a lot. Otherwise the paste can get out of place. Most of the 0402 and 0603 parts can be placed in either direction, but the LEDs are exceptions. You must place them with ground in the direction of the arrow on the circuit board. You may have to look at the design in KiCad to see which way the arrow goes, and you'll probably have to test your LEDs with a multitester to find out which side is which. Don't populate USB connectors, RP-SMA connectors, or pogo pins (in the case of Pogoprog) at this time.

Step 7: reflow
--------------

Carefully place the board in the electric skillet, and turn the skillet on. It is best to warm up the board to a moderate temperature before turning the skillet up to full power. Then turn up the heat until you can see the solder flow. If you see parts moving around to incorrect positions, resist the temptation to correct them at this time! As soon as the solder everywhere on the board appears liquid, cut the power completely. You may want to lift the board out of the skillet with a spatula at this point to allow it to cool faster. There is a danger of overheating the components, but this is unlikely unless you left the skillet on longer than necessary or used lead-free solder paste.

Step 8: rework
--------------

Here is where the embossing tool, a good soldering iron, desoldering braid, and a magnifying glass come in very handy. If there is anything wrong with the assembly, you will have to correct individual part placement as needed.

Step 9: inspection
------------------

Once all the parts appear to be soldered in place correctly, look again, this time with a magnifying glass. You should also do some continuity tests with a multitester at this point. Watch out in particular for supply shorts; the easiest way to test for these is to verify a lack of continuity across bypass capacitors (all the caps that are close to the ICs). If there is a short that you can't see, it is probably under the pins of one of the ICs. Repeat steps 7 and 8 as necessary.

Step 10: hand soldering
-----------------------

There are a few parts that you should solder on by hand with an iron at this point. These are the USB and RP-SMA connectors on the Ubertooth boards and the pogo pins on Pogoprog.

Step 11: power-on test
----------------------

Power on the device by plugging in the USB connection. An Ubertooth One or Zero should illuminate the RST LED. If this doesn't happen, quickly unplug USB verify that the LED is oriented correctly, and go back to step 9. A Pogoprog should flash its TX and RX LEDs during USB enumeration. If this doesn't happen, quickly unplug USB, verify the LED orientations, check your driver situation, and go back to step 8.

Step 12: further testing
------------------------

If you are building a Pogoprog, you should make sure that an FTDI USB serial adapter has been detected by your host operating system. If so, you can try using it to `program <https://ubertooth.readthedocs.io/en/latest/programming.html>`__ an Ubertooth board. If you are making an Ubertooth board, you should follow the procedure in firmware/assembly_test/README.

Step 13: boast
--------------

Tell us about your success on the Great Scott Gadgets `Discord <https://discord.gg/rsfMw3rsU8>`__.

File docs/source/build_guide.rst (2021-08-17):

===========
Build Guide
===========

Release 2020-12-R1
~~~~~~~~~~~~~~~~~~

`for Release 2018-12-R1 see here <https://ubertooth.readthedocs.io/en/latest/Release_2018-12-R1.html>`__

Prerequisites
^^^^^^^^^^^^^

There are some prerequisites that need to be installed before building libbtbb and the Ubertooth tools. Many of these are available from your operating system's package repositories, for example:

Debian 10 / Ubuntu 20.04 / Kali
+++++++++++++++++++++++++++++++

	.. code-block:: sh

		sudo apt install cmake libusb-1.0-0-dev make gcc g++ libbluetooth-dev wget \
		pkg-config python3-numpy python3-qtpy python3-distutils python3-setuptools

Fedora 33
+++++++++

	.. code-block:: sh

		sudo dnf install libusb1-devel make gcc gcc-c++ cmake wget tar bluez-libs-devel
		echo /usr/local/lib | sudo tee /etc/ld.so.conf.d/libc.conf

RHEL 8
++++++

	.. code-block:: sh

		sudo subscription-manager repos --enable=codeready-builder-for-rhel-8-x86_64-rpms
		sudo dnf install libusb1-devel make gcc gcc-c++ wget tar bluez-libs-devel python36 python36-devel
		echo /usr/local/lib | sudo tee /etc/ld.so.conf.d/libc.conf
		# Note: you will also need to install CMake 3.12.0 or greater. See https://cmake.org/install/

CentOS 8
++++++++

	.. code-block:: sh

		sudo dnf config-manager --enable powertools
		sudo dnf install libusb1-devel make gcc gcc-c++ wget tar bluez-libs-devel python36 python36-devel
		echo /usr/local/lib | sudo tee /etc/ld.so.conf.d/libc.conf
		# Note: you will also need to install CMake 3.12.0 or greater. See https://cmake.org/install/

Mac OS X users can use either MacPorts or Homebrew to install the required packages:
++++++++++++++++++++++++++++++++++++++++++++++++++++++++++++++++++++++++++++++++++++

	.. code-block:: sh

		brew install libusb wget cmake pkg-config
		or
		sudo port install libusb wget cmake python38 py38-numpy py38-qtpy

FreeBSD users can install the host tools and library directly from the ports and package system:
++++++++++++++++++++++++++++++++++++++++++++++++++++++++++++++++++++++++++++++++++++++++++++++++++++++

	.. code-block:: sh

		sudo pkg install ubertooth

libbtbb
^^^^^^^

Next the Bluetooth baseband library (libbtbb) needs to be built for the Ubertooth tools to decode Bluetooth packets:

	.. code-block:: sh

		wget https://github.com/greatscottgadgets/libbtbb/archive/2020-12-R1.tar.gz -O libbtbb-2020-12-R1.tar.gz
		tar -xf libbtbb-2020-12-R1.tar.gz
		cd libbtbb-2020-12-R1
		mkdir build
		cd build
		cmake ..
		make
		sudo make install
		sudo ldconfig

Ubertooth Tools
^^^^^^^^^^^^^^^

The Ubertooth repository contains host code for sniffing Bluetooth packets, configuring the Ubertooth and updating firmware. All three are built and installed by default using the following method:

	.. code-block:: sh

		wget https://github.com/greatscottgadgets/ubertooth/releases/download/2020-12-R1/ubertooth-2020-12-R1.tar.xz
		tar -xf ubertooth-2020-12-R1.tar.xz
		cd ubertooth-2020-12-R1/host
		mkdir build
		cd build
		cmake ..
		make
		sudo make install
		sudo ldconfig	

Wireshark plugins
^^^^^^^^^^^^^^^^^

Users of Wireshark version 2.2+ do not need to build any plugins at all and may skip this section (see `this comment <https://github.com/greatscottgadgets/libbtbb/issues/50#issuecomment-284128258>`__). This includes users of Debian 10+, Ubuntu 20.04+, Fedora 33+, RHEL 8.3+, and most other Linux distributions. You can check your version by clicking on Help --> About Wireshark.

Wireshark version 1.12 and newer includes the Ubertooth BLE plugin by default. It is also possible to `capture BLE from Ubertooth directly into Wireshark <https://ubertooth.readthedocs.io/en/latest/capturing_BLE_Wireshark.html>`__ with a little work.

The Wireshark BTBB and BR/EDR plugins allow Bluetooth baseband traffic that has been captured using Kismet to be analysed and disected within the Wireshark GUI. They are built separately from the rest of the Ubertooth and libbtbb software.

The directory passed to cmake as ``MAKE_INSTALL_LIBDIR`` varies from system to system, but it should be the location of existing Wireshark plugins, such as ``asn1.so`` and ``ethercat.so``. On macOS this is likely ``/Applications/Wireshark.app/Contents/PlugIns/wireshark/``.

	.. code-block:: sh

		sudo apt-get install wireshark wireshark-dev libwireshark-dev cmake
		cd libbtbb-2020-12-R1/wireshark/plugins/btbb
		mkdir build
		cd build
		cmake -DCMAKE_INSTALL_LIBDIR=/usr/lib/x86_64-linux-gnu/wireshark/libwireshark3/plugins ..
		make
		sudo make install	

Then repeat for the BT BR/EDR plugin:

	.. code-block:: sh

		sudo apt-get install wireshark wireshark-dev libwireshark-dev cmake
		cd libbtbb-2020-12-R1/wireshark/plugins/btbredr
		mkdir build
		cd build
		cmake -DCMAKE_INSTALL_LIBDIR=/usr/lib/x86_64-linux-gnu/wireshark/libwireshark3/plugins ..
		make
		sudo make install

Third Party Software
~~~~~~~~~~~~~~~~~~~~

There are a number of pieces of `third party software <https://ubertooth.readthedocs.io/en/latest/third_party_software.html>`__ that support the Ubertooth. Some support Ubertooth out of the box, while others require plugins to be built.

Firmware
~~~~~~~~

This completes the install of the Ubertooth tools, the next step is to look at the getting started guide. You should always `update the firmware <https://ubertooth.readthedocs.io/en/latest/firmware.html>`__ on the Ubertooth device to match the software release version that you are using.

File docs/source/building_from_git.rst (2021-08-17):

=================
Building from git
=================

Prerequisites
~~~~~~~~~~~~~

There are some prerequisites that need to be installed before building libbtbb and the Ubertooth tools. Many of these are available from your operating system's package repositories, for example:

Debian/Ubuntu
^^^^^^^^^^^^^

	.. code-block:: sh

		sudo apt-get install git cmake libusb-1.0-0-dev make gcc g++ libbluetooth-dev \
		pkg-config libpcap-dev python-numpy python-pyside python-qt4

Fedora / Red Hat
^^^^^^^^^^^^^^^^

	.. code-block:: sh

		su -c "yum install git libusb1-devel make gcc wget tar bluez-libs-devel"

Mac OS X users can use either MacPorts or Homebrew to install the required packages:
^^^^^^^^^^^^^^^^^^^^^^^^^^^^^^^^^^^^^^^^^^^^^^^^^^^^^^^^^^^^^^^^^^^^^^^^^^^^^^^^^^^^

	.. code-block:: sh

		sudo port install git libusb wget cmake python27 py27-numpy py27-pyside
		or
		brew install git libusb wget cmake pkg-config homebrew/dupes/libpcap

libbtbb
~~~~~~~

Next the Bluetooth baseband library (libbtbb) needs to be built for the Ubertooth tools to decode Bluetooth packets:

	.. code-block:: sh

		git clone https://github.com/greatscottgadgets/libbtbb.git
		cd libbtbb
		mkdir build
		cd build
		cmake ..
		make
		sudo make install

**Linux users**: if you are installing for the first time, or you receive errors about finding the library, you should run:

	.. code-block:: sh

		sudo ldconfig

Ubertooth tools
~~~~~~~~~~~~~~~

The Ubertooth repository contains host code for sniffing Bluetooth packets, configuring the Ubertooth and updating firmware. All three are built and installed by default using the following method:

	.. code-block:: sh

		git clone https://github.com/greatscottgadgets/ubertooth.git
		cd ubertooth/host
		mkdir build
		cd build
		cmake ..
		make
		sudo make install	

**Linux users**: if you are installing for the first time, or you receive errors about finding the library, you should run:

	.. code-block:: sh

		sudo ldconfig

Wireshark
~~~~~~~~~

Wireshark version 1.12 and newer includes the Ubertooth BLE plugin by default. It is also possible to `capture BLE from Ubertooth directly into Wireshark <https://ubertooth.readthedocs.io/en/latest/capturing_BLE_Wireshark.html>`__ with a little work.

The Wireshark BTBB and BR/EDR plugins allow Bluetooth baseband traffic that has been captured using Kismet to be analysed and disected within the Wireshark GUI. They are built separately from the rest of the Ubertooth and libbtbb software. The directory passed to cmake as ``MAKE_INSTALL_LIBDIR`` varies from system to system, but it should be the location of existing Wireshark plugins, such as ``asn1.so`` and ``ethercat.so``.

	.. code-block:: sh

		sudo apt-get install wireshark wireshark-dev libwireshark-dev cmake
		cd libbtbb/wireshark/plugins/btbb
		mkdir build
		cd build
		cmake -DCMAKE_INSTALL_LIBDIR=/usr/lib/x86_64-linux-gnu/wireshark/libwireshark3/plugins ..
		make
		sudo make install

Then repeat for the BT BR/EDR plugin:

	.. code-block:: sh

		sudo apt-get install wireshark wireshark-dev libwireshark-dev cmake
		cd libbtbb/wireshark/plugins/btbredr
		mkdir build
		cd build
		cmake -DCMAKE_INSTALL_LIBDIR=/usr/lib/x86_64-linux-gnu/wireshark/libwireshark3/plugins ..
		make
		sudo make install	

Third Party Software
~~~~~~~~~~~~~~~~~~~~

There are a number of pieces of `third party software <https://ubertooth.readthedocs.io/en/latest/third_party_software.html>`__ that support the Ubertooth. Some support Ubertooth out of the box, while others require plugins to be built.

Firmware
~~~~~~~~

This completes the install of the Ubertooth tools, the next step is to look at the getting started guide. You should always `update the firmware <https://ubertooth.readthedocs.io/en/latest/firmware.html>`__ on the Ubertooth device to match the software release version that you are using.

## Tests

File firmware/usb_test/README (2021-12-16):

usb_test.c implements a USB serial (CDC) interface.  After flashing the
Ubertooth board, unplug the board from USB and plug it in again.  A new USB
device should be detected.  For example (on Linux):

# dmesg

[134437.193956] usb 8-1.2: New USB device found, idVendor=ffff, idProduct=0005
[134437.193962] usb 8-1.2: New USB device strings: Mfr=1, Product=2, SerialNumber=3
[134437.193969] usb 8-1.2: Product: Ubertooth serial
[134437.193974] usb 8-1.2: Manufacturer: Great Scott Gadgets
[134437.193980] usb 8-1.2: SerialNumber: 00000001

The USBLED should be illuminated at this point.

Further testing of the USB serial interface can be done by attaching a USB
serial driver to the device.  On Linux, you can do this by disconnecting the
Ubertooth board (and any other USB serial devices) and then:

# modprobe -r usbserial
# modprobe usbserial vendor=0xffff product=0x0005

Then connect the Ubertooth board.  You should now have a new USB serial port:

# dmesg

[135221.849162] usbserial_generic 8-1.2:1.1: generic converter detected
[135221.849391] usb 8-1.2: generic converter now attached to ttyUSB1

You can connect to this port (for example with minicom) and type some
characters.  Each character should echo back to the screen, and USRLED should
toggle on or off with each character typed.

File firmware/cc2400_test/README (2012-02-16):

cc2400_test.c powers up the CC2400 wireless transceiver and exercises the SPI
control interface to verify that the CC2400 responds with an expected default
register value.

On success all LEDs are illuminated.

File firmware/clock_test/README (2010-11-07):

clock_test.c powers up the CC2400 wireless transceiver, activates its
oscillator, turns on the CC2400's clock output, and switches the LPC175x
oscillator to this clock source.

On success USRLED flashes faster than once per second.

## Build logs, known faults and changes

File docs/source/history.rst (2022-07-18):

=======
History
=======

The first hardware revision is called Ubertooth Zero and was demonstrated at
ToorCon 12 on October 24th, 2010. Ubertooth Zero has been superseded.

The current hardware revision is called Ubertooth One and was demonstrated at
ShmooCon 7 on January 29th, 2011.

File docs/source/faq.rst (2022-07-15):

===
FAQ
===

**Question: What is the latest release?**

**Answer:** The latest release is 2018-08-R1: the DEFCON release, but you should check `this repo's releases <https://github.com/greatscottgadgets/ubertooth/releases>`__ for the most up to date information. See the `Build Guide <https://ubertooth.readthedocs.io/en/latest/build_guide.html>`__ for instructions on how to download and build the software.

----------

**Question: I run Windows or Mac OS X. What's the best way to use Ubertooth?**

**Answer:** The best way to use Ubertooth is from a native Linux install. If you don't normally run Linux, we recommend you boot Linux from USB using a distro such as `Kali <https://www.kali.org/>`__ or `Pentoo <http://pentoo.ch/>`__.

It **may** be possible to use Ubertooth from within a virtual machine. However, people have reported issues with USB throughput and requests timing out. If you're a newbie, booting directly into Linux is the recommended method.

----------

**Question: How do I update firmware?**

**Answer:** Refer to the wiki page `Firmware <https://ubertooth.readthedocs.io/en/latest/firmware.html#>`__.

----------

**Question: Can I use my Ubertooth with a VM?**

**Answer:** Yes. Many people have reported successfully using their Ubertooth with host tools installed in a virtual machine. There are, as always, some things to be aware of when attempting this.

    * The Ubertooth uses USB2.0, which requires the `VirtualBox extension pack <https://www.virtualbox.org/wiki/Downloads>`__ to be downloaded and installed.
    * The Ubertooth also uses different vendor and product identifiers when in normal operation and firmware upload mode, so rules for both of these will need to be added to the virtual machine for full operation.

Other virtual machine environments may differ and therefore present different issues. If you successfully use the Ubertooth with a different virtualisation system, please let us know so that we can help future users.

----------

**Question: What can the Ubertooth capture?**

**Answer:** The Ubertooth is able to capture and demodulate signals in the 2.4GHz ISM band with a bandwidth of 1MHz using a modulation scheme of Frequency Shift Keying or related methods.

This includes, but is not limited to:

    * Bluetooth Basic Rate packets

    * Bluetooth Low Energy (Bluetooth Smart)

The following may be possible:

    * 802.11 FHSS (1MBit)

    * Some proprietary 2.4GHz wireless devices

----------

**Question: Can I listen to my phone calls?**

**Answer:** Not yet, this will require full frequency hopping support and possibly require breaking encryption by sniffing the connection process. It's on the todo list, but there's a lot of hard work to go before we get there. If you're interested in making it happen, you can get involved in the project.

----------

**Question: What is the max capture size of Bluetooth Low Energy (BLE) packets?**

**Answer:** 50 bytes. Longer BLE packets are truncated to 50 bytes by the Ubertooth firmware.

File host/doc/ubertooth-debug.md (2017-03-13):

# ubertooth-debug 1 "March 2017" "Project Ubertooth" "User Commands"

## NAME

ubertooth-debug(1) - Classic Bluetooth discovery, sniffing, and decoding

## SYNOPSIS

    ubertooth-debug -r <number>[,<number>[,...]]

## DESCRIPTION

ubertooth-debug(1) is a tool for reading register values from the CC2400 chip
on Ubertooth One. It is primarily designed to assist firmware development but
may be of interest to curious hackers.

## OPTIONS

Options:

 - `-r <reg>[,<reg> [,[...]]]` :
   Read one or more registers from the CC2400 on Ubertooth
 - `-r <start>-<end>` :
   Read a consecutive set of registers from the CC2400 on Ubertooth
 - `-v <0-2>` :
   Sets the level of verbosity, default is 1.
 - `-U<0-7>` :
   Which Ubertooth device to use

## EXAMPLES

To read the MANOR register, use:

    ubertooth-debug -r 19

Registers can also be specified by name, the following will
also read the MANOR register:

    ubertooth-debug -r %manor

Read a range of registers:

    ubertooth-debug -r 19-22

Dump all registers with:

    ubertooth-debug -r 0x00-0x70

## SEE ALSO

ubertooth(7): overview of Project Ubertooth

## AUTHOR

This manual page was written by Dominic Spill.

## COPYRIGHT

ubertooth-debug(1) is Copyright (c) 2010-2017. This tool is released under the
GPLv2. Refer to `COPYING` for further details.

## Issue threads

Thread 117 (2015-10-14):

/libbtbb/lib/src/pcap.ng-bt.c:436:assemble_pcap_le_packet: Assertion 'caplen <= 48' failed. Aborted.

omarsohail, 2015-10-14:
Hey,
we're currently working on a bluetooth sniffing project using ubertooth and kali linux for the operating system. We seem to keep getting this error every time the ubertooth attempts to sniff packets from a android smartphone (Samsung I9500 Galaxy S4). The process starts but eventually after a few minutes shows this error and aborts. Any help would be great
thanks

dominicgs, 2015-10-14:
This looks to be related to two pull requests for libbtbb (25 and 26).

Closed 2020-12-03.

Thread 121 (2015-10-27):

Error with Ubertooth One

ninjaztar, 2015-10-27:
Hi,

I purchase an Ubertooth recently and had followed the latest build guide on github to install the necessary tools. After installing the necessary tools, I followed the instruction on github to update the firmware but receive the following error.

ubuntu@ubuntu:~/ubertooth-2015-10-R1/ubertooth-one-firmware-bin$ ubertooth-dfu -d bluetooth_rxtx.dfu -r
libUSB Error: Timeout:  (-7)
Switching to DFU mode...
Unable to find Ubertooth

Anyone able to help me out with this? Thanks in advance.

dominicgs, 2015-10-27:
Hi @ninjaztar are you running in a VM?  The Ubertooth has a different USB product ID when in DFU mode, so you'll need to set up a rule to pass both IDs through to the VM from your host.

ninjaztar, 2015-10-28:
Hi @dominicgs, thanks for the prompt reply.

Yes, I am running it in a VM. Based on openmoko the product and vendor ID for ubertooth one is 0x1d50 and 0x6002 and for  ubertooth one DFU is 0x1d50 and 0x6003. I had added the ID into the vmx file of my VM to auto-connect it. But I am still receiving the same error as followed.

ubuntu@ubuntu:~/ubertooth-2015-10-R1/ubertooth-one-firmware-bin$ ubertooth-dfu -d bluetooth_rxtx.dfu -r
libUSB Error: Timeout: (-7)
Switching to DFU mode...
Unable to find Ubertooth

Am I doing anything wrong?

dominicgs, 2015-10-28:
Depending on the age of your Ubertooth, you may not have the OpenMoko USB IDs in DFU mode.  Before we switched over to them we were using 0xffff 0x0004.

Assuming that the Ubertooth is entering DFU mode (the lights flash in a distinctive pattern), could you check which USB ID it has?

ninjaztar, 2015-10-28:
I was able to view the USB ID in the VM before entering DFU mode which is as shown below.
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

Upon entering DFU mode with the command "ubertooth-util -f" the ubertooth lost it connection from the vm and I was not able to view the USB ID information of the ubertooth anymore.

Is the information of any help?

dominicgs, 2015-10-28:
Yes, I think you need to look at the USB devices available to the VM while the Ubertooth is in DFU mode.  There will be another device ID, either an OpenMoko (0x1d50) or a generic one that we used before (0xffff)

parkerpatriot, 2015-10-31:
I had this problem using my VM. It happens to me because the device changes name when in dfu mode. I navigate to my list of USB devices and add the renamed device to my machine. In my case my device name changed from `ubertooth bluetooth_rxtx` to 'usb_bootloader`. Once I have re-added it I re-run the flash command `sudo ubertooth-dfu -d bluetooth_rxtx.dfu` and it works like a charm.

ninjaztar, 2015-11-05:
Thanks for the response. Also sorry for the late reply.

Hi @dominicgs, I can't seems to find any of the ID you mentioned. Once i tried entering DFU mode to update the firmware I will receive the following error with the LED light performing a distinctive chasing pattern.

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

I then tried entering this command "make clean all && make && ubertooth-dfu -r -d bluetooth_rxtx.dfu" to troubleshoot it but was given the following error message.

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

Hi @parkerpatriot, is the ubertooth device still connected to your VM once you entered DFU mode, as my ubertooth cannot be recognize once entering DFU mode.

Any help is appreciated. Thanks.

dominicgs, 2015-11-05:
@ninjaztar Could you show us a list of the USB devices that are attached to your host system when the Ubertooth is in DFU mode?

ninjaztar, 2015-11-05:
The first image is the ubertooth being connected to my host machine before entering DFU mode.

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

The second image is the ubertooth being connected to my host machine, while entering DFU mode.

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

is the information of any help?

dominicgs, 2015-11-05:
It's strange that Windows is seeing it as a "USB SmartCard Reader".  If you look at the properties of that device, you should be able to find the hardware IDs - VID / PID.

Alternatively, pass the "smart card reader" through to the VM and look at the output of `lsusb`.

parkerpatriot, 2015-11-05:
@ninjaztar to answer your question, I essentially lose the device as well when I put it in DFU mode. I have to go re-add it as a new device. However, my device still has a recognizable name (`usb_bootloader` in my case). Like @dominicgs said it's strange that it's showing up as USB SmartCard reader. By the way, are you using a Linux VM? That's weird. In your VM settings you can sometimes specify what devices should be automatically associated with the VM on startup. I would go to those settings after putting it in DFU mode and try associating this "USB SmartCard Reader" with the VM. Then restart your VM and try the process of putting it in DFU mode again. When you do, the VM shouldn't end up losing the device even though it will now be renamed. Then you could see if  your VM recognizes the device correctly.

pmar9000, 2015-11-06:
Hi

I had the same problem doing dfu through a VM (in my case VirtualBox).
I had to add a filter for both 1d50:6002 and 1d50:6003 for the usbbootloader device.
Then I got the dfu to work.

/Peter

ninjaztar, 2015-11-09:
Hi all, thanks for the response.

It seem the firmware of my ubertooth had been updated to 2015-10-R1, as shown in the image below.

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

However, when I was updating the firmware with the command "ubertooth-dfu -d bluetooth_rxtx.dfu -r", I receive the following output.

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

The expected output from github when the command was being entered was supposed to be similar to the one shown below. .

Checking firmware signature
No DFU devices found - attempting to find Ubertooth devices

1) Found 'Ubertooth One' with address 0x1d50 0x6002

Select a device to flash (default:1, exit:0):

Is there anything wrong with the update?

dominicgs, 2015-12-01:
@ninjaztar That update looks good.  There have been changes to the DFU tool recently that mean the output is not always the same.

As we have solved this issue, I will close this bug report.

ninjaztar, 2015-12-03:
Alright. Thanks everyone for all the help.

trublsom, 2016-01-12:
I can't update my firmware either.

I completed the build guide. I am using vmware workstation 12 (free). I have tried updating with kali 2.0 (desktop) and ubuntu 15.10 (laptop).

blue@ubuntu:~/ubertooth-2015-10-R1/ubertooth-one-firmware-bin$ ubertooth-util -v
Firmware revision: 2012-10-R1
blue@ubuntu:~/ubertooth-2015-10-R1/ubertooth-one-firmware-bin$ ubertooth-util -V
control message unsupported
error: -9

ubertooth-one-firmware-bin$ ubertooth-dfu -d bluetooth_rxtx.dfu -r
libUSB Error: Timeout:  (-7)
Switching to DFU mode...
Unable to find Ubertooth

/ubertooth-one-firmware-bin$ make clean all && make && ubertooth-dfu -r -d bluetooth_rxtx.dfu
make: *** No rule to make target 'clean'.  Stop.

blue@ubuntu:~$ lsusb
Bus 002 Device 007: ID 1d50:6002 OpenMoko, Inc.

Windows sees my device as: "bluetooth_rxtx"

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

dominicgs, 2016-01-12:
@trublsom Did you try the solution from @pmar9000 above: https://github.com/greatscottgadgets/ubertooth/issues/121#issuecomment-154429656

The Ubertooth uses two different USB IDs for normal operation and firmware update mode.  What's happening is that the Ubertooth resets itself at the start of the process, to reappear with the other ID.  Unfortunately this other ID is not passed through to the VM, so the rest of the tool fails.

Add a second USB pass through rule for the ID 1d50 6003

trublsom, 2016-01-13:
I couldn't find how to add a filter for the usb devices using vmware workstation... so i turned one of my old desktop into a kali 2.0 box (bare metal). I ran the script created by dinosec. https://github.com/dinosec/ubertooth-install

Double checked that the everything from the build guide was completed then ran the dfu command.

It looks like my problem was VM related.  Since the firmware update work the very first time when I did it on bare metal.

Also I did get the same output as ninjaztar did (ninjaztar commented on Nov 8, 2015). However after running "ubertooth-util -v" I saw that it had been updated to 2015-10-R1

Thank you for responding to me even though this issue had been closed.

garyv100, 2016-03-11:
Hi,

I have just purchased Ubertooth One w/ firmware release dated back to 2012.

I am running Ubuntu 14.04 LTS in VMWare Workstation 11. It looks like that there were similar issues w/ VM that were resolved by adding filters to USB device which I do not know how to do in VMware. If someone could help me with that - it would be great.

This is what I get when I try to update the firmware for 2015.
///////////////////////////////////////////////////////////////////////////
garyv@ubuntu:~/ubertooth/ubertooth-2015-10-R1/ubertooth-one-firmware-bin$ sudo ubertooth-dfu -d bluetooth_rxtx.dfu -r
libUSB Error: Command Error: (-1)
Switching to DFU mode...
Checking firmware signature
.......................................................................................................................................
libUSB Error: Command Error: (-1)
/////////////////////////////////////////////////////////////////////////////
When I check rev:
garyv@ubuntu:/usr/local/bin$ ./ubertooth-util -v
Firmware revision: 2015-10-R1

First question, given the above, did the firmware updated correctly?

To see if it did, for starters i tried to replicate your youtube demo using:
////////////////////////////////////////////////////////
sudo ubertooth-scan -b hci0 -t 40 –x
Ubertooth scan
systime=1457634961 ch=10 LAP=f19d9a err=2 clk100ns=2335214731 clk1=373634 s=-54 n=-62 snr=8
systime=1457634971 ch=57 LAP=a667b3 err=2 clk100ns=2429973401 clk1=388796 s=-52 n=-63 snr=11
??:??:??:F1:9D:9A
AFH map: 0x00040000000000000000
??:??:??:A6:67:B3
AFH map: 0x00000000000000020000
//////////////////////////////////////////////////////////////////
or sometimes I get noting, it just hangs
///////////////////////////////////////////////////////////////
garyv@ubuntu:~/ubertooth/ubertooth-2015-10-R1/ubertooth-one-firmware-bin$ sudo ubertooth-scan -b hci0 -t 40 –x

Ubertooth scan
///////////////////////////////////////////////////////////////////

Is this a VMWare issue, am I doing something wrong, how do I fix it?

chuzairps, 2022-06-29:
Hi there,
Facing firmware updating issue

sudo ubertooth-dfu -d bluetooth_rxtx.dfu -r
Checking firmware signature
Unknown DFU suffix length: 0
Signature check failed, firmware will not be update

Closed 2015-12-01.

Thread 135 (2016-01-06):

ubertooth-rx fails to follow

elli89, 2016-01-06:
During my diploma thesis I found out that ubertooth-rx fails to follow a piconet most of the time. After debugging with blinking LEDs and a logic analyzer I found some serious bugs in the firmware.

1. Ubertooth also captures date while hopping. While hopping, the cc2400 sends no data for ~130 µs and also stops his SPI clock. So one USB packet could contain Bluetooth data from two different channels but tells the host only one channel. Also the bit offset, which I introduced in #84 can't be calculated correctly because of the ~130 µs gap between two hops.

My solution for this issue distinguishes between the two modes sweep and follow. While sweeping every hop sets a flag to the current USB packet's status that tells the host to discard this packet. When following, the time between two hops is much shorter (625µs) and only one packet (50 bytes = 400 bits = 400 µs) can be captured on each channel. So I start the capturing process right after each hop and stop it as soon as the DMA is full.

2. Hops are not equidistant when capturing data from the cc2400, because the main loop in the firmware function bt_stream_rx() first fills an entire USB packet before checking if a hop should be done. This is especially bad when following a piconet because the hops of the Ubertooth and the observed piconet are misaligned that way.

3. The channel of the USB packet is set when the packet is sent to the host. So the channel of the packet does not represent the actual channel of the captured data. My solution is setting the channel in the DMA interrupt so it represents the channel of the last bit of the packet data (which should be the channel of every bit in one packet).

4. When following, the firmware initializes the cc2400 with the function cc2400_rx_sync(u32 sync). This function tells the chip to only listen for packets that fit to the syncword. However the syncword is never set in the firmware. The function also tells the chip to work in a "packet mode". In that mode the cc2400 does not deliver a raw bitstream but only a matching bluetooth packet without an access code and without the crc checksum. So even if the correct syncword is set, the captured data would lack the access code which is necessary for libbtbb to detect bluetooth packets and do all the calculations for following. So I think even when following the firmware should initialize the cc2400 with the function cc2400_rx().

5. CLKN of the Ubertooth is not aligned to the clock of the piconet. So sometimes when following the Bluetooth access codes are always sent by the piconet when the Ubertooth is hopping. In that case no bluetooth packet is detected at all by libbtbb. The solution is to stretch/trim clk100ns before telling the Ubertooth to follow so the AC is always sent 225 µs (CLK_TUNE_TIME) after the beginning of a CLKN cycle. I achieved that by calculating the offset between the first bit of the access code and the first edge of CLKN and sending the value to the Ubertooth using a new command cmd_trim_clock().

I solved those issues in my experimental branch "fix-clock". Now ubertooth-rx is able to follow a piconet more reliably and captures much more packets from the piconet. Though sometimes it still fails. In about one third of all cases I observe a strange misalignment between the Bluetooth data and the Ubertooth clock even when not stretching/trimming clk100ns. In one pass of ubertooth-rx the alignment is good, when I stop the program and start it again, the Bluetooth data are misaligned by either 225 µs or -225 µs. Sometimes this sudden misalignment also occurs when changing from sweep to follow. I will continue working on that issue. Any hints or ideas are highly appreciated.

dominicgs, 2016-01-09:
@mikeryan and I have been taking a look at the diff between the fix-clock branch and master.  Overall we think the changes look good and would be happy to merge them.

However, we'd like to leave the `usb_pkt_types` enum in `ubertooth_interface.h`as it is because it's used by some code in Wireshark which we do not control but which is used by a large enough group of people that we don't want to break it at this time.

https://github.com/greatscottgadgets/ubertooth/compare/master...elli89:fix-clock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

elli89, 2016-01-12:
I totally agree. I changed a lot of things and left quite a mess in the code. I will clean it up and file a PR with only the changes that are necessary to fix the issues.

mikeryan, 2016-02-04:
Closing this issue as it appears to be resolved. Please reopen if that's not the case.

Closed 2016-02-04.

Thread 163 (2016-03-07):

Upgrading the Firmware on Ubertooth One

sumeetjauhar, 2016-03-07:
I have been trying to the the ubertooth one started on my ubuntu virtual machine but i have run into some problems.

I followed the installation procedure and now i can see the bluetooth spectrum via the ubertooth-specan-ui command.

However i believe that the firmware on my board is incorrect
ubertooth-util -v
control message unsupported
Firmware revision: error: -9

However attempting to update the firmware seems a tad bit annoying as i get the same "control message unsupported" error.

I believe i hv the same problem as discussed here https://sourceforge.net/p/ubertooth/mailman/message/34582005/ . The fix for it seems to be to jumper the board and force it into DFU mode.

Now i can see the LED flashing for 5 seconds app. But hey i am running a VM and i need to take the USB back into the VM and then run the update firmaware command all in `5 seconds` !!

Is there no easy solution to this problem ? Or do i need a base linux operating system (which i dont have )

sumeetjauhar, 2016-03-07:
Also i automount the Ubertooth to be auto detected on my guest Ubuntu but honestly it takes more than 5 seconds  to get attached .

While it is not yet detected I get the following error :
ubertooth-dfu -d ubertooth-2015-10-R1/ubertooth-one-firmware-bin/bluetooth_rxtx.dfu -r
could not open Ubertooth device
Segmentation fault (core dumped)

When it does get detected ( after 5+sec) I get the a long string of this error message :
control message unsupported
control message unsupported
control message unsupported

Any inputs on how to resolve this problem ?

dominicgs, 2016-03-07:
I'm honestly surprised that it takes more than 5 seconds to get attached to the VM, I've never heard of it taking more than a second or two.

Do you have both USB IDs set up for automatic pass through to the VM?  The regular firmware ID and the DFU ID?
0x1d50 0x6002  Ubertooth One
0x1d50 0x6003  Ubertooth One DFU

If you don't have the DFU ID passed through, it won't appear until after the timeout and the switch back to regular mode.

sumeetjauhar, 2016-03-07:
How do i check that both the USB id have passed . I can see only one

osboxes@osboxes:~$ lsusb
Bus 001 Device 013: ID 80ee:0021 VirtualBox USB Tablet
Bus 001 Device 015: ID ffff:0004
Bus 001 Device 001: ID 1d6b:0001 Linux Foundation 1.1 root hub

sumeetjauhar, 2016-03-07:
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

dominicgs, 2016-03-07:
Ah, you have a slightly older model device where the DFU ID is 0xFFFF 0x0004.  You need to create VirtualBox "USB Device Filters" for each of the IDs.

sumeetjauhar, 2016-03-08:
Yes correct, I bought the Ubertooth hardware quite some time ago but didnt get around to use it.

I dont see the other ID ( Assuming you mean the DFU ID here) . I showed you the screen shot of the Virtual Box USB settings above. How do i enumerate the other ID and add the filter for it ?

sumeetjauhar, 2016-03-08:
Alright a bit more trial and error and finally got the Virtual box to detect the USB within 5 seconds and was able to re-flash my firmware .

osboxes@osboxes:~$ ubertooth-util -v
Firmware revision: 2015-10-R1
osboxes@osboxes:~$ ubertooth-util -V
ubertooth 2015-10-R1 (dominicgs@hydrogen) Mon Oct 12 22:30:56 BST 2015
osboxes@osboxes:~$

Seems good for the moment. Time to setup Kismet and Wireshark.

Thanks for the support.

dominicgs, 2016-03-08:
That's great, I'm glad you managed to get that working.

12424642, 2016-08-17:
Hi Sumeetjauhar and dominicgs, I'm currently facing the exact problem. I've tried making changes to the filter but can seem to resolve it.

Every time I try to update the firmware I get 'could not open Ubertooth device' followed by 'Segmentation fault (core dumped)'

Pleaseee help,
Thanks in advance!

12424642, 2016-08-17:
*can't

dominicgs, 2016-08-17:
Could you give some information about the problem you are having.  The USB IDs that you have filtered?  The IDs that you see from the VM?  The IDs that you see on the host?

12424642, 2016-08-17:
When I attempt to run the following command ‘ubertooth-dfu -d bluetooth_rxtx.dfu -r’ I receive ‘could not open Ubertooth device' followed by 'Segmentation fault (core dumped)'.
Another time it began briefly and the chasing lights lit up on the ubertooth device, but for some reason it gave the following message ‘……………………………………………………………. detached’, the chasing lights continued till I ran the command again.

12424642, 2016-08-17:
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

12424642, 2016-08-17:
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

12424642, 2016-08-17:
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

12424642, 2016-08-17:
These are the filters I set up and the IDs on both the main system as well the vm.

dominicgs, 2016-08-17:
Do you also have a filter set for the Ubertooth when it is in update mode?  It has a different USB ID then - either 0xffff 0x0004, or 0x1d50 0x6003

12424642, 2016-08-17:
So I should add another filter which uses 0xffff 0x0004 so that ubertooth can be identified while updating?
You are possible right because I tried doing all the steps again on my kali machine and it gave me 'switching to DFU mode ...' and 'Unable to find Ubertooth'

dominicgs, 2016-08-17:
Yes, add the additional filter and let me know if it works.

12424642, 2016-08-17:
I've tried it and i'm still getting the same error initially, but when I try running the command again directly afterwards, it gives me the message 'checking firmware signature.....................................Detached'

12424642, 2016-08-17:
If I run the spectrum tool and that detects the Ubertooth, does that confirm the Ubertooth is at least working?

12424642, 2016-08-17:
It's very strange, I used the command 'ubertooth-btle –p -c capture.pcap' and I am able to see the ubertooth device working on the terminal. Still can't seem to carry out a firmware check or update.
Sorry this might be a bit irrelevant but is there command is used to stop the capture and save it to pcap? I seem to just have to close the terminal.

dominicgs, 2016-08-17:
`checking firmware signature.....................................Detached` isn't an error message.  It's a successful firmware load.

12424642, 2016-08-17:
Oh sorry I didn't realise, thank you so much for your help!

ubertooth, 2017-06-19:
We have installed the ubertooth in ubuntu 14.04.

root@zan:~/ubertooth-2017-03-R2/firmware/bluetooth_rxtx# ubertooth-util -v
Firmware version: 2017-03-R2 (API:1.02)

root@zan:~/ubertooth-2017-03-R2/firmware/bluetooth_rxtx# ubertooth-util -V
ubertooth 2017-03-R2 (root@zan) Fri Jun 16 17:43:55 IST 2017

root@zan:~/ubertooth-2017-03-R2/firmware/bluetooth_rxtx# ubertooth-dfu -d bluetooth_rxtx.dfu -r
Switching to DFU mode...
Checking firmware signature
........................................
........................................
.................
Detached

I have got the above msg in console.

Please help

dominicgs, 2017-06-25:
2017-03-R2 is the latest firmware.  The output from `ubertooth-dfu` is as expected.

Closed 2016-03-08.

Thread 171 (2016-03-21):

Bluetooth BLE Capture errors

Nocks932, 2016-03-21:
Hello,
I managed to setup my Ubertoothone using the guild and also tried to update the firmware on it. Im currently running an Ubuntu 14.04LTS, dual boot with win10, so it's not a virtual machine.
When I try to run the : ubertooth-btle -f -c /tmp/pipe i get a strange message : control message unsupported, with no error code to it.
The current firmware of the device is : Firmware revision: 2014-04-R1
Can you help me with this issue ?

dominicgs, 2016-03-29:
@Nocks932 Which version of the host tools are you using?  This error is normally a symptom of a host/firmware version mismatch.  I think you probably need to upgrade your firmware to release 2015-10-R1 to match the host code.

Nocks932, 2016-03-29:
Hey Dominic,
I tried updating the firmware but it doesnt find the ubertooth dongle. The lights are flashing as they should but it doesnt recognise it. I'm currently running ubuntu LTS 14 if that helps.
Thanks in advance.

dominicgs, 2016-03-29:
When the lights are flashing, what shows up when you run `lsusb` ?

Nocks932, 2016-03-29:
Bus 004 Device 004: ID 8086:0189 Intel Corp.
Bus 004 Device 003: ID 04d9:a067 Holtek Semiconductor, Inc.
Bus 004 Device 002: ID 8087:0024 Intel Corp. Integrated Rate Matching Hub
Bus 004 Device 001: ID 1d6b:0002 Linux Foundation 2.0 root hub
Bus 002 Device 001: ID 1d6b:0003 Linux Foundation 3.0 root hub
Bus 001 Device 001: ID 1d6b:0002 Linux Foundation 2.0 root hub
Bus 003 Device 003: ID 1bcf:2881 Sunplus Innovation Technology Inc.
Bus 003 Device 002: ID 8087:0024 Intel Corp. Integrated Rate Matching Hub
Bus 003 Device 001: ID 1d6b:0002 Linux Foundation 2.0 root hub
This is what i get when i run the command

dominicgs, 2016-03-30:
That's very strange, when the lights are flashing it should enumerate with a USB ID of either FFFF:0004 or 1d50:6003

If you connect pins 1 and 3 on the [expansion header](https://github.com/greatscottgadgets/ubertooth/wiki/Ubertooth-One#pins-and-leds) while plugging it in, it should enter DFU mode too.  Could you try that and then `'lsusb` (beware, it has a short timeout before loading the normal firmware)

Nocks932, 2016-03-30:
Hello Dominic,
I tried what you said and this is what happened. I connected pins 1 and 3 as you said and attached it to my computer and the lights started flashing ( i gues this means its entering DFU mode ? ) i immediately typed the lsusb command as you asked and the only different entry i get is :
Bus 001 Device 012: ID 1d50:6002 OpenMoko, Inc.
I'm assuming this is it because the other entries in the list are the same.
Hope this helps.

Nocks932, 2016-04-03:
Hello again DOminic,
Were you able to identify this issue because i need the device working as soon as possible.
Thanks in advance,
Martin.

dominicgs, 2016-04-05:
@Nocks932 The issue appears to be that your host does not see Ubertooth in DFU mode, `Bus 001 Device 012: ID 1d50:6002 OpenMoko, Inc.` is the Ubertooth in regular firmware mode.  This may be a timing thing, the lights flashing suggest that it gets in to DFU mode but it is timing out and entering the regular firmware before that happens.

Could you try the following:
 * Insert the Ubertooth and confirm that `ID 1d50:6002 OpenMoko, Inc.` appears in lsusb
 * Run `ubertooth-util -f`
 * Run `lsusb` again and check for a different device?

Closed 2018-06-27.

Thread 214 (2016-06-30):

cb_rx clock trimming

jbmontgomery4, 2016-06-30:
Not clear on the calibrate Ubertooth clock code found in the cb_rx function in ubertooth_callback.c. It seems for the most part that it prevents packets from being processed. Also the logic seems wrong. The trim_counter test is based on the clk_offset of the previous packet where the the cmd_trim_clock is set with the clk_offset of the current packet. See attached output file near the end. The trim_counter is incremented based on clk_offset > (CLK_TUNE_TIME + CLK_TUNE_OFFSET) and becomes > 8. However, the cmd_trim_clock is set to the clk_offset of the current packet  - CLK_TUNE_TIME which is a negative number. An explanation of what is being done here would be appreciated.

Attached is the modified ubertooth_callback.c file with added printfs, and the output of a run of the ubertooth-rx tool.

Thank you,
John Montgomery

[ubertooth-rx.txt](https://github.com/greatscottgadgets/ubertooth/files/342105/ubertooth-rx.txt)
[ubertooth_callback.c.txt](https://github.com/greatscottgadgets/ubertooth/files/342107/ubertooth_callback.c.txt)

elli89, 2016-07-05:
Your log shows a huge clock drift of the observed piconet. Between two received packets the piconet slips several bits away from the Ubertooth reference clock. The clock trimming procedure should correct that by slowing down or speeding up the Ubertooth clock for one cycle to match the piconet clock.

Since currently the host program receives USB packets from the Ubertooth stick in groups of eight packets, the trim procedure waits until it received eight packets that were out of sync before it tells the Ubertooth stick to trim its clock. Otherwise, in the worst case, it would trim the clock eight times during one USB transmission.

In your log the clock drifts too fast for the trimming algorithm to compensate it. I did not think of that case when I implemented it. Maybe in the future it would be a good idea to extend the clock drift correction in order to correct a constant clock drift and thus a linear clock deviation.

jbmontgomery4, 2016-08-22:
Just downloaded the code as of today. Still do not see any difference with the trimming of the clock. Still does not settle. Attached are execution captures showing what I still see. Any thoughts?

[ubertooth_rx_2.txt](https://github.com/greatscottgadgets/ubertooth/files/431017/ubertooth_rx_2.txt)
[ubertooth-rx.txt](https://github.com/greatscottgadgets/ubertooth/files/431014/ubertooth-rx.txt)

straithe, 2021-05-28:
@jbmontgomery4 are you still experiencing this issue?

straithe, 2021-06-28:
I'm going to close this as there hasn't been a response in a while, but please re-open this issue or open a new one if you still need assistance.

Closed 2021-06-28.

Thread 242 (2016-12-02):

libUSB Error: Command Error:  (-9)

syncharny, 2016-12-02:
### Steps to reproduce
1. Compile libbtb from github
2. Compile ubertooth host from github
3. Compile firmware
4. Run command: _sudo ubertooth-dfu -d bluetooth_rxtx.dfu -r_

### Expected behaviour
Downloads firmware

### Actual behaviour
libUSB Error: Command Error:  (-9)
Switching to DFU mode...
Unable to find Ubertooth

Then the leds scroll up and down on the ubertooth. Ubertooth-util works fine, current version:
sudo ubertooth-util -V
ubertooth 2015-10-R1 (dominicgs@hydrogen) Mon Oct 12 22:30:57 BST 2015

### Version information
**Operating system**:
Ubuntu

**Ubertooth tools version (ubertooth-rx -V):**
libubertooth 0.3 (f85a6a2), libbtbb 0.4 (1eecca5)

**libbtbb version:**

**Ubertooth firmware version (ubertooth-util -v):**
ubertooth 2015-10-R1 (dominicgs@hydrogen) Mon Oct 12 22:30:57 BST 2015

If you are reporting a problem that involves third party software
(Wireshark/Kismet/etc), please report the version here.

### Output
```
libUSB Error: Command Error:  (-9)
Switching to DFU mode...
Unable to find Ubertooth

dominicgs, 2016-12-02:
The error message `libUSB Error: Command Error:  (-9)` is sometimes misleading, especially when we're resetting the device.  The Ubertooth is resetting before returning from the USB request, so the host thinks that it has failed.  You can safely ignore this error in this one case.

However, the `Unable to find Ubertooth` is a problem, especially as the Ubertooth flashes the LEDs to indicate that it's in DFU mode.  For some reason the host cannot see the Ubertooth in DFU mode.

Are you running in a VM?

syncharny, 2016-12-02:
That's interesting, yes I am running a VM on my mac. I can try running from a native linux in the morning when I get to my computer. Thanks for the quick response, I'll let you know if it works or not.

dominicgs, 2016-12-02:
The change in USB IDs means that you'll need to add another USB address filter to your VM setup.  You may find you have performance issues with a VM, but some people report success.

You can also build most of the tools natively on a mac.

Closed 2017-03-01.

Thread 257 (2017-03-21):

New Hardware - USB Does not enumerate

dpitchfo, 2017-03-21:
I have created my own Ubertooth One PCB board and having problems with USB not being enumerated.  I have loaded the bootloader via JFLASH with no luck.

### Steps to reproduce
1.  Created the PCB with LPC1756FB processor from Digikey.
2.  Downloaded and make the ubertooth-2015-10-R1 code following the instructions
https://github.com/greatscottgadgets/ubertooth/wiki/Build-Guide
3.  Make the ./firmware/bootloader and install the bootloader.hex via JFLASH.

### Expected behaviour
I expect the USB to be recognize like the Ubertooth One.

### Actual behaviour
When I plug the USB in and get dmesg:

>dmesg:
[452484.724070] usb 3-8.1.2: new full-speed USB device number 43 using xhci_hcd
[452484.724196] usb 3-8.1.2: Device not responding to setup address.
[452484.928194] usb 3-8.1.2: Device not responding to setup address.
[452485.132077] usb 3-8.1.2: device not accepting address 43, error -71
[452485.132228] usb 3-8.1-port2: unable to enumerate USB device

>lsusb - doesn't appear.

### Version information
**Operating system**:
Ubuntu 16.04

**Ubertooth tools version (ubertooth-rx -V):**
ubertooth-rx -V
libubertooth 0.2 (GITDIR-NOTFOUND), libbtbb 0.3 (GITDIR-NOTFOUND)

**libbtbb version:**
Using libbtbb-2015-10-R1

**Ubertooth firmware version (ubertooth-util -v):**
Using ubertooth-2015-10-R1

If you are reporting a problem that involves third party software
Nope - Just want to get a fresh processor up and running.

### Output
```
Insert any commandline or build output here
```

### Notes
Attached is my schematic.    I did not run out the expansion connector.  I am wondering if I need to short pin 1 & 3 to get into proper mode?    I also used a 20 pin JTAG header since that what I have.   I made my XTAL1 short to ground.   The NXP App note says if you are not using XTAL1, 2, that XTAL1 should be short to gnd and XTAL2 is floating.  (Not sure if this is an issue)

Am I missing something here?

[uber1.pdf](https://github.com/greatscottgadgets/ubertooth/files/859565/uber1.pdf)

mikeryan, 2017-03-21:
Try shorting the pins on the expansion header and see if it will go into bootloader mode and enumerate that way.

https://github.com/greatscottgadgets/ubertooth/blob/master/host/doc/ubertooth-dfu.md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

dpitchfo, 2017-03-21:
Thanks for the quick reply:

No luck on connecting Pin 47 of the MCU to GND.  (This is the same as shorting pin 1 & 2 of the expansion header).   Unfortunately I didn't run the expansion header so soldering a wire to a pin is difficult at best.    I will add that to the next respin.

For the USB, I get the following:
>dmesg
[458909.428054] usb 3-8.1.2: new full-speed USB device number 55 using xhci_hcd
[458909.428177] usb 3-8.1.2: Device not responding to setup address.
[458909.632175] usb 3-8.1.2: Device not responding to setup address.
[458909.836085] usb 3-8.1.2: device not accepting address 55, error -71
[458909.836183] usb 3-8.1-port2: unable to enumerate USB device

Can anyone tell me if I loading the bootloader correctly and using the correct file.   I am pulling the data from /ubertooth-2015-10-R1/firmware/bootloader directory.

1.  make
2.  move the bootloader.hex to windows machine.
3.  Using Segger JFLASH,  Connect the JFLASH, it reads the correct id for the processor.   I load the bootloader.hex and press F5 to write it.   I validate and its written correctly.

The LEDS that appear are RSTLED (Pin 11 of the MCU) and 1V8LED.   Does RSTLED mean anything?  I do not see "Flashing" of the LEDs.

dpitchfo, 2017-04-04:
All,

I found the issue.    I have to blame it on old age and poor eyesight.   I failed to run GIO1 from the MCU to the CC2400.  This prevented the CC2400 to start up and failed at the boot loading process.   Attached is my final schematic that I recreated in Eagle.

[UberToothOne.pdf](https://github.com/greatscottgadgets/ubertooth/files/893349/UberToothOne.pdf)

Closed 2017-04-10.

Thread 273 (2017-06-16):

Ubertooth not being recognized at all

fencingparry4, 2017-06-16:
I'm using a chromebook running ubuntu (not in a VM) and I have been unable to get the computer to see the ubertooth. No commands show the device running and no ubertooth commands are able to find the device. For example, using `lsusb` does not show any devices. Did I do something wrong in setup? (I did all the commands in the build guide from the root directory (/)). There is no way for me to grab the firmware of the device and even touching the pins together as it says in `info ubertooth-dfu`.

It seems like the problem isn't from the ubertooth software itself - its almost as if the board is ejecting itself as soon as its inserted and theres no way to read or write to it.

There are only 2 green lights running - does that mean something?

dominicgs, 2017-06-16:
If you run `dmesg` after inserting the Ubertooth, do you get any output related to USB devices being connected?

fencingparry4, 2017-07-06:
Sorry for the EXTREMELY late response (i went on vacation), I ran the command `dmesg | tail -20` and there were no lines relating to a USB device being inserted

dominicgs, 2017-07-06:
Are you able to plug it in to any other system?

Where did you buy your Ubertooth?

fencingparry4, 2017-07-10:
When I plugged the ubertooth into a raspberry pi, no USB device was recognized in `dmesg | tail -20` - we bought the ubertooth from NooElec off of Amazon

dominicgs, 2017-07-10:
Could you try connecting the two pins in this image as you plug the Ubertooth in?
https://pbs.twimg.com/profile_banners/19587312/1354079866/1500x500

It should put it in to firmware update mode and the LEDs should flash

fencingparry4, 2017-07-11:
I tried doing that and nothing happened - good idea though

dominicgs, 2017-07-11:
It sounds like a hardware problem.  Could you contact NooElec and say that I have helped you diagnose it as a defective unit.  They should replace it for you.

Closed 2020-12-05.

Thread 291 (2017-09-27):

Ubertooth-scan not detecting device that hcitool does

nishant412, 2017-09-27:
### Steps to reproduce
1.Run ubertooth-scan -s -x

### Expected behaviour
It should run hcitool scan using hci0 on my PC followed by an ubertooth-rx and then list the LAP BD_ADDR of devices observed (and if possible resolve the UAP also). I am trying to detect a CSR BC417 based serial-to-bluetooth module (https://www.olimex.com/Products/Components/RF/BLUETOOTH-SERIAL-HC-06/)

### Actual behaviour
While it does list the BD_ADDR of various bluetooth devices, the one device that is paired to it (but not connected) rarely gets listed. I tried doing this test a number of times. The device shows up in the HCI scan almost everytime and yet very rarely does it even show up in ubertooth-rx part of the scan. On the few occasions that it shows up in the scan results, I tried also running ubertooth-rx -l <LAP>, but have never seen UAP resolved. I wanted to ask if you have seen similar behaviour with any other kind of bluetooth devices in the past (Or in case you have tested this particular device out). Also what do you think can be a reason for this behavior? (Maybe I havent correctly understood the algorithm for BlueSniff). I am attaching the output dump from one such scan below.

### Version information
**Operating system: Kali Linux Rolling (and Ubuntu 16.04 LTS)**

**Ubertooth tools version (ubertooth-rx -V) : libubertooth 1.0 (2017-03-R2), libbtbb 1.0 (2017-03-R2)**

**libbtbb version: **

**Ubertooth firmware version (ubertooth-util -v): 2017-03-R2 (API:1.02)**

If you are reporting a problem that involves third party software
(Wireshark/Kismet/etc), please report the version here.

### Output
```
HCI scan
98:D3:32:70:B3:05	stjimmy
Requesting information ...
	BD Address:  98:D3:32:70:B3:05
	Device Name: stjimmy
	LMP Version: 2.1 (0x4) LMP Subversion: 0x100
	Manufacturer: not assigned (6502)
	Features page 0: 0xff 0xff 0x8f 0xfe 0x83 0xe1 0x08 0x80
		<3-slot packets> <5-slot packets> <encryption> <slot offset>
		<timing accuracy> <role switch> <hold mode> <sniff mode>
		<park state> <RSSI> <channel quality> <SCO link> <HV2 packets>
		<HV3 packets> <u-law log> <A-law log> <CVSD> <paging scheme>
		<power control> <transparent SCO> <broadcast encrypt>
		<EDR ACL 2 Mbps> <EDR ACL 3 Mbps> <enhanced iscan>
		<interlaced iscan> <interlaced pscan> <inquiry with RSSI>
		<extended SCO> <EV4 packets> <EV5 packets> <3-slot EDR ACL>
		<5-slot EDR ACL> <EDR eSCO 2 Mbps> <EDR eSCO 3 Mbps>
		<3-slot EDR eSCO> <simple pairing> <extended features>
	Features page 1: 0x01 0x00 0x00 0x00 0x00 0x00 0x00 0x00
	Clock offset: 0x0000
AFH disabled.

Ubertooth scan
systime=1506549290 ch= 6 LAP=7978b1 err=0 clk100ns=6233269 clk1=997 s=-44 n=-55 snr=11
systime=1506549291 ch=31 LAP=7978b1 err=1 clk100ns=15279041 clk1=2444 s=-55 n=-55 snr=0
systime=1506549291 ch=48 LAP=1a84bf err=2 clk100ns=16522899 clk1=2643 s=-75 n=-55 snr=-20
systime=1506549292 ch= 9 LAP=4081dd err=0 clk100ns=24950512 clk1=3992 s=-47 n=-55 snr=8
systime=1506549293 ch=70 LAP=1a84bf err=0 clk100ns=38457752 clk1=6153 s=-63 n=-55 snr=-8
systime=1506549294 ch=29 LAP=1a84bf err=0 clk100ns=44858007 clk1=7177 s=-65 n=-55 snr=-10
systime=1506549294 ch=31 LAP=4081dd err=0 clk100ns=46864151 clk1=7498 s=-43 n=-55 snr=12
systime=1506549295 ch= 5 LAP=e828b9 err=2 clk100ns=52430921 clk1=8388 s=-73 n=-55 snr=-18
systime=1506549295 ch=37 LAP=e828b9 err=1 clk100ns=52820079 clk1=8451 s=-71 n=-55 snr=-16
systime=1506549296 ch=15 LAP=e828b9 err=0 clk100ns=62583333 clk1=10013 s=-55 n=-55 snr=0
systime=1506549296 ch=17 LAP=76adc3 err=0 clk100ns=64601839 clk1=10336 s=-63 n=-55 snr=-8
systime=1506549297 ch=40 LAP=4081dd err=0 clk100ns=71865607 clk1=11498 s=-53 n=-55 snr=2
systime=1506549297 ch=59 LAP=7978b1 err=1 clk100ns=75004491 clk1=12000 s=-71 n=-55 snr=-16
systime=1506549298 ch=33 LAP=e828b9 err=0 clk100ns=80670452 clk1=12907 s=-65 n=-55 snr=-10
systime=1506549298 ch=67 LAP=964bac err=0 clk100ns=82869972 clk1=13259 s=-45 n=-55 snr=10
systime=1506549298 ch= 5 LAP=e828b9 err=1 clk100ns=84029767 clk1=13445 s=-45 n=-55 snr=10
systime=1506549298 ch= 5 LAP=e828b9 err=2 clk100ns=84329913 clk1=13493 s=-62 n=-55 snr=-7
systime=1506549298 ch=37 LAP=e828b9 err=0 clk100ns=84419209 clk1=13507 s=-48 n=-55 snr=7
systime=1506549298 ch=37 LAP=e828b9 err=0 clk100ns=84719405 clk1=13555 s=-70 n=-55 snr=-15
systime=1506549298 ch=26 LAP=4081dd err=0 clk100ns=89502612 clk1=14320 s=-46 n=-55 snr=9
systime=1506549299 ch= 4 LAP=4081dd err=0 clk100ns=99175005 clk1=15868 s=-49 n=-55 snr=6
systime=1506549299 ch=68 LAP=1a84bf err=2 clk100ns=99648995 clk1=15943 s=-73 n=-55 snr=-18
systime=1506549300 ch=40 LAP=1a84bf err=0 clk100ns=103372651 clk1=16539 s=-63 n=-55 snr=-8
systime=1506549300 ch=44 LAP=964bac err=0 clk100ns=107318750 clk1=17171 s=-54 n=-55 snr=1
systime=1506549301 ch=31 LAP=1a84bf err=1 clk100ns=110122323 clk1=17619 s=-73 n=-55 snr=-18
systime=1506549301 ch=37 LAP=4081dd err=0 clk100ns=116078047 clk1=18572 s=-51 n=-55 snr=4
systime=1506549302 ch=13 LAP=7978b1 err=0 clk100ns=123798903 clk1=19808 s=-36 n=-55 snr=19
systime=1506549302 ch=17 LAP=76adc3 err=0 clk100ns=127715834 clk1=20435 s=-63 n=-55 snr=-8
systime=1506549302 ch=34 LAP=4081dd err=0 clk100ns=129127503 clk1=20660 s=-51 n=-55 snr=4
systime=1506549303 ch=68 LAP=964bac err=0 clk100ns=131323521 clk1=21011 s=-64 n=-55 snr=-9
systime=1506549303 ch=40 LAP=1a84bf err=1 clk100ns=134859035 clk1=21577 s=-54 n=-55 snr=1
systime=1506549303 ch=40 LAP=7978b1 err=0 clk100ns=135163168 clk1=21626 s=-32 n=-55 snr=23
systime=1506549303 ch=25 LAP=1a84bf err=2 clk100ns=135661742 clk1=21705 s=-48 n=-55 snr=7
systime=1506549303 ch=42 LAP=7978b1 err=0 clk100ns=136837667 clk1=21894 s=-33 n=-55 snr=22
systime=1506549303 ch=76 LAP=7978b1 err=0 clk100ns=139537675 clk1=22326 s=-39 n=-55 snr=16
systime=1506549304 ch=18 LAP=964bac err=0 clk100ns=144521725 clk1=23123 s=-60 n=-55 snr=-5
systime=1506549304 ch=22 LAP=76adc3 err=1 clk100ns=148418871 clk1=23747 s=-68 n=-55 snr=-13
systime=1506549305 ch=41 LAP=4081dd err=0 clk100ns=151717491 clk1=24274 s=-51 n=-55 snr=4
systime=1506549306 ch=27 LAP=76adc3 err=2 clk100ns=169342561 clk1=27095 s=-71 n=-55 snr=-16
systime=1506549307 ch=61 LAP=1a84bf err=0 clk100ns=171662817 clk1=27466 s=-65 n=-55 snr=-10
systime=1506549307 ch= 1 LAP=76adc3 err=1 clk100ns=174968978 clk1=27995 s=-62 n=-55 snr=-7
systime=1506549307 ch= 5 LAP=1a84bf err=0 clk100ns=178862021 clk1=28618 s=-46 n=-55 snr=9
systime=1506549308 ch= 7 LAP=7978b1 err=0 clk100ns=180836719 clk1=28934 s=-43 n=-55 snr=12
systime=1506549309 ch=32 LAP=4081dd err=0 clk100ns=190078921 clk1=30413 s=-41 n=-55 snr=14
systime=1506549309 ch= 2 LAP=76adc3 err=0 clk100ns=191720095 clk1=30675 s=-63 n=-55 snr=-8
systime=1506549309 ch=66 LAP=1a84bf err=0 clk100ns=192462933 clk1=30794 s=-43 n=-55 snr=12
systime=1506549309 ch= 6 LAP=76adc3 err=0 clk100ns=195881143 clk1=31341 s=-61 n=-55 snr=-6
systime=1506549309 ch=40 LAP=4081dd err=0 clk100ns=198180963 clk1=31709 s=-50 n=-55 snr=5

Scan results:
??:??:??:79:78:B1
AFH map: 0xc0200080000500080010
??:??:??:1A:84:BF
AFH map: 0x200000a2000101205400
??:??:??:40:81:DD
AFH map: 0x10020084250300000000
??:??:??:E8:28:B9
AFH map: 0x20800000220000000000
??:??:??:76:AD:C3
AFH map: 0x46004208000000000000
??:??:??:96:4B:AC
AFH map: 0x00000400001000001800
```

dominicgs, 2017-09-29:
Ubertooth only picks up packets from devices that are currently communicating.  If the module is paired but not connected, then it probably isn't sending any packets for the Ubertooth to find.

nishant412, 2017-09-30:
Hi Dominic,

I agree with that and so I ensured that the device is connected and sending data out.

I'll describe the test I am running . In the case of the module I mentioned, I am running a python script to continuously transmit serial data in an infinite loop. On the master side, I have a laptop connected to the module, and coz it has the SPP , I have a serial port to which I have attached a screen terminal. That way I am certain that data is being sent over Bluetooth.

I see that while ubertooth-scan is able to detect the LAP and resolve the UAP for the master(laptop), I still cant see any packet whatsoever for the slave (HC-06 module).

Thanks
Nishant

dominicgs, 2017-10-02:
Ah, now I understand.  You will always see the master device's LAP and UAP but never the slave LAP/UAP.  This is because all packets use the master device's address in the packets, regardless of direction.

Closed 2020-12-05.

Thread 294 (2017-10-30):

could not open Ubertooth device

rAZeebRuce, 2017-10-30:
I am beginner to ubertooth project. After installation of possible dependencies then I connected ubertooth one to Kali-linux(host)  not sure if ubertooth one has firmware installed

### Expected behaviour
should be detect and run the ubertooth one commands
### Actual behaviour
could not open Ubertooth device;
unable to detect in lsusb even tried with inserted pin as shown in picture https://github.com/greatscottgadgets/ubertooth/wiki/Ubertooth-One#pins-and-leds (can see 5 leds- 2 green, 3 orange & umber)
 for libbtbb-2015-10-R1
~/libbtbb-2015-10-R1/build/ubertooth-2015-10-R1/host/build/spectools# ubertooth-util -v
ubertooth-util: error while loading shared libraries: libubertooth.so.1: cannot open shared object file: No such file or directory

### Version information
**Operating system**:
Kali-Linux
**Ubertooth tools version (ubertooth-rx -V):**
libubertooth 0.2 (GITDIR-NOTFOUND), libbtbb 0.3 (GITDIR-NOTFOUND)
**libbtbb version:**
ubertooth-2017-03-R2
**Ubertooth firmware version (ubertooth-util -v):**
could not open Ubertooth device

If you are reporting a problem that involves third party software
(Wireshark/Kismet/etc), please report the version here.

### Output
```
root@kali:~/ubertooth-2017-03-R2# ubertooth-rx -V
libubertooth 0.2 (GITDIR-NOTFOUND), libbtbb 0.3 (GITDIR-NOTFOUND)
root@kali:~/ubertooth-2017-03-R2# ubertooth-util -v
could not open Ubertooth device
ubertooth-util - command line utility for Ubertooth Zero and Ubertooth One
Usage:
	-a[0-7] get/set power amplifier level
	-b get hardware board id number
	-c[2400-2483] get/set channel in MHz
	-C[0-78] get/set channel
	-d[0-1] get/set all LEDs
	-e start repeater mode
	-f activate flash programming (DFU) mode
	-h display this message
	-i activate In-System Programming (ISP) mode
	-I identify ubertooth device by flashing all LEDs
	-l[0-1] get/set USR LED
	-m display range test result
	-n initiate range test
	-p get microcontroller Part ID
	-q[1-225 (RSSI threshold)] start LED spectrum analyzer
	-r full reset
	-s get microcontroller serial number
	-S stop current operation
	-t intitiate continuous transmit test
	-U<0-7> set ubertooth device to use
	-v get firmware revision number
	-V get compile info
	-z set squelch level
-------------------------------------------------------------------------------------------------------------
~/libbtbb-2015-10-R1/build/ubertooth-2015-10-R1/host/build/spectools# ubertooth-util -v
ubertooth-util: error while loading shared libraries: libubertooth.so.1: cannot open shared object file: No such file or directory

--

....

Deepak111484, 2017-10-30:
corrections- my machin do not have bluetooth adaptor :p

but pls check all other data hope all are proper or pls coreect

mikeryan, 2017-10-30:
Run sudo ldconfig and retry

Deepak111484, 2017-10-31:
Now I have blue adapter detected in kali (rolling) in VM, not able to detect ubertooth one;
(libbtbb-2015-10-R1 & ubertooth-2015-10-R1)

root@kali:~# cat /etc/udev/rules.d/40-ubertooth.rules
# Possible Ubertooth DFU
ATTRS{idVendor}=="ffff", ATTRS{idProduct}=="0004", MODE="0660", GROUP="plugdev"
# Ubertooth Zero
ATTRS{idVendor}=="1d50", ATTRS{idProduct}=="6000", MODE="0660", GROUP="plugdev"
# Ubertooth Zero DFU
ATTRS{idVendor}=="1d50", ATTRS{idProduct}=="6001", MODE="0660", GROUP="plugdev"
# Ubertooth One
ATTRS{idVendor}=="1d50", ATTRS{idProduct}=="6002", MODE="0660", GROUP="plugdev"
# Ubertooth One DFU
ATTRS{idVendor}=="1d50", ATTRS{idProduct}=="6003", MODE="0660", GROUP="plugdev"

kennethblite, 2018-03-08:
Try checking version with ubertooth-dfu. You may have a firmware versioning error, it may tell you to upgrade your firmware to the newest version.

MatteoBaldini, 2018-08-02:
Hello everyone

I have a very similar problem and I'm a noob as well. Whenever I try to run ubertooth-utils -v to get the version the output is "could not open Ubertooth device" followed by all the possible options, none of which works. The device is a UD100 adapter by the way.
I followed the tutorial and never had any errors at any point. If I run blue_hydra  it confirms that there's no ubertooth device.
Any idea as to why? All help is appreciated.

Deepak111484, 2018-08-02:
Hi,

That time only I have sorted out the issue by updating kali Linux with the
latest package. Please verify your build.

All the best.

Thanks,
Deepak

On Thu, 2 Aug 2018, 1:33 am Matteo Baldini, <notifications@github.com>
wrote:

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

mikeryan, 2018-08-02:
Do you have an Ubertooth device? The UD100 is not an Ubertooth, so the tools will not work with it.

philosofonusus, 2019-05-20:
You need to install libbtbb

git clone https://github.com/greatscottgadgets/libbtbb
cd libbtbb
mkdir build
cd build
cmake ..
make
sudo make install
cmake -DINSTALL_DIR=/path/to/install -DINCLUDE_DIR=/path/to/include ..

Closed 2020-12-05.

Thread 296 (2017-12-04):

libUSB Error: Timeout: (-7)

ykram, 2017-12-04:
### Steps to reproduce
1. ubertooth-util -v

### Expected behaviour
Expect to see firmware on device

### Actual behaviour
Receive an error message:

libUSB Error: Timeout:  (-7)
Firmware revision: error: -7

### Version information
Kali 4.13.0-amd64

**Ubertooth tools version (ubertooth-rx -V):**
libubertooth 0.2

**libbtbb version:**
libbtbb 0.3

**Ubertooth firmware version (ubertooth-util -v):**
N/A

If you are reporting a problem that involves third party software
(Wireshark/Kismet/etc), please report the version here.

### Output

Using `lsusb` after initially inserting the device shows:

`iManufacturer        1 Great Scott Gadgets`
`iProduct                 2 Ubertooth One`
`iSerial                     3 <omitted>`
...
`Device Status:         0x0000`
`  (Bus Powered)`

However, after I try to initiate a `ubertooth-util -v`, I receive an error saying that libUSB timed out (-7).

`lsusb -vd 1d50:6002` then shows that

`iManufacturer`, `iProduct` and `iSerial` are all showing as (Error) but the `Device Status` is still 0x0000.

mikeryan, 2017-12-04:
Are you running Kali inside a VM? How many LEDs are lit, and what color are they?

ykram, 2017-12-04:
This Kali being run via USB, not in a VM. I have 3 LEDs lit, 2 green and 1 red.

dominicgs, 2017-12-04:
Do any of the other functions work?  e.g. `ubertooth_util -l`?  It should report the status of the LEDs.

ykram, 2017-12-04:
Unfortunately, they do not. I get:

libUSB Error: Timeout:  (-7)
USR LED Status: -7

dominicgs, 2017-12-04:
How about any of the other tools? e.g.'ubertooth-rx`?

Are you able to run `ubertooth-dfu` to update the firmware to the latest version?

ykram, 2017-12-04:
`ubertooth-rx` and the other tools also return libUSB error -7.

`ubertooth-dfu -d bluetooth_rxtx.dfu -r` gives me the following:

libUSB Error: Operation timed out:  (-7)
Switching to DFU mode...
Unable to find Ubertooth

ykram, 2017-12-04:
I tried installing the tools on a separate linux laptop running Ubuntu 16.04.3 and while I still get the -7 error from libUSB, `ubertool-util -v` gives me somewhat more information:

`libUSB Error: Operation timed out:  (-7)`
`Firmware version: error: -7 (API:1.02)`

dominicgs, 2017-12-04:
I think we'll need to force your Ubertooth in to bootloader mode.  If you have a paper clip you can connect two pins on the expansion header: https://pbs.twimg.com/profile_banners/19587312/1354079866/1500x500

You'll need to run the `ubertooth-dfu -d bluetooth_rxtx.dfu -r` command while the lights are still flashing.

ykram, 2017-12-04:
That looks like it did the trick! ubertooth-util shows the proper version
and capturing in WireShark world as expected. Thank you!

On Sun, Dec 3, 2017 at 8:49 PM Dominic Spill <notifications@github.com>
wrote:

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

Closed 2017-12-04.

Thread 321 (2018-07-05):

Ubertooth one not working

Grassyjansen, 2018-07-05:
### Steps to reproduce
1. After an update of the ubertooth one the device worked
2. Now a few months later the device is not showing on the usb bus when inserted
3. DFU mode by shorting the 2 pins also does not work
4. Tried to flash via the EXPAND port. Connected an FTDI to the RX, TX and GND and shorted CTS to GND
5. Then tried lpc21isp -detectonly /dev/ttyUSB0 115200 4000000 and
lpc21isp -detectonly /dev/ttyUSB0 115200 14746

but "nswer on '?'

What am I doing wrong?

mikeryan, 2018-07-05:
Do any LEDs turn on when you plug it into USB? What color(s)?

dominicgs, 2018-07-05:
In addition to Mike's question about:
I'm rather surprised that DFU mode doesn't work.  What happened to the Ubertooth between steps 1 and 2?

Is there any sign of damage to the USB connector?

Grassyjansen, 2018-07-09:
2 green lights turn on green after plugging it in:
1.8V
USB led

There is no sign of damage on the USB connector

dominicgs, 2018-07-09:
Does anything show up in the output of dmesg when you connect the Ubertooth?

Grassyjansen, 2018-07-13:
No nothing

Grassyjansen, 2018-07-18:
Does this mean the ubertooth is beyond repair? Is there a possibility to flash via the expand port?

dominicgs, 2018-07-28:
I'm rather baffled by this, the bootloader is there for just this sort of situation and it was clearly working initially because you were able to update the firmware (which requires the bootloader).

Where di you buy your Ubertooth from?

Grassyjansen, 2018-09-07:
Good question, it was bought by a colleague who does not work at the company any more. Is there another way to flash the device? For example by flashing via the EXPAND port?

mikeryan, 2020-12-05:
@Grassyjansen if you're still having problems with your Ubertooth, please reopen this issue and we can help you debug it further.

Closed 2020-12-05.

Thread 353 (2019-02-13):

libusb_init failed (got 1.0?)  any idea what I am missing here?

bsb862, 2019-02-13:
I am trying to connect the Ubertooth for the first time. Any idea what the "libusb_init failed (got 1.0?) means?

### Actual behaviour
bouchedag@Bouche-Dag:~/kismet-2013-03-R1b$ ubertooth-rx -z
libusb_init failed (got 1.0?)
ubertooth-rx - passive Classic Bluetooth discovery/decode

Example usage:
        ubertooth-rx -- sniff for all LAPs
        ubertooth-rx -l <lap> -- calculate UAP for a given LAP
        ubertooth-rx -l <lap> -u <uap> -- calculate clock and follow piconet
        ubertooth-rx -z -t 20 -- survey mode: discover all LAPs+UAPs for 20 seconds

Major modes:
        -l <LAP> to decode (6 hex) - if not specified sniff all LAPs
        -u <UAP> to decode (2 hex) - if not specified calculate UAP (requires LAP)
        -z Survey mode - discover and list piconets (implies -s, interrupt with ctrl-C)
        -i <filename> input file - if not specified use Ubertooth for live capture

Configuration:
        -c <BT Channel> set a fixed bluetooth channel [Default: 39]
        -e max_ac_errors (default: 2, range: 0-4)
        -t <SECONDS> sniff timeout - 0 means no timeout [Default: 0]

Output options:
        -r<filename> capture packets to PcapNG file
        -q<filename> capture packets to PCAP file
        -d<filename> dump packets to binary file

Miscellaneous:
        -V print version information
        -U <0-7> set ubertooth device to use
bouchedag@Bouche-Dag:~/kismet-2013-03-R1b$ ubertooth-rx -V
libubertooth 1.1 (2018-08-R1), libbtbb 1.0 (git-6c7b9ff)

### Version information
**Operating system**:
Kali Linux (through windows 10 subsystem for Linux (WSL))
**Ubertooth tools version (ubertooth-rx -V):**

**libbtbb version:**

**Ubertooth firmware version (ubertooth-util -v):**

If you are reporting a problem that involves third party software
(Wireshark/Kismet/etc), please report the version here.

### Output
```

GravesJake, 2019-02-15:
Can you run the commands `ubertooth-rx -V` and `ubertooth-util -v` and paste the output of both here?

GravesJake, 2019-02-15:
Have you tried installing libusb? Instructions can be found in the [Build Guide](https://github.com/greatscottgadgets/ubertooth/wiki/Build-Guide)

bsb862, 2019-02-15:
Hey Jake thanks for responding

bouchedag@Bouche-Dag:~/kismet-2013-03-R1b$ ubertooth-rx -V
libubertooth 1.1 (2018-08-R1), libbtbb 1.0 (git-6c7b9ff)
bouchedag@Bouche-Dag:~/kismet-2013-03-R1b$ ubertooth-util -v
libusb_init failed (got 1.0?)
ubertooth-util - command line utility for Ubertooth Zero and Ubertooth One

Common options:
        -v get firmware revision number
        -V get compile info
        -I identify ubertooth device by flashing all LEDs
        -d[0-1] get/set all LEDs
        -l[0-1] get/set USR LED
        -S stop current operation
        -r full reset
        -U<0-7> set ubertooth device to use
        -N print total number of Uberteeth and exit

Radio options:
        -a[0-7] get/set power amplifier level
        -c[2400-2483] get/set channel in MHz
        -C[0-78] get/set channel
        -q[1-225 (RSSI threshold)] start LED spectrum analyzer
        -t intitiate continuous transmit test
        -z set squelch level

Range test:
        -e start repeater mode
        -m display range test result
        -n initiate range test

Miscellaneous:
        -f activate flash programming (DFU) mode
        -i activate In-System Programming (ISP) mode
        -b get hardware board id number
        -p get microcontroller Part ID
        -s get microcontroller serial number

GravesJake, 2019-02-15:
Sorry, my comments are backwards. Try installing libusb before trying to use any ubertooth tools. How to do so can be found in the [Build Guide](https://github.com/greatscottgadgets/ubertooth/wiki/Build-Guide) as it's OS specific.

bsb862, 2019-02-15:
bouchedag@Bouche-Dag:~$ sudo apt-get install cmake libusb-1.0-0-dev make gcc g++ libbluetooth-dev \
> pkg-config libpcap-dev python-numpy python-pyside python-qt4
Reading package lists... Done
Building dependency tree
Reading state information... Done
cmake is already the newest version (3.13.2-1).
g++ is already the newest version (4:8.2.0-2).
gcc is already the newest version (4:8.2.0-2).
libbluetooth-dev is already the newest version (5.50-1).
libpcap-dev is already the newest version (1.8.1-6).
libusb-1.0-0-dev is already the newest version (2:1.0.22-2).
make is already the newest version (4.2.1-1.2).
pkg-config is already the newest version (0.29-6).
python-numpy is already the newest version (1:1.16.1-1).
python-pyside is already the newest version (1.2.2+source1-3).
python-qt4 is already the newest version (4.12.1+dfsg-2+b1).
The following packages were automatically installed and are no longer required:
  libicu-le-hb0 libicu60
Use 'sudo apt autoremove' to remove them.
0 upgraded, 0 newly installed, 0 to remove and 0 not upgraded.

bsb862, 2019-02-15:
I'm fairly certain I have installed everything correctly, but having trouble getting started :/

bsb862, 2019-02-15:
I mean I'm obviously missing something lol but yeah having trouble figuring it out.

bsb862, 2019-02-18:
Hello, any ideas of what I could be missing? Thank you!

GravesJake, 2019-02-18:
WSL does not appear to have USB support at the moment. You might have to try running Linux directly or in a VM.

bsb862, 2019-02-20:
Ah.. Yes. That would be a problem, wouldn't it? Thank you!

On Mon, Feb 18, 2019 at 5:38 PM Jacob Graves <notifications@github.com>
wrote:

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

Closed 2019-02-22.

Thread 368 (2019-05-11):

Firmware update problems, Could not open Ubertooth device

TheDolli, 2019-05-11:
### Steps to reproduce
1. Installed via these steps [https://github.com/greatscottgadgets/ubertooth/wiki/Build-Guide](url)
2. Attempted for firmware update but was unable to do so.
3.

### Expected behaviour
Being able to see my firmware version after running `ubertooth-util -v`

### Actual behaviour
I am unable to update firmware, nor enter bootloader mode manual by connecting pins 1 and 3. I can see leds flashing when I do so for short while, but after running `ubertooth-dfu -d bluetooth_rxtx.dfu -r` I still get

> could not open Ubertooth device
> Unable to find Ubertooth

### Version information
**Operating system**: Running via Oracle VM with virtual OS Kali 2019 version.

**Ubertooth tools version (ubertooth-rx -V):**
libubertooth 1.1 (2018-12-R1)

**libbtbb version:**  libbtbb 1.0 (git-7860bda*)

**Ubertooth firmware version (ubertooth-util -v):** I cannot get firmware version of it. It cannot open the Ubertooth device.

If you are reporting a problem that involves third party software
(Wireshark/Kismet/etc), please report the version here.

### Output
```
could not open Ubertooth device
ubertooth-util - command line utility for Ubertooth Zero and Ubertooth One

Common options:
	-v get firmware revision number
	-V get compile info
	-I identify ubertooth device by flashing all LEDs
	-d[0-1] get/set all LEDs
	-l[0-1] get/set USR LED
	-S stop current operation
	-r full reset
	-U<0-7> set ubertooth device to use
	-N print total number of Uberteeth and exit

Radio options:
	-a[0-7] get/set power amplifier level
	-c[2400-2483] get/set channel in MHz
	-C[0-78] get/set channel
	-q[1-225 (RSSI threshold)] start LED spectrum analyzer
	-t intitiate continuous transmit test
	-z set squelch level

Range test:
	-e start repeater mode
	-m display range test result
	-n initiate range test

Miscellaneous:
	-f activate flash programming (DFU) mode
	-i activate In-System Programming (ISP) mode
	-b get hardware board id number
	-p get microcontroller Part ID
	-s get microcontroller serial number

```

mossmann, 2019-06-03:
Please try running `ubertooth-dfu -d bluetooth_rxtx.dfu -r` as root. It is important to execute this command quickly (within a couple seconds) after using pins 1 and 3 to enter bootloader mode.

TheDolli, 2019-07-01:
I did try to do so. Eventually I did not discover why I had such problems with ubertooth, however, I discovered it has something to do with device I tried to run it on itself. I tried out various virtual OS, all of them had same issue in the very end: They were unable to see the ubertooth devica, no matter what I tried.
Therefore, I was unable to run `ubertooth-dfu -d bluetooth_rxtx.dfu -r`
After I decided to try ubertooth out on other devices I successfuly interacted with the device on raspberry pi, although different unrelated issues araised there, and then on MacOs where ubertooth worked without any issues.
First laptop I tried ubertooth to run on is LenovoIdeaPad Yoga 3 14. I might try to discovered where the issues laid in future, however for now I switched to different device as it is more convenient.

mossmann, 2019-07-03:
Interesting.  It sounds like your firmware issue is resolved.  If you would like help getting the Ubertooth to work with a particular host platform, please open another issue.  (As a start, i suggest watching dmesg while plugging it in.)

Sonali433, 2022-05-29:
hi there,

I have configured for ubertooth one Kali linux. But unfortunately, I am unable to contact with it. Getting the message;

ubertooth-util -v                                                                                                                                               11 ⚙
could not open Ubertooth device
ubertooth-util - command line utility for Ubertooth Zero and Ubertooth One

Common options:
	-v get firmware revision number
	-V get compile info
	-I identify ubertooth device by flashing all LEDs
	-d[0-1] get/set all LEDs
	-l[0-1] get/set USR LED
	-S stop current operation
	-r full reset
	-U<0-7> set ubertooth device to use
	-N print total number of Uberteeth and exit

Radio options:
	-a[0-7] get/set power amplifier level
	-c[2400-2483] get/set channel in MHz
	-C[0-78] get/set channel
	-q[1-225 (RSSI threshold)] start LED spectrum analyzer
	-t intitiate continuous transmit test
	-z set squelch level

Range test:
	-e start repeater mode
	-m display range test result
	-n initiate range test

Miscellaneous:
	-f activate flash programming (DFU) mode
	-i activate In-System Programming (ISP) mode
	-b get hardware board id number
	-p get microcontroller Part ID
	-s get microcontroller serial number
	-x xmas lights
------------------------------------------------------------------------
#  ubertooth-specan-ui                                                                                                                                        1 ⨯ 11 ⚙
QStandardPaths: XDG_RUNTIME_DIR not set, defaulting to '/tmp/runtime-root'
Could not open Ubertooth device
Failed to run:  ubertooth-specan -d - -l 2400 -u 2483 -U -1

Closed 2019-07-03.

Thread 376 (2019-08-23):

USB device not recognised

HeideFisher, 2019-08-23:
### Steps to reproduce
1. Inserting Ubertooth in Windows machine
2.
3.

### Actual behaviour
An error message showed 'The last USB device you connected to with this computer malfulnctioned and Windows does not recognise it.

### Version information
Windows 10:

I have downloaded the libbtbb-2012-10-R3 and ubertooth-2018-12-R1 into the kali linux operating system which is running on VMWare on my WIndow10 machine. My machine does not seem to read the ubertooth USB.

I have also tried to insert the Ubertooth USB directly into my Raspberry Pi 3 (after downloading libbtbb-2017-03-R2 and ubertooth-2017-03-R2) and again it was not recognised.
If I run ubertooth-util -v the error message is the same on both machines 'could not open Ubertooth device'

EMCP, 2019-09-09:
I think you may need to check your devices LEDs.. because mine has been working fine off a RPi3

HeideFisher, 2019-09-10:
I thought it would work off a RPi3. When I plug the Ubertooth into my Pi the lights do not even go on. Maybe my device is broken ??

EMCP, 2019-09-10:
correct, if it isn't even getting power to the LEDs thats a bad sign.. I don't know how you'd debug that though and you may want to research that part

luzat, 2020-06-15:
I  received a device which was missing Q1 and R15. In this case, many things (testing, flashing through FTDI programmer) seemed to work, except USB. Checking whether all components are in their place and going through firmware/assembly_test and usb_test might be helpful (if interested in fixing it instead of having it replaced).

BG7YWL, 2020-07-05:
> I received a device which was missing Q1 and R15. In this case, many things (testing, flashing through FTDI programmer) seemed to work, except USB. Checking whether all components are in their place and going through firmware/assembly_test and usb_test might be helpful (if interested in fixing it instead of having it replaced).

I tried assembly_set and usb_test and found that the USB light could not be turned on, please tell me where to check the circuit.
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

mikeryan, 2020-12-01:
@HeideFisher it sounds like your device may be defective. Where did you buy it from?

straithe, 2021-05-28:
I'm going to close this as there hasn't been a response in a while, but please re-open this issue or open a new one if you still need assistance.

Closed 2021-05-28.

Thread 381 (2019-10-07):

Ubertooth won't enter DFU

huntergregal, 2019-10-07:
I have an ubertooth i got a few years ago (still new in package) from Defcon. has `r161-p9` code on it.

Any tool i try to use tells me that it cannot open the ubertooth device. So I figure i need to short pins 1/3 and enter DFU to firmware upgrade it.

...Only no matter what i used to bridge the pins the 2 solid green lights stay on when i plug it and and lsusb/dmesg has no change. It just appears this ubertooth will NOT go into DFU mode.

I'm sure I'm bridging the correct pins as per the photo on the wiki.

Any ideas? I'd assume it's dead if it wasn't for the 2 solid green lights signalling it has power. (RSTLED and 1V8 LED)

https://github.com/greatscottgadgets/ubertooth/wiki/Ubertooth-One#pins-and-leds

huntergregal, 2019-10-07:
In addition is there something I could do to flash it manually over jtag or another interface?

mikeryan, 2019-10-07:
What kind of device are you plugging the Ubertooth into? On some OS X machines I've seen them being totally unwilling to enumerate or boot. Can you try in a Windows or Linux machine if you haven't yet?

huntergregal, 2019-10-07:
this is laptop running bare metal ubuntu 18. I have access to windows machine as well but didn't feel like playing  the vmware device pass through game

mikeryan, 2019-10-07:
This sounds like a problem with the bootloader. You can use a [pogoprog](https://github.com/greatscottgadgets/ubertooth/tree/master/hardware/pogoprog) to program it if you want to build some hardware. There is also an unpopulated standard ARM SWD header on top of the board.

Paging @mossmann who can help rule out whether this is a hardware problem and/or give you some other options.

huntergregal, 2019-10-07:
I'm pretty positive it's hardware at this point. I had a theory it could be a bad ground pin and was playing around trying to bridge pin 3 to any ground and while using the usb connector as a ground i got into dfu. of course i wasn't expected that to work and missed my flash opportunity and now i cant get back into dfu :(

It's "safe" to perma bridge pin 3 right? like to always boot into dfu first? I'm thinking ive soldering it to help. Seems like it may actually be a case of a wonky pin 3

mikeryan, 2019-10-07:
It is safe to permanently short pin 3 to ground via pin 1. It will boot into DFU for 5 seconds and then boot into normal mode.

huntergregal, 2019-10-07:
so i put a 6 pronged head on the expand header and used a jumper for pins 1/3 - no dice.

Before this the annular ring (?) on the top side pin 3 hole was chipping off. Now im concerned that may be related to the issues. I'm pretty dead set on fixing this now -- ill probably pull the head back off and play with this a bit. I'd really like to get it working for some new security projects .

Thanks for your help. I'll go ahead and close this issue and open another one if i need to as things progress.

huntergregal, 2019-10-07:
follow up - i pulled up the kicad file and found the expand pin 3 connects to pin 44 on the chip. tried grounding just that pin and nothing is happening when i plug it in. (I know it's the right pin because i confirmed the usb led pin does in fact turn on the usb led when i ground it). So im gonna assume it's dead.

I think i'll bite the bullet and get the hack rf

Closed 2019-10-07.

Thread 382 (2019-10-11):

Could not open Ubertooth device ('Failed to run: ', 'ubertooth-specan -d - -l 2400 -u 2483 -U -1')

AntonioDeterville, 2019-10-11:
### Steps to reproduce
1. Installed all drivers and Libraries for Ubertooth successfully
2. Tried to run "ubertooth-specan-ui" command
3. Recevied the following Error:
Could not open Ubertooth device ('Failed to run: ', 'ubertooth-specan -d - -l 2400 -u 2483 -U -1')

### Expected behaviour
Ideally, the Ubertooth Spectrum UI should open up and give an graphical view of the signals the Ubertooth should be picking up.

### Actual behaviour
I receive the error I described before: Could not open Ubertooth device ('Failed to run: ', 'ubertooth-specan -d - -l 2400 -u 2483 -U -1')

### Version information
**Operating system**: Using Virtual machine version 6.0.12
Running Ubuntu 18.04.3 LTS

**Ubertooth tools version (ubertooth-rx -V):** ubertooth-2018-12-R1

**libbtbb version:** libbtbb-2018-12-R1

**Ubertooth firmware version (ubertooth-util -v):** Honestly not sure which firmware, it should be the lastest one since i followed the Build guide on the GitHub Wiki.

If you are reporting a problem that involves third party software
(Wireshark/Kismet/etc), please report the version here.

### Output
```

I have tried adding my user account to the "vboxusers" group, and have already allowed the ubertooth device through the filter in Virtual Box. I also tried updating all the drivers using sudo apt-get upgrade, and tried reinstalling the libbtbb library.  I am new to Linux, so any guidance on how to solve this issue would be deeply appreciated. When i plug in the Ubertooth, the Host System (Windows 10) recognized the device normally, but the second I start the VM, the red LED on the Ubertooth goes off and the system no longer recognizes it.

AntonioDeterville, 2019-10-11:
Sorry, New to posting here, just adding the part that was in the output window:

I have tried adding my user account to the "vboxusers" group, and have already allowed the ubertooth device through the filter in Virtual Box. I also tried updating all the drivers using sudo apt-get upgrade, and tried reinstalling the libbtbb library.  I am new to Linux, so any guidance on how to solve this issue would be deeply appreciated. When i plug in the Ubertooth, the Host System (Windows 10) recognized the device normally, but the second I start the VM, the red LED on the Ubertooth goes off and the system no longer recognizes it.

mikeryan, 2019-10-11:
Please paste the output of ubertooth-util -v and lsusb

AntonioDeterville, 2019-10-12:
Good Afternoon, thank you for the prompt response, appreciated. Below is the output of ubertooth-util -v (doesn't seem to bringing up the version number though):
could not open Ubertooth device
ubertooth-util - command line utility for Ubertooth Zero and Ubertooth One

Common options:
	-v get firmware revision number
	-V get compile info
	-I identify ubertooth device by flashing all LEDs
	-d[0-1] get/set all LEDs
	-l[0-1] get/set USR LED
	-S stop current operation
	-r full reset
	-U<0-7> set ubertooth device to use
	-N print total number of Uberteeth and exit

Radio options:
	-a[0-7] get/set power amplifier level
	-c[2400-2483] get/set channel in MHz
	-C[0-78] get/set channel
	-q[1-225 (RSSI threshold)] start LED spectrum analyzer
	-t intitiate continuous transmit test
	-z set squelch level

Range test:
	-e start repeater mode
	-m display range test result
	-n initiate range test

Miscellaneous:
	-f activate flash programming (DFU) mode
	-i activate In-System Programming (ISP) mode
	-b get hardware board id number
	-p get microcontroller Part ID
	-s get microcontroller serial number

Below is the output for lsusb:
Bus 001 Device 002: ID 80ee:0021 VirtualBox USB Tablet
Bus 001 Device 001: ID 1d6b:0001 Linux Foundation 1.1 root hub
Hope this clarifies my problem

AntonioDeterville, 2019-10-23:
Good Night, after much trial and error, I found a website that i followed the steps to get the module working on my Linux Ubuntu Machine. Leaving the link in this comment for anyone who encounters the same problem. It seems that this was an issue with refreshing the libraries for the Ubertooth, and also the firmware running may be too outdated. This website gives step by step instructions on how to fix it. Hope this helps someone else one day.
http://installfights.blogspot.com/2016/07/install-and-configure-ubertooth-one.html

Closed 2019-10-23.

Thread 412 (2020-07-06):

DIY hardware is having problems

BG7YWL, 2020-07-06:
### Version information
**Operating system**: Raspberrypi 3B Linux 4.19.118-v7+

**Ubertooth tools version**: ubertooth-2018-12-R1

**libbtbb version**: libbtbb-2018-12-R1

### Steps to reproduce
I make the hardware with the Version 218 Gerber file and use the assembly_test firmware for my test.

It was found that only 1V8 LED(D1) and TX LED(D2) were lit. Then I used a multimeter to measure the 74 and 73 pins of LPC1754 chip, and found that the voltage was only 2.4mV, and the voltage of 73 and 72 pins was 3.1V.

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

In addition, I tested the USB_test program and found that the USB LED(D6) could not be lit. Could you please tell me how to troubleshoot the problem?

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

miek, 2020-07-15:
The best way to troubleshoot is to follow the guide for the assembly_test firmware here under 'Automated Test': https://github.com/greatscottgadgets/ubertooth/tree/master/firmware/assembly_test

It sounds like step 6 is not happening as described ("RX" (D3) is not illuminating)? Are the steps 2-5 passing correctly?

BG7YWL, 2020-07-16:
There was a problem in the second step, TX (D2), RX (D3), USR (D4) did not flash, check the adjacent resistance, the resistance value is normal, the pin connected to U4 chip is also normal, but the voltage is only 2.6mv

BG7YWL, 2020-07-17:
I measured the voltage of 6 pin of U1 and 51 pin of U4, and found that there is only 2.4mv, the normal should be 3.3V

Closed 2020-07-22.

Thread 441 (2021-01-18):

About hardware version issues

BG7YWL, 2021-01-18:
I have two Ubertooth One. R161 and R218 versions, respectively.
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

I noticed that GSG previously sold the R238 version of the Ubertooth One, then switched it to the R161 version for some reason.

I checked the open source material on GitHub and saw that the latest version of the hardware is consistent with the R218 version, and why GSG uniformly sells the R161 version of Ubertooth.

Because GSG has been selling version R161 and developers are also using version R161 for development, I will always report errors when using version R218 hardware to capture packages.

I'm using the latest 2020-12-R1 firmware and I'm getting an "Error: attempt to read past end of buffer" error.

This error has been resolved in the 2018-06-R1 version by searching issues.https://github.com/greatscottgadgets/ubertooth/issues/270#issuecomment-400824574

So, I'd like to ask why GSG has been selling version R161 while GitHub's latest open source hardware version is version R218. And I don't know any information about the R161 version on GitHub.

zhaohuansi, 2021-01-21:
@mossmann

mossmann, 2021-01-23:
Great Scott Gadgets has never sold anything but r161 to date. Your Rev 218 board was manufactured by someone else. Are you having trouble with the GSG unit?

BG7YWL, 2021-01-24:
> Great Scott Gadgets has never sold anything but r161 to date. Your Rev 218 board was manufactured by someone else. Are you having trouble with the GSG unit?

Dear Mr. Mossmann, thank you for your reply.
I'm curious why GSG has been selling the R161 version of hardware while GitHub's latest open source version of hardware is R218.
I bought the hardware of R218 from Taobao a few years ago, and the vendor said that the equipment came from SparkFun. Through testing, I found that there were many bugs in the software operation, but there were no such problems in the version of R161.

straithe, 2021-02-18:
Where are you seeing that GitHub's latest open source version of hardware is R218?

BG7YWL, 2021-02-19:
I'm not sure about the latest hardware version of GitHub's open source, but it's the same as the R218 version that SparkFun makes public.
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

mossmann, 2021-03-02:
Long ago we used Subversion (svn) for revision control for project Ubertooth. I had it configured to automatically update the PCB silkscreen with the svn commit number (which was sequential). We finalized the PCB for production as of svn commit 161, so that number appears on the silkscreen of the units we manufactured. Over time the svn commit numbers went up from there, mostly because of software changes, so some gerber files (PCB fabrication outputs) and other documentation files were produced that had numbers higher than 161. Evidently we were at svn commit 218 when I gave documentation to SparkFun for their web site.

The manufacturer of your r218 unit probably used gerber files from the SparkFun site, but I am certain that SparkFun did not manufacture that unit. (SparkFun has always purchased Ubertooth One from Great Scott Gadgets.)

Eventually we switched from svn to git and migrated to GitHub. Since then we have not had automatic updates of the silkscreen (partly because git commit hashes are not sequential).

There have not been any significant changes to the Ubertooth One hardware design since r161, so we at Great Scott Gadgets continue to use r161 on the silkscreen of the units we produce.

Units with numbers higher than 161 should not be functionally different unless there was some error made by their manufacturer. If your r218 unit does not perform correctly, you can try updating the firmware. If it has the same firmware as your r161 unit and still does not work correctly, I suggest contacting the seller of the faulty unit.

Closed 2021-03-02.

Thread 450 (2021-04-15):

Programming firmware on custom PCB results in no USB activity

supamas, 2021-04-15:
caveat - I'm not a super strong programmer :)
### Steps to reproduce
1. Blank LPC1758
2. Program via UART in ISP mode after reset, Flash Magic on windows to bluetooth_rx_only.hex, verified hex against programmed LPC1758 and came back as a match
3. Cycle power and observe USB data lines

Also, I tried using an arch linux machine with lpc21isp and saw different results output below.

### Expected behaviour
I was expecting some activity on the data lines after programming and a reset but am not seeing any activity at all.

### Actual behaviour
No behavior on the usb data lines.  In fact, it doesn't look like it's executing any code at all.

### Version information
- Windows 10 for Flash magic
- Arch Linux as a USB host

**Ubertooth tools version (ubertooth-rx -V):**
n/a I think
**libbtbb version:**

**Ubertooth firmware version (ubertooth-util -v):**
unknown because I can't talk to the chip to extract that - firmware was taken from the git repo

If you are reporting a problem that involves third party software
- flash magic
- lpc21isp

### Output
When using flash magic, flash compare comes back good.

lpc21isp:
USB3 is my ftdi friend by adafruit.  When in ISP mode I can see that the auto-baud seems to catch and it's trying to program.  At the end when it goes to verify it comes back saying  "
```
./lpc21isp -verify -debug3 -hex bluetooth_rx_only.hex /dev/ttyUSB3 115200 14746
...
COMPARE_ERROR: Source and destination data not equal.
```

supamas, 2021-04-15:
Something to add:
I didn't realize I had populated an LPC1758 instead of the LPC1756 I see on the Ubertooth One board I have.  Do I have to compile the firmware for a specific chip version?  I noticed that the SRAM and Flash on the 1758 is twice the 1756.  Would that cause programming issues?

supamas, 2021-04-20:
To build on this...

So I noticed that the XTAL input was not getting 12 MHz from the CC2400 chip.  I double checked my schematic and noticed that the GUARD pin was tied to 1.8V 🤦‍♂️

I think I have been programming the chip correctly so I took off a capacitor and supplied an external 12 MHz expecting to see USB activity but I ended up not seeing anything.

pmcna, 2021-04-28:
Issue originated on my custom PCB.

I don't see an option for closing this but this can be closed.

Closed 2021-04-28.

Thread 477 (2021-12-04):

Ubertooth running on OSX with Kismet

sagfed, 2021-12-04:
### Steps to reproduce
1.install ubertooth-2020-12-R1
2.install kismet from git
https://www.kismetwireless.net/git/kismet.git
3. run kismet -c ubertooth

### Expected behaviour
To see BTLE list of scan using Ubertooth device via kismet on ImacOSX

### Actual behaviour
Only one or two BTLE appears from apple probably linked to my Imac (see screen capture here attached)

### Version information
OSX:10.14.6

**Ubertooth tools version (ubertooth-rx -V):**
Libubertooth 1.1 (2020-12-R1)
**libbtbb version:**
Libbtbb 1.0 (2018-06-R1)
**Ubertooth firmware version (ubertooth-util -v):**
Libubertooht 1.1 (2020-12-R1), libbtbb (2018-06-R1)

If you are reporting a problem that involves third party software
(Wireshark/Kismet/etc), please report the version here.

### Output
Screen capture, see here attached
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

Insert any commandline or build output here
sudo kismet -c ubertooth

straithe, 2021-12-04:
Have you opened this issue in the Kismet repository?

sagfed, 2021-12-04:
Yes under the #402, thank you

I was then able after recompilation to see the ubertooth device via kismet
and after its activation only one BTLE device can been visible and all the
other one are not shown …

Don’t know yet, if it is kismet issue or thé ubertooth  driver that I
cannot compile ?

The screen print are from Kismet however you could refer to Kismet/#402
ticket …

Thank you in advance,

Sagfed

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

straithe, 2021-12-04:
Thank you for the extra information!

Based on the report we got in #476 we are thinking this is a Kismet issue since Ubertooth functionality when not using Kismet is working fine.

sagfed, 2021-12-04:
Probably right however :

The only issue as pointed out in the Kismet topic, is that the driver for
Kismet ubertooth is provided by greatscottgadgets, if I have understood
correctly.

Therefore, this driver cannot compile due a legacy issue (from one library
packet-source.h not provided) and according some other forum discussion as
well. (See in that respect #288 in which it is stated that the
Ubertooth-Kismet is no longer built.)

On the top of this it seems that the Kismet version 2021 could work without
it, but TBC because in my case it doesn’t, you could see in the screen
capture that the related packet BTLE are scanning neither my iPhone
Bluetooth when I switch it on.

See the 2 screen capture …

So the main question is if it is due to the driver or to the kismet SW that
seems to have replaced this driver  ?
This is the answer I would like to know …

So, I am waiting also the analysis of the Kismet forum on this related
topic.

Thank you in advance,

Sagfed

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

straithe, 2022-07-15:
Can you please provide a link to the issue you opened with Kismet?

straithe, 2022-12-05:
I'm closing this as there hasn't been a response in over 30 days. Please re-open this issue or open a new one if you still need assistance.

Closed 2022-12-05.

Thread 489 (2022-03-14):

Ubertooth One does not show in ioreg or lsusb on MacOS Monterrey; Green Leds show

rebelbot, 2022-03-14:
### Steps to reproduce
1. Plug device into mac.
2. Run: **ioreg -p IOUSB -l -w 0 | grep Ubertooth**  or **lsusb**
3. Notice that nothing regarding ubertooth shows up. Also notice that running DFU also doesn't work.

### Expected behaviour
Commands yeild a device on the system. I have tried multiple Macs.

### Actual behaviour
All other devices enumerate including hubs and internal devices but not this device.

### Version information
**Operating system**: Mac OS Monterrey

**Ubertooth tools version (ubertooth-rx -V):** r161-p11, Don't have more details from the board. Bought several years ago but opened just now.

**libbtbb version:** N/A

**Ubertooth firmware version (ubertooth-util -v):**??? whatever was flashed on it in ~2017 from factory.

If you are reporting a problem that involves third party software
(Wireshark/Kismet/etc), please report the version here.

### Output
```
$ ioreg -p IOUSB -l -w 0 | grep Ubertooth
$
```

rebelbot, 2022-03-17:
Handed off to @mikeryan today. I am still expecting that it will not enumerate on USB. Also found that I bought this back in 2016 (and only opened it now!).

husky-koglhof, 2022-03-23:
Hi, I've used these documentation: [https://codemuch.net/posts/bluetooth-hacking/](https://codemuch.net/posts/bluetooth-hacking/)
Switched to ignore case at ioreg command and it works!
`ioreg -p IOUSB -l -w 0 | grep -i ubertooth`

straithe, 2022-04-07:
@rebelbot are there any updates?

rebelbot, 2022-04-08:
Just got it back today. The HW is not faulty and the firmware was updated to recent version as opposed to 2015 time frame.

straithe, 2022-04-28:
May I close this issue now, or do you still need assistance?

rebelbot, 2022-04-29:
We can close this for now.

Closed 2022-04-29.

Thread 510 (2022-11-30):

Capture EDR packet

123lw, 2022-11-30:
hello! I have a problem： the ubertooth one device can capture the EDR packet and parse it?

straithe, 2022-12-02:
Ubertooth One does not support EDR. Thank you for asking.

Closed 2022-12-02.

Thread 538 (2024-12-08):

Ubertooth One not booting into DFU mode and not showing any packets during capture

btle0812, 2024-12-08:
Recently an Ubertooth One board has been purchased. Its firmware version appeared to be not the latest, but 2018-12-R1. When trying to flash the latest firmware version 2020-12-R1 with `ubertooth-dfu`, the application was unable to find Ubertooth because the board reboots still in regular mode (USB ID 1d50:6002) instead of DFU mode (USB ID 1d50:6003).

An attempt of rebooting into DFU mode with `ubertooth-util -f` gives the same result, the board reboots in regular mode. Even shorting pins 1 and 3 on the Expand connector before plugging in USB doesn't make the device to go to DFU mode.

### Steps to reproduce
1. Run `ubertooth-dfu -d ubertooth-one-firmware-bin/bluetooth_rxtx.dfu` or `ubertooth-util -f`.

### Expected behaviour
Ubertooth One board reboots in DFU mode and is recognized as 1d50:6003 USB device. Then the firmware can be flashed.

### Actual behaviour
Ubertooth One board reboots in regular mode, it is not detected by `ubertooth-dfu`, thus firmware can't be flashed.

### Version information
Ubuntu 20.04

**Ubertooth tools and libbtbb version (ubertooth-rx -V):**
Tried two versions.
libubertooth 1.1 (2018-12-R1), libbtbb 1.0 (2018-06-R1)
libubertooth 1.1 (2020-12-R1), libbtbb 1.0 (2018-06-R1)

**Ubertooth firmware version (ubertooth-util -v):**
2018-12-R1 (API:1.06)

Moreover, the board is not receiving any packets with `ubertooth-rx` and `ubertooth-btle -n`. We could assume that this specific board is faulty, but later more devices were obtained from other sellers and all of them are demonstrating identical behavior! I realize that these boards are made by unknown manufacturers now and may differ from the original model (note "SMA-CONN" label near the antenna connector in place of "rxxx-px" label of the original boards).
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

Maybe I'm missing some important step in the firmware flashing or the initial preparation of the Ubertooth board? The previous similar board from several years ago is flashable and has been working correctly for a long time.

CursedOddity, 2025-01-01:
I have the exact same issue.

Tried shorting pins 1-3 to manually force DFU mode as directed. tried with usb boot and my pi5 as i was told issue arise with VMs and usb for ubertooth. still nothing.

Im wondering maybe you bought your ubertooth from the same place as me and they are just defective.

btle0812, 2025-01-12:
More devices have been obtained from multiple sellers, they can be divided into 3 categories.

1. With "SMA-CONN" label. Is recognized by Ubertooth software, but does not switch to DFU mode with any of the methods and is not receiving any packets.
2. Without label. Not recognized as an USB device at all, not booting in DFU mode with pins 1 and 3 shorted.
3. With "$Rev$" label. Came with the latest 2020-12-R1 firmware and is working!

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

ukoda, 2025-01-20:
I have one the "SMA-CONN" with label from Banggood, https://www.banggood.com/Ubertooth-One-Bluetooth-Protocol-Analyzer-for-Bluetooth-Sniffer-Experimentation-Build-in-LPC175x-ARM-Cortex-M3-Controller-RP-SMA-Connector-P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, which has the same problem.  It reports Firmware version: 2018-12-R1 (API:1.06) but will not go into DFU mode to upgrade to API:1.07.

btle0812, 2025-01-21:
The working device with "$Rev$" was obtained from this seller. https://www.aliexpress.com/item/3256806895521791.html

ukoda, 2025-01-21:
There is disagreement between the KiCAD schematic in this repo at https://github.com/greatscottgadgets/ubertooth/tree/master/hardware/ubertooth-one and the documentation at https://ubertooth.readthedocs.io/en/latest/firmware.html around the 6 pin header.  Looking at the actual board I suspect repo schematic is either wrong or very badly out of date.  I think the readthedocs pages is more trustworthy.

Specifically only pin 1, ground matches, all others are different.  On the schematic pin 3 is not connected but on the physical board there is clearly a track, hence believing the readthedocs version of that connector.  I can provide a PDF of the schematic if needed but I am reluctant to attach it here.  If it was to be pick up as being correct and referenced then it could add to any future confusion.

ukoda, 2025-01-22:
Ok from the processor data sheet it does indeed look like you can flash the processor to stop future updates.  If the factory wanted to protect 'their' IP they could do this.  I have done development and manufacture in China and it is common for factories to lock down processors by default.  It is entirely possible the person on the assembly line flashing the processors is not aware that this is open source software and protected the chip like every product he was asked to flash before.

This is currently all speculation.  The relevant part of the datasheet reads:

**8.30.3 Code security (Code Read Protection - CRP)**
This feature of the LPC1759/58/56/54/52/51 allows user to enable different levels of
security in the system so that access to the on-chip flash and use of the JTAG and ISP
can be restricted. When needed, CRP is invoked by programming a specific pattern into a
dedicated flash location. IAP commands are not affected by the CRP.

There are three levels of the Code Read Protection.

CRP1 disables access to chip via the JTAG and allows partial flash update (excluding
flash sector 0) using a limited set of the ISP commands. This mode is useful when CRP is
required and flash field updates are needed but all sectors can not be erased.

CRP2 disables access to chip via the JTAG and only allows full flash erase and update
using a reduced set of the ISP commands.

Running an application with level CRP3 selected fully disables any access to chip via the
JTAG pins and the ISP. This mode effectively disables ISP override using P2[10] pin, too.

ukoda, 2025-01-22:
Ok I have resolved the disagreement between the KiCAD schematic in this repo and readthedocs and both are correct.  This the schematic if you want to save time opening KiCAD and updating.

[ubertooth-one_sch.pdf](https://github.com/user-attachments/files/18499005/ubertooth-one_sch.pdf)

The readthedocs suggestion of shorting pins 1 and 3 of J4 will not invoke the LPC1754 ROM bootloader, it must be using a boot loader in the existing firmware.

The ISP connector I was looking for is not actually a connector, which is why I was confused.  It is a series of rectangular pads on the rear side of the PCB only, near the JTAG connector.  Pin 1 is towards the SMA end of the board.  If you short pins 1 and 2 then reset by briefly shorting pins 1 and 6 you should get access to a serial port ISP command interface with comms on pins 4 and 5.  The protocol looks easy to work with in Python so I'm assuming there is plenty of software to do the out there, haven't looked yet.  The data sheets suggest this works in all cases, except if CRP3 is active.

The easy option is to solder to these pads and try it.  However as I have failure case open with Banggood I no want to solder to the board in case I have to return it.  I was going to make a pogo pin adaptor for it instead but note the pin pitch is unusual making that a bit more complicated.

ukoda, 2025-01-23:
Good news, using a probe jig and a USB to serial adaptor I was able to access the bootloader ROM and flash new code so mine is now running API 1.07.  I have not tried to put it into DFU mode as it now has the code I need.  The page https://ubertooth.readthedocs.io/en/latest/programming.html has more detail about this process.  So, for mine at least, the CRP is not active, making it recoverable.

ukoda, 2025-01-27:
Just close out things from my experience here is the response I got from Banggood that appears to backup up what I found:
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
zatarra, 2025-02-12:
@ukoda  can you share the pinout of the serial port? I can't find it anywhere and the PCB doesn't have labels.

ukoda, 2025-02-12:
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

@zatarra Attached is a picture of the rear of the board where I have marked up the connector where I was using a pin jig.  I used the SMA as ground since my probes are wider then the pin spacing so it was getting crowed in that area.  If you are not worried about returning the device then soldering to the PCB will probably be easier. I powered the board via the USB connector.

zatarra, 2025-02-12:
Thanks for the details @ukoda

I'm not sure that the ISP pin is, but I assumed it would be VCC. Maybe I'm wrong? This is how I connected ubertooth to the FTDI module:

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

 In any case I was able to flash the firmware and it seems to work (ubertooth-util -x trigger the xmas lights and I can retrieve the firmware version) until I reset ubertooth. Then it stops working:

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

Once I reset it:
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

If I try to flash the bootloader first I can't get DFU to work:

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

If I try to verify data it fails:

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

Any idea what might be wrong?

ukoda, 2025-02-12:
@zatarra One thing that did catch me out is you can program the app firmware and it appears to work until reset.  What I had to do was program the bootloader first, using that serial interface, then use the DFU tool via USB to get the app in.

If you are working from the the `github.com:greatscottgadgets/ubertooth.git` repo the boot loader is in a firmware/bootloader directory.  After doing a `make` I flashed it by shorting pins 1 and 2 to force the ISP ROM, then shorting 1 and 6 to reset it, and then using `lpc21isp bootloader.hex` SerialDevice `230400 4000`.  After that I removed the short between pins 1 and 2 and power cycled it.

I was then able to use DFU mode to program it via USB.  For that I went to the `firmware/bluetooth_rxtx` directory, used `make` then flashed using `ubertooth-dfu -d bluetooth_rxtx.dfu -r`.

zatarra, 2025-02-12:
Again, thanks for the details @ukoda . I was able to flash the bootloader and then use DFU to flash the firmware. It is still not working correctly as I get lots of **libUSB Error: Operation timed out:  (-7)**  when trying to use its features, but at least it is now able to boot correctly and I can use DFU. I'm using OSX but tomorrow I'll try to use ubertooth with a raspberry pi.

ukoda, 2025-02-13:
@zatarra Based on the DFU process working over USB I would say it is likely that the Ubertooth is now correctly working and it is the PC end that needs looked at.  Trying an RPi next is good idea.

zatarra, 2025-02-13:
Hello @ukoda, so I tried a raspberry pi and I got the exact same results. Any command that uses the radios simply hangs. At this point, I'm not sure if the chips are faulty or if I'm not programming it correctly. The bootloader seems fine otherwise I wouldn't be able to boot. However, flashing the DFU via firmware throws another error. Although it seems to be working and I can query the board for info, any commands that require the use of the radio will make the board hang. In the screenshot below, once I issue the **ubertooth-utils -t** and start the TX test, all of the subsequent commands fail with timeouts. If I power cycle the board, it starts responding again.

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

I'm running out of ideas. Are there any debug modes that could help understand what is going on?

ukoda, 2025-02-13:
@zatarra While unlikely it may be worth trying those tests as root.  I built most of the libraries and tools from the repos, `github.com:greatscottgadgets/libbtbb.git` and `github.com:greatscottgadgets/ubertooth.git`.

I am a newbie to the Ubertooth, I brought it to help with design verification for a Bluetooth product I am developing and I'm still waiting for working hardware for that.  So as a result after testing that Ubertooth worked using the `ubertooth-specan-ui` program I put the hardware aside until have working product to use it with.

At this point I would say you have resolved your problem related to this issue and your current problem may have been addresses in another issue.   If not you may need to create a new issue to see if someone with a deeper knowledge can help you.

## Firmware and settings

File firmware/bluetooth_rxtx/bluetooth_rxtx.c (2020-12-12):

/*
 * Copyright 2010-2013 Michael Ossmann
 * Copyright 2011-2013 Dominic Spill
 *
 * This file is part of Project Ubertooth.
 *
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
 * You should have received a copy of the GNU General Public License
 * along with this program; see the file COPYING.  If not, write to
 * the Free Software Foundation, Inc., 51 Franklin Street,
 * Boston, MA 02110-1301, USA.
 */

#include <string.h>

#include "ubertooth.h"
#include "ubertooth_usb.h"
#include "ubertooth_interface.h"
#include "ubertooth_rssi.h"
#include "ubertooth_cs.h"
#include "ubertooth_dma.h"
#include "ubertooth_clock.h"
#include "bluetooth.h"
#include "bluetooth_le.h"
#include "cc2400_rangetest.h"
#include "ego.h"
#include "debug_uart.h"
#include "xmas.h"

#define MIN(x,y)	((x)<(y)?(x):(y))
#define MAX(x,y)	((x)>(y)?(x):(y))

/* build info */
const char compile_info[] =
	"ubertooth " GIT_REVISION " (" COMPILE_BY "@" COMPILE_HOST ") " TIMESTAMP;

/* hopping stuff */
volatile uint8_t  hop_mode = HOP_NONE;
volatile uint8_t  do_hop = 0;                  // set by timer interrupt
volatile uint16_t channel = 2441;
volatile uint16_t hop_direct_channel = 0;      // for hopping directly to a channel
volatile uint16_t hop_timeout = 158;
volatile uint16_t requested_channel = 0;
volatile uint16_t le_adv_channel = 2402;
volatile int      cancel_follow = 0;

/* bulk USB stuff */
volatile uint8_t  idle_buf_clkn_high = 0;
volatile uint32_t idle_buf_clk100ns = 0;
volatile uint16_t idle_buf_channel = 0;
volatile uint8_t  dma_discard = 0;
volatile uint8_t  status = 0;

/* operation mode */
volatile uint8_t mode = MODE_IDLE;
volatile uint8_t requested_mode = MODE_IDLE;
volatile uint8_t jam_mode = JAM_NONE;
volatile uint8_t ego_mode = EGO_FOLLOW;

volatile uint8_t modulation = MOD_BT_BASIC_RATE;

/* specan stuff */
volatile uint16_t low_freq = 2400;
volatile uint16_t high_freq = 2483;
volatile int8_t rssi_threshold = -30;  // -54dBm - 30 = -84dBm

/* Generic TX stuff */
generic_tx_packet tx_pkt;

/* le slave stuff */
uint8_t slave_mac_address[6] = { 0, };
uint8_t le_adv_data[LE_ADV_MAX_LEN] = { 0x02, 0x01, 0x05 };
unsigned le_adv_len = 3;

le_state_t le = {
	.access_address = 0x8e89bed6,           // advertising channel access address
	.synch = 0x6b7d,                        // bit-reversed adv channel AA
	.syncl = 0x9171,
	.crc_init  = 0x555555,                  // advertising channel CRCInit
	.crc_init_reversed = 0xAAAAAA,
	.crc_verify = 0,

	.link_state = LINK_INACTIVE,
	.conn_epoch = 0,
	.do_follow = 1,
	.target_set = 0,
	.last_packet = 0,
};

typedef struct _le_promisc_active_aa_t {
	u32 aa;
	int count;
} le_promisc_active_aa_t;

typedef struct _le_promisc_state_t {
	// LFU cache of recently seen AA's
	le_promisc_active_aa_t active_aa[32];

	// recovering hop interval
	u32 smallest_hop_interval;
	int consec_intervals;
} le_promisc_state_t;
le_promisc_state_t le_promisc;
#define AA_LIST_SIZE (int)(sizeof(le_promisc.active_aa) / sizeof(le_promisc_active_aa_t))

/* LE jamming */
#define JAM_COUNT_DEFAULT 40
int le_jam_count = 0;

/* set LE access address */
static void le_set_access_address(u32 aa);

typedef int (*data_cb_t)(char *);
data_cb_t data_cb = NULL;

typedef void (*packet_cb_t)(u8 *);
packet_cb_t packet_cb = NULL;

/* Unpacked symbol buffers (two rxbufs) */
char unpacked[DMA_SIZE*8*2];

static int enqueue(uint8_t type, uint8_t* buf)
{
	usb_pkt_rx* f = usb_enqueue();

	/* fail if queue is full */
	if (f == NULL) {
		status |= FIFO_OVERFLOW;
		return 0;
	}

	f->pkt_type = type;
	if(type == SPECAN) {
		f->clkn_high = (clkn >> 20) & 0xff;
		f->clk100ns = CLK100NS;
	} else {
		f->clkn_high = idle_buf_clkn_high;
		f->clk100ns = idle_buf_clk100ns;
		f->channel = (uint8_t)((idle_buf_channel - 2402) & 0xff);
		f->rssi_min = rssi_min;
		f->rssi_max = rssi_max;
		f->rssi_avg = rssi_get_avg(idle_buf_channel);
		f->rssi_count = rssi_count;
	}

	memcpy(f->data, buf, DMA_SIZE);

	f->status = status;
	status = 0;

	return 1;
}

int enqueue_with_ts(uint8_t type, uint8_t* buf, uint32_t ts)
{
	usb_pkt_rx* f = usb_enqueue();

	/* fail if queue is full */
	if (f == NULL) {
		status |= FIFO_OVERFLOW;
		return 0;
	}

	f->pkt_type = type;

	f->clkn_high = 0;
	f->clk100ns = ts;

	f->channel = (uint8_t)((channel - 2402) & 0xff);
	f->rssi_avg = 0;
	f->rssi_count = 0;

	memcpy(f->data, buf, DMA_SIZE);

	f->status = status;
	status = 0;

	return 1;
}

static int vendor_request_handler(uint8_t request, uint16_t* request_params, uint8_t* data, int* data_len)
{
	uint32_t clock;
	size_t length; // string length
	usb_pkt_rx* p = NULL;
	uint16_t reg_val;
	uint8_t i;
	unsigned data_in_len = request_params[2];

	switch (request) {

	case UBERTOOTH_PING:
		*data_len = 0;
		break;

	case UBERTOOTH_RX_SYMBOLS:
		requested_mode = MODE_RX_SYMBOLS;
		*data_len = 0;
		break;

#ifdef TX_ENABLE
	case UBERTOOTH_TX_SYMBOLS:
		hop_mode = HOP_BLUETOOTH;
		requested_mode = MODE_TX_SYMBOLS;
		*data_len = 0;
		break;
#endif

	case UBERTOOTH_GET_USRLED:
		data[0] = (USRLED) ? 1 : 0;
		*data_len = 1;
		break;

	case UBERTOOTH_SET_USRLED:
		if (request_params[0])
			USRLED_SET;
		else
			USRLED_CLR;
		break;

	case UBERTOOTH_GET_RXLED:
		data[0] = (RXLED) ? 1 : 0;
		*data_len = 1;
		break;

	case UBERTOOTH_SET_RXLED:
		if (request_params[0])
			RXLED_SET;
		else
			RXLED_CLR;
		break;

	case UBERTOOTH_GET_TXLED:
		data[0] = (TXLED) ? 1 : 0;
		*data_len = 1;
		break;

	case UBERTOOTH_SET_TXLED:
		if (request_params[0])
			TXLED_SET;
		else
			TXLED_CLR;
		break;

	case UBERTOOTH_GET_1V8:
		data[0] = (CC1V8) ? 1 : 0;
		*data_len = 1;
		break;

	case UBERTOOTH_SET_1V8:
		if (request_params[0])
			CC1V8_SET;
		else
			CC1V8_CLR;
		break;

	case UBERTOOTH_GET_PARTNUM:
		get_part_num(data, data_len);
		break;

	case UBERTOOTH_RESET:
		requested_mode = MODE_RESET;
		break;

	case UBERTOOTH_GET_SERIAL:
		get_device_serial(data, data_len);
		break;

#ifdef UBERTOOTH_ONE
	case UBERTOOTH_GET_PAEN:
		data[0] = (PAEN) ? 1 : 0;
		*data_len = 1;
		break;

	case UBERTOOTH_SET_PAEN:
		if (request_params[0])
			PAEN_SET;
		else
			PAEN_CLR;
		break;

	case UBERTOOTH_GET_HGM:
		data[0] = (HGM) ? 1 : 0;
		*data_len = 1;
		break;

	case UBERTOOTH_SET_HGM:
		if (request_params[0])
			HGM_SET;
		else
			HGM_CLR;
		break;
#endif

#ifdef TX_ENABLE
	case UBERTOOTH_TX_TEST:
		requested_mode = MODE_TX_TEST;
		break;

	case UBERTOOTH_GET_PALEVEL:
		data[0] = cc2400_get(FREND) & 0x7;
		*data_len = 1;
		break;

	case UBERTOOTH_SET_PALEVEL:
		if( request_params[0] < 8 ) {
			cc2400_set(FREND, 8 | request_params[0]);
		} else {
			return 0;
		}
		break;

	case UBERTOOTH_RANGE_TEST:
		requested_mode = MODE_RANGE_TEST;
		break;

	case UBERTOOTH_REPEATER:
		requested_mode = MODE_REPEATER;
		break;
#endif

	case UBERTOOTH_RANGE_CHECK:
		data[0] = rr.valid;
		data[1] = rr.request_pa;
		data[2] = rr.request_num;
		data[3] = rr.reply_pa;
		data[4] = rr.reply_num;
		*data_len = 5;
		break;

	case UBERTOOTH_STOP:
		requested_mode = MODE_IDLE;
		break;

	case UBERTOOTH_GET_MOD:
		data[0] = modulation;
		*data_len = 1;
		break;

	case UBERTOOTH_SET_MOD:
		modulation = request_params[0];
		break;

	case UBERTOOTH_GET_CHANNEL:
		data[0] = channel & 0xFF;
		data[1] = (channel >> 8) & 0xFF;
		*data_len = 2;
		break;

	case UBERTOOTH_SET_CHANNEL:
		requested_channel = request_params[0];
		/* bluetooth band sweep mode, start at channel 2402 */
		if (requested_channel > MAX_FREQ) {
			hop_mode = HOP_SWEEP;
			requested_channel = 2402;
		}
		/* fixed channel mode, can be outside bluetooth band */
		else {
			hop_mode = HOP_NONE;
			requested_channel = MAX(requested_channel, MIN_FREQ);
			requested_channel = MIN(requested_channel, MAX_FREQ);
		}

		le_adv_channel = requested_channel;
		if (mode != MODE_BT_FOLLOW_LE) {
			channel = requested_channel;
			requested_channel = 0;

			/* CS threshold is mode-dependent. Update it after
			 * possible mode change. TODO - kludgy. */
			cs_threshold_calc_and_set(channel);
		}
		break;

	case UBERTOOTH_SET_ISP:
		set_isp();
		*data_len = 0; /* should never return */
		break;

	case UBERTOOTH_FLASH:
		bootloader_ctrl = DFU_MODE;
		requested_mode = MODE_RESET;
		break;

	case UBERTOOTH_SPECAN:
		if (request_params[0] < 2049 || request_params[0] > 3072 ||
				request_params[1] < 2049 || request_params[1] > 3072 ||
				request_params[1] < request_params[0])
			return 0;
		low_freq = request_params[0];
		high_freq = request_params[1];
		requested_mode = MODE_SPECAN;
		*data_len = 0;
		break;

	case UBERTOOTH_RX_GENERIC:
		requested_mode = MODE_RX_GENERIC;
		*data_len = 0;
		break;

	case UBERTOOTH_LED_SPECAN:
		if (request_params[0] > 256)
			return 0;
		rssi_threshold = 54 - request_params[0];
		requested_mode = MODE_LED_SPECAN;
		*data_len = 0;
		break;

	case UBERTOOTH_GET_REV_NUM:
		data[0] = 0x00;
		data[1] = 0x00;

		length = (u8)strlen(GIT_REVISION);
		data[2] = length;

		memcpy(&data[3], GIT_REVISION, length);

		*data_len = 2 + 1 + length;
		break;

	case UBERTOOTH_GET_COMPILE_INFO:
		length = (u8)strlen(compile_info);
		data[0] = length;
		memcpy(&data[1], compile_info, length);
		*data_len = 1 + length;
		break;

	case UBERTOOTH_GET_BOARD_ID:
		data[0] = BOARD_ID;
		*data_len = 1;
		break;

	case UBERTOOTH_SET_SQUELCH:
		cs_threshold_req = (int8_t)request_params[0];
		cs_threshold_calc_and_set(channel);
		break;

	case UBERTOOTH_GET_SQUELCH:
		data[0] = cs_threshold_req;
		*data_len = 1;
		break;

	case UBERTOOTH_SET_BDADDR:
		target.address = 0;
		target.syncword = 0;
		for(int i=0; i < 8; i++) {
			target.address |= (uint64_t)data[i] << 8*i;
		}
		for(int i=0; i < 8; i++) {
			target.syncword |= (uint64_t)data[i+8] << 8*i;
		}
		precalc();
		break;

	case UBERTOOTH_START_HOPPING:
		clkn_offset = 0;
		for(int i=0; i < 4; i++) {
			clkn_offset <<= 8;
			clkn_offset |= data[i];
		}
		hop_mode = HOP_BLUETOOTH;
		dma_discard = 1;
		DIO_SSEL_SET;
		clk100ns_offset = (data[4] << 8) | (data[5] << 0);
		requested_mode = MODE_BT_FOLLOW;
		break;

	case UBERTOOTH_AFH:
		hop_mode = HOP_AFH;
		requested_mode = MODE_AFH;

		for(int i=0; i < 10; i++) {
			afh_map[i] = 0;
		}
		used_channels = 0;
		afh_enabled = 1;
		break;

	case UBERTOOTH_HOP:
		do_hop = 1;
		break;

	case UBERTOOTH_SET_CLOCK:
		clock = data[0] | data[1] << 8 | data[2] << 16 | data[3] << 24;
		clkn = clock;
		cs_threshold_calc_and_set(channel);
		break;

	case UBERTOOTH_SET_AFHMAP:
		for(int i=0; i < 10; i++) {
			afh_map[i] = data[i];
		}
		afh_enabled = 1;
		*data_len = 10;
		break;

	case UBERTOOTH_CLEAR_AFHMAP:
		for(int i=0; i < 10; i++) {
			afh_map[i] = 0;
		}
		afh_enabled = 0;
		*data_len = 10;
		break;

	case UBERTOOTH_GET_CLOCK:
		clock = clkn;
		for(int i=0; i < 4; i++) {
			data[i] = (clock >> (8*i)) & 0xff;
		}
		*data_len = 4;
		break;

	case UBERTOOTH_TRIM_CLOCK:
		clk100ns_offset = (data[0] << 8) | (data[1] << 0);
		break;

	case UBERTOOTH_FIX_CLOCK_DRIFT:
		clk_drift_ppm += (int16_t)(data[0] << 8) | (data[1] << 0);

		// Too slow
		if (clk_drift_ppm < 0) {
			clk_drift_correction = 320 / (uint16_t)(-clk_drift_ppm);
			clkn_next_drift_fix = clkn_last_drift_fix + clk_drift_correction;
		}
		// Too fast
		else if (clk_drift_ppm > 0) {
			clk_drift_correction = 320 / clk_drift_ppm;
			clkn_next_drift_fix = clkn_last_drift_fix + clk_drift_correction;
		}
		// Don't trim
		else {
			clk_drift_correction = 0;
			clkn_next_drift_fix = 0;
		}

		break;

	case UBERTOOTH_BTLE_SNIFFING:
		le.do_follow = request_params[0];
		*data_len = 0;

		do_hop = 0;
		hop_mode = HOP_BTLE;
		requested_mode = MODE_BT_FOLLOW_LE;

		usb_queue_init();
		cs_threshold_calc_and_set(channel);
		break;

	case UBERTOOTH_GET_ACCESS_ADDRESS:
		for(int i=0; i < 4; i++) {
			data[i] = (le.access_address >> (8*i)) & 0xff;
		}
		*data_len = 4;
		break;

	case UBERTOOTH_SET_ACCESS_ADDRESS:
		le_set_access_address(data[0] | data[1] << 8 | data[2] << 16 | data[3] << 24);
		le.target_set = 1;
		break;

	case UBERTOOTH_DO_SOMETHING:
		// do something! just don't commit anything here
		break;

	case UBERTOOTH_DO_SOMETHING_REPLY:
		// after you do something, tell me what you did!
		// don't commit here please
		data[0] = 0x13;
		data[1] = 0x37;
		*data_len = 2;
		break;

	case UBERTOOTH_GET_CRC_VERIFY:
		data[0] = le.crc_verify ? 1 : 0;
		*data_len = 1;
		break;

	case UBERTOOTH_SET_CRC_VERIFY:
		le.crc_verify = request_params[0] ? 1 : 0;
		break;

	case UBERTOOTH_POLL:
		p = dequeue();
		if (p != NULL) {
			memcpy(data, (void *)p, sizeof(usb_pkt_rx));
			*data_len = sizeof(usb_pkt_rx);
		} else {
			data[0] = 0;
			*data_len = 1;
		}
		break;

	case UBERTOOTH_BTLE_PROMISC:
		*data_len = 0;

		hop_mode = HOP_NONE;
		requested_mode = MODE_BT_PROMISC_LE;

		usb_queue_init();
		cs_threshold_calc_and_set(channel);
		break;

	case UBERTOOTH_READ_REGISTER:
		reg_val = cc2400_get(request_params[0]);
		data[0] = (reg_val >> 8) & 0xff;
		data[1] = reg_val & 0xff;
		*data_len = 2;
		break;

	case UBERTOOTH_WRITE_REGISTER:
		cc2400_set(request_params[0] & 0xff, request_params[1]);
		break;

	case UBERTOOTH_WRITE_REGISTERS:
		for(i=0; i<request_params[0]; i++) {
			reg_val = (data[(i*3)+1] << 8) | data[(i*3)+2];
			cc2400_set(data[i*3], reg_val);
		}
		break;

	case UBERTOOTH_READ_ALL_REGISTERS:
		#define MAX_READ_REG 0x2d
		for(i=0; i<=MAX_READ_REG; i++) {
			reg_val = cc2400_get(i);
			data[i*3] = i;
			data[(i*3)+1] = (reg_val >> 8) & 0xff;
			data[(i*3)+2] = reg_val & 0xff;
		}
		*data_len = MAX_READ_REG*3;
		break;

#ifdef TX_ENABLE
	case UBERTOOTH_TX_GENERIC_PACKET:
		i = 7 + data[6];
		memcpy(&tx_pkt, data, i);
		//tx_pkt.channel = data[4] << 8 | data[5];
		requested_mode = MODE_TX_GENERIC;
		*data_len = 0;
		break;

	case UBERTOOTH_BTLE_SLAVE:
		memcpy(slave_mac_address, data, 6);
		requested_mode = MODE_BT_SLAVE_LE;
		break;
#endif

	case UBERTOOTH_LE_SET_ADV_DATA:
		// make sure the data fits in our buffer
		if (data_in_len > LE_ADV_MAX_LEN)
			return 0;
		le_adv_len = data_in_len;
		memcpy(le_adv_data, data, le_adv_len);
		break;

	case UBERTOOTH_BTLE_SET_TARGET:
		// Addresses appear in packets in reverse-octet order.
		// Store the target address in reverse order so that we can do a simple memcmp later
		if (data[6] > 48) {
			return 0; // invalid mask
		}
		else if (data[6] == 0) {
			le.target_set = 0;
			memset(le.target, 0, 6);
			memset(le.target_mask, 0, 6);
		} else {
			unsigned last;

			for (i = 0; i < 6; ++i)
				le.target[i] = data[5-i];

			// compute mask
			memset(le.target_mask, 0, 6);
			for (i = 5; data[6] > 8; --i, data[6] -= 8) {
				le.target_mask[i] = 0xff;
			}
			last = i;

			if (data[6] > 0) {
				uint8_t final_byte = 0;
				for (i = 0; i < data[6]; ++i) {
					final_byte >>= 1;
					final_byte |= 0b10000000;
				}
				le.target_mask[last] = final_byte;
			}

			// in case the user specifies a bad mask
			for (i = 0; i < 5; ++i)
				le.target[i] &= le.target_mask[i];

			le.target_set = 1;
		}
		break;

	case UBERTOOTH_CANCEL_FOLLOW:
		// cancel following an active connection
		cancel_follow = 1;
		break;

#ifdef TX_ENABLE
	case UBERTOOTH_JAM_MODE:
		jam_mode = request_params[0];
		break;
#endif

	case UBERTOOTH_EGO:
		ego_mode = request_params[0];
#ifndef TX_ENABLE
		if (ego_mode == EGO_JAM)
			return 0;
#endif
		requested_mode = MODE_EGO;
		break;

	case UBERTOOTH_RFCAT_SUBCMD:
		return rfcat_subcommand(request_params[0], data, *data_len);
		break;

	case UBERTOOTH_XMAS:
		requested_mode = MODE_XMAS;
		break;

	default:
		return 0;
	}
	return 1;
}

/* Update CLKN. */
void TIMER0_IRQHandler()
{
	if (T0IR & TIR_MR0_Interrupt) {

		clkn += clkn_offset + 1;
		clkn_offset = 0;

		uint32_t le_clk = (clkn - le.conn_epoch) & 0x03;

		/* Trigger hop based on mode */

		/* NONE or SWEEP -> 25 Hz */
		if (hop_mode == HOP_NONE || hop_mode == HOP_SWEEP) {
			if ((clkn & 0x7f) == 0)
				do_hop = 1;
		}
		/* BLUETOOTH -> 1600 Hz */
		else if (hop_mode == HOP_BLUETOOTH) {
			if ((clkn & 0x1) == 0)
				do_hop = 1;
		}
		/* BLUETOOTH Low Energy -> 7.5ms - 4.0s in multiples of 1.25 ms */
		else if (hop_mode == HOP_BTLE) {
			// Only hop if connected
			if (le.link_state == LINK_CONNECTED && le_clk == 0) {
				--le.interval_timer;
				if (le.interval_timer == 0) {
					do_hop = 1;
					++le.conn_count;
					le.interval_timer = le.conn_interval;
				} else {
					TXLED_CLR; // hack!
				}
			}
		}
		else if (hop_mode == HOP_AFH) {
			if( (last_hop + hop_timeout) == clkn ) {
				do_hop = 1;
			}
		}

		// Fix linear clock drift deviation
		if(clkn_next_drift_fix != 0 && clk100ns_offset == 0) {
			if(clkn >= clkn_next_drift_fix) {

				// Too fast
				if(clk_drift_ppm >= 0) {
					clk100ns_offset = 1;
				}

				// Too slow
				else {
					clk100ns_offset = 6249;
				}
				clkn_last_drift_fix = clkn;
				clkn_next_drift_fix = clkn_last_drift_fix + clk_drift_correction;
			}
		}

		// Negative clock correction
		if(clk100ns_offset > 3124)
			clkn += 2;

		T0MR0 = 3124 + clk100ns_offset;
		clk100ns_offset = 0;

		/* Ack interrupt */
		T0IR = TIR_MR0_Interrupt;
	}
}

/* EINT3 handler is also defined in ubertooth.c for TC13BADGE. */
#ifndef TC13BADGE
void EINT3_IRQHandler()
{
	/* TODO - check specific source of shared interrupt */
	IO2IntClr   = PIN_GIO6; // clear interrupt
	DIO_SSEL_CLR;           // enable SPI
	cs_trigger  = 1;        // signal trigger
	if (hop_mode == HOP_BLUETOOTH)
		dma_discard = 0;

}
#endif // TC13BADGE

/*
 * Sleep (busy wait) for 'millis' milliseconds
 * Needs clkn. Be sure to call clkn_init() before using it.
 */
static void msleep(uint32_t millis)
{
	uint32_t now = (clkn & 0xffffff);
	uint32_t stop_at = now + millis * 10000 / 3125; // millis -> clkn ticks

	// handle clkn overflow
	if (stop_at >= ((uint32_t)1<<28)) {
		stop_at -= ((uint32_t)1<<28);
		while ((clkn & 0xffffff) >= now || (clkn & 0xffffff) < stop_at);
	} else {
		while ((clkn & 0xffffff) < stop_at);
	}
}

void legacy_DMA_IRQHandler();
void le_DMA_IRQHandler();
void DMA_IRQHandler(void) {
	if (mode == MODE_BT_FOLLOW_LE)
		le_DMA_IRQHandler();
	else
		legacy_DMA_IRQHandler();

	// DMA channel 7: debug UART
	if (DMACIntStat & (1 << 7)) {
		// TC -- DMA completed, unset flag so another printf can occur
		if (DMACIntTCStat & (1 << 7)) {
			DMACIntTCClear = (1 << 7);
			debug_dma_active = 0;
		}
		// error -- blow up
		if (DMACIntErrStat & (1 << 7)) {
			DMACIntErrClr = (1 << 7);
			// FIXME do something better here
			USRLED_SET;
			while (1) { }
		}
	}
}

void legacy_DMA_IRQHandler()
{
	if ( mode == MODE_RX_SYMBOLS
	   || mode == MODE_BT_FOLLOW
	   || mode == MODE_SPECAN
	   || mode == MODE_BT_FOLLOW_LE
	   || mode == MODE_BT_PROMISC_LE
	   || mode == MODE_BT_SLAVE_LE
	   || mode == MODE_RX_GENERIC)
	{
		/* interrupt on channel 0 */
		if (DMACIntStat & (1 << 0)) {
			if (DMACIntTCStat & (1 << 0)) {
				DMACIntTCClear = (1 << 0);

				if (hop_mode == HOP_BLUETOOTH)
					DIO_SSEL_SET;

				idle_buf_clk100ns  = CLK100NS;
				idle_buf_clkn_high = (clkn >> 20) & 0xff;
				idle_buf_channel   = channel;

				/* Keep buffer swapping in sync with DMA. */
				volatile uint8_t* tmp = active_rxbuf;
				active_rxbuf = idle_rxbuf;
				idle_rxbuf = tmp;

				++rx_tc;
			}
			if (DMACIntErrStat & (1 << 0)) {
				DMACIntErrClr = (1 << 0);
				++rx_err;
			}
		}
	}
}

static void cc2400_idle()
{
	cc2400_strobe(SRFOFF);
	while ((cc2400_status() & FS_LOCK)); // need to wait for unlock?

#ifdef UBERTOOTH_ONE
	PAEN_CLR;
	HGM_CLR;
#endif

	RXLED_CLR;
	TXLED_CLR;
	USRLED_CLR;

	clkn_stop();
	dio_ssp_stop();
	cs_reset();
	rssi_reset();

	/* hopping stuff */
	hop_mode = HOP_NONE;
	do_hop = 0;
	channel = 2441;
	hop_direct_channel = 0;
	hop_timeout = 158;
	requested_channel = 0;
	le_adv_channel = 2402;


	/* bulk USB stuff */
	idle_buf_clkn_high = 0;
	idle_buf_clk100ns = 0;
	idle_buf_channel = 0;
	dma_discard = 0;
	status = 0;

	/* operation mode */
	mode = MODE_IDLE;
	requested_mode = MODE_IDLE;
	jam_mode = JAM_NONE;
	ego_mode = EGO_FOLLOW;

	modulation = MOD_BT_BASIC_RATE;

	/* specan stuff */
	low_freq = 2400;
	high_freq = 2483;
	rssi_threshold = -30;

	target.address = 0;
	target.syncword = 0;
}
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
int main()
{
	// enable all fault handlers (see fault.c)
	SCB_SHCSR = (1 << 18) | (1 << 17) | (1 << 16);

	ubertooth_init();
	clkn_init();
	ubertooth_usb_init(vendor_request_handler);
	cc2400_idle();
	dma_poweron();

	debug_uart_init(0);
	debug_printf("\n\n****UBERTOOTH BOOT****\n%s\n", compile_info);

	while (1) {
		handle_usb(clkn);
		if(requested_mode != mode) {
			switch (requested_mode) {
				case MODE_RESET:
					/* Allow time for the USB command to return correctly */
					wait(1);
					reset();
					break;
				case MODE_AFH:
					mode = MODE_AFH;
					bt_stream_rx();
					break;
				case MODE_RX_SYMBOLS:
					mode = MODE_RX_SYMBOLS;
					bt_stream_rx();
					break;
#ifdef TX_ENABLE
				case MODE_TX_SYMBOLS:
					mode = MODE_TX_SYMBOLS;
					br_transmit();
					break;
#endif
				case MODE_BT_FOLLOW:
					mode = MODE_BT_FOLLOW;
					bt_stream_rx();
					break;
				case MODE_BT_FOLLOW_LE:
					mode = MODE_BT_FOLLOW_LE;
					bt_follow_le();
					break;
				case MODE_BT_PROMISC_LE:
					bt_promisc_le();
					break;
#ifdef TX_ENABLE
				case MODE_BT_SLAVE_LE:
					bt_slave_le();
					break;
				case MODE_TX_TEST:
					mode = MODE_TX_TEST;
					cc2400_txtest(&modulation, &channel);
					break;
				case MODE_RANGE_TEST:
					mode = MODE_RANGE_TEST;
					cc2400_rangetest(&channel);
					requested_mode = MODE_IDLE;
					break;
				case MODE_REPEATER:
					mode = MODE_REPEATER;
					cc2400_repeater(&channel);
					break;
#endif
				case MODE_SPECAN:
					specan();
					break;
				case MODE_LED_SPECAN:
					led_specan();
					break;
				case MODE_EGO:
					mode = MODE_EGO;
					ego_main(ego_mode);
					break;
				case MODE_RX_GENERIC:
					mode = MODE_RX_GENERIC;
					rx_generic();
					break;
#ifdef TX_ENABLE
				case MODE_TX_GENERIC:
					tx_generic();
					break;
#endif
				case MODE_XMAS:
					mode = MODE_XMAS;
					xmas_main();
					break;
				case MODE_IDLE:
					cc2400_idle();
					break;
				default:
					/* This is really an error state, but what can you do? */
					break;
			}
		}
	}
}

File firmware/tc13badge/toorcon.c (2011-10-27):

/*
 * Copyright 2011 Michael Ossmann
 *
 * This file is part of Project Ubertooth.
 *
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
 * You should have received a copy of the GNU General Public License
 * along with this program; see the file COPYING.  If not, write to
 * the Free Software Foundation, Inc., 51 Franklin Street,
 * Boston, MA 02110-1301, USA.
 */

#include "tc13badge.h"
#include "cc2400.h"
#include "bitmaps.h"

void delay(uint16_t duration);
void sleep(void);
void pulse_leds(uint8_t led);
void timer_ra_init(void);
void timer_ra_stop(void);
void timer_ra_start(void);
void r8c_init(void);
void specan_init(void);
void led_specan(void);
void post(void);
void main(void);
int logo_update(void);
int icon_update(void);
void pov_logo(void);
void pov_icon(void);
void easter_egg(void);

uint8_t tests_completed = 0;
int easter_threshold = -169;
uint8_t easter_is_coming = 0;
volatile int timesup = 0;
volatile int button_pressed = 0;
uint8_t pwm[13];

/* interrupt service routine for INT3 (button SW1) */
void __attribute__((interrupt)) int3_handler(void)
{
	button_pressed++;
}

/* interrupt service routine for INT0 (R8C_CTL) */
void __attribute__((interrupt)) int0_handler(void)
{
}

/* interrupt service routine for Timer RA */
void __attribute__((interrupt)) timer_ra_handler(void)
{
	timesup++;
}

void delay(uint16_t duration)
{
	int i, j;
	for (i = duration; i; i--)
		for (j = 13; j; j--)
			asm("nop");
}

void sleep(void)
{
	all_leds_off();
	uart_off();
	cc2400_off();
	button_pressed = 0;
	stop_until_button();
	cc2400_init();
	uart_init();
	cc2400_clock_start();
	pulse_leds(13);
}

void pulse_leds(uint8_t led)
{
	int i, j;

	for (i = 455; i; i--) {
		for (j = 0; j < 13; j++) {
			set_led(j, (j < led));
			delay(1);
			set_led(j, 0);
		}
	}
}

// note: vect = 22
void timer_ra_init(void)
{
	DISABLE_INTERRUPTS;
	tracr.tstart = 0;
	while(tracr.tcstf);
	traic = 0;       // disable timer RA interrupts
	tracr.tstop = 1; // initialize timer RA registers
	trapre = 7;
	tra = 13;
	traioc.b = 0x00;
	tramr.b = 0x20;  // timer mode counting fOCO
	traic = 3;       // set timer RA interrupt priority
	FOUR_NOPS;
	ENABLE_INTERRUPTS;
}

void timer_ra_stop(void)
{
	tracr.tstart = 0;
	while(tracr.tcstf);
}

void timer_ra_start(void)
{
	timer_ra_stop();
	timesup = 0;
	tracr.tstart = 1;
	while(!tracr.tcstf);
}

void r8c_init(void)
{
	DISABLE_INTERRUPTS;
	prcr.prc0 = 1;        // disable control register protection
	fra2 = 0x00;          // divide high speed clock by 2 (to 20 MHz)
	fra0.b0 = 1;          // turn on high speed oscillator
	delay(13);            // wait for high speed oscillator to stabilize
	fra0.b1 = 1;          // switch to high speed oscillator
	ocd.ocd2 = 1;         // use internal oscillator for system clock
	cm1.b = cm1.b & 0x3f; // no CPU clock division
	cm0.b6 = 0;           // enable CPU clock division setting
	cm0.b2 = 1;           // peripheral clock stops in WAIT mode
	prcr.prc0 = 0;        // enable control register protection
	trbmr.tckcut = 1;     // cut Timer RB count source for power consumption
	adcon1.vcut = 0;      // cut VREF connection for power consumption
	ENABLE_INTERRUPTS;
}

void specan_init(void)
{
	int i;

	uart_init();
	cc2400_set(MANAND,  0x7fbf); // don't power down oscillator
	cc2400_set(LMTST,   0x2b22);
	cc2400_set(MDMTST0, 0x134b); // without PRNG
	cc2400_set(GRMDM,   0x0101); // un-buffered mode, GFSK
	cc2400_set(MDMCTRL, 0x0029); // 160 kHz frequency deviation
	cc2400_set(RSSI,    0x00F0); // fastest RSSI setting
	uart_off();

	for (i = 0; i < 13; i++)
		pwm[i] = 0;
}

inline void sweep(uint8_t low, uint8_t high, uint16_t base, uint8_t* store)
{
	const char floor = -30;
	char rssi;
	uint16_t channel;

	uint8_t i;

	for (i = low; i < high; i++) {
		channel = base + (i*5);
		//while ((cc2400_status() & FS_LOCK));
		cc2400_set(FSDIV, channel - 1); // tune 1 MHz below because of 1 MHz IF
		cc2400_strobe(SFSON);
		while (!(cc2400_status() & FS_LOCK));
			//cc2400_strobe(SFSON);
		cc2400_strobe(SRX);
		delay(1);
		rssi = cc2400_get(RSSI) >> 8;
		cc2400_strobe(SRFOFF);
		if (rssi > floor)
			store[i] = MAX(store[i], (rssi - floor) >> 1);

		if (channel == 2472) {
			easter_threshold = rssi;
		} else if ((channel == 2470) || (channel == 2474)) {
			if ((rssi + 3) < easter_threshold) {
				if (easter_is_coming < 169) {
					easter_is_coming++;
				}
			} else if (easter_is_coming > 1) {
				easter_is_coming -= 2;
			}
		}
	}
}

/* LED based spectrum analysis */
void led_specan(void)
{
	uint8_t port1, port2, port3;
	uint8_t i, j, k;
	uint8_t radio_on = 0;
	uint16_t loop = 169;
	const uint16_t base = 2410; // lowest channel measured

	i = 0;
	j = 0;

	while (loop--) {
		if (i < 12) {
			port1 = 1;
			port2 = 0;
			port3 = 0;
			if (pwm[0] > i) port3 |= (1 << 5);
			if (pwm[1] > (12 - i)) port3 |= (1 << 4);
			if (pwm[2] > i) port1 |= (1 << 1);
			if (pwm[3] > (12 - i)) port1 |= (1 << 2);
			if (pwm[4] > i) port1 |= (1 << 7);
			if (pwm[5] > (12 - i)) port2 |= (1 << 0);
			if (pwm[6] > i) port2 |= (1 << 2);
			if (pwm[7] > (12 - i)) port2 |= (1 << 1);
			if (pwm[8] > i) port2 |= (1 << 3);
			if (pwm[9] > (12 - i)) port2 |= (1 << 4);
			if (pwm[10] > i) port2 |= (1 << 5);
			if (pwm[11] > (12 - i)) port2 |= (1 << 6);
			if (pwm[12] > i) port2 |= (1 << 7);
			p1.b = port1;
			p2.b = port2;
			p3.b = port3;
			// above is just a faster version of this:
			//for (k = 0; k < 13; k++)
				//set_led(k, (pwm[k] > i));

			/* delay in low power WAIT mode */
			prcr.b = 0x09;    // disable control register protection
			vca2.b0 = 1;      // enable voltage detector low power mode
			fra0.b1 = 0;      // switch to low speed oscillator
			fra0.b0 = 0;      // turn off high speed oscillator
			tracr.tstart = 1; // start timer
			WAIT;
			FOUR_NOPS;
			fra0.b0 = 1;      // turn on high speed oscillator
			fra0.b1 = 1;      // switch to high speed oscillator
			vca2.b0 = 0;      // disable voltage detector low power mode
			prcr.b = 0x00;    // enable control register protection
			timer_ra_stop();  // stop timer

		} else {
			p1.b = 1;
			p2.b = 0;
			p3.b = 0;
			// above is a faster all_leds_off()

			/* measure signal strength on 13 channels */
			uart_init();
			cc2400_strobe(SXOSCON);
			while (!(cc2400_status() & XOSC16M_STABLE));
			sweep(0, 13, base+j, &pwm[0]);
			while ((cc2400_status() & FS_LOCK));
			cc2400_strobe(SXOSCOFF);
			uart_off();
		}

		i = (i+1) % 13;
		if (i == 0) {
			j = (j+1) % 5;
			/* fade out */
			for (k = 0; k < 13; k++)
				if (pwm[k] > 0)
					pwm[k]--;
		}
	}
}
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

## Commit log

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2010-10-26 fixed missing SSEL0 connection
    [ubertooth-zero.brd, ubertooth-zero.sch]
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2010-11-15 fixed zone cutouts
    [ubertooth-one.brd]
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2010-12-01 silkscreen fix
    [ubertooth-one.brd]
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2010-12-31 regulator mask fix
    [ubertooth-one.brd]
2010-12-31 removed extra DNP cap, fixed erroneous DNP marking on 1V8SHDN pull-down, normalized LED orientation
    [ubertooth-zero.brd, ubertooth-zero.sch]
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2011-01-06 fixed num_blocks rx bug
    [ubertooth.c]
2011-01-14 I spent months thinking this was a hardare bug.
    [ubertooth.c]
2011-01-15 kismet plugin - empty shell that doesn't talk to a device yet
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2011-01-26 Ubertooth One bug fixes
    [bluetooth_rxtx.c, ubertooth.h]
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2011-02-06 Reset and makefile tweaks
    [bluetooth_rxtx.c, ubertooth.c, ubertooth.h]
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2011-03-09 dramatically improved UAP discovery success rate by not skipping so many USB frames due to wasted cycles
2011-03-09 python bindings contributed by Kane Mathers
    [ubertooth.c]
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2011-04-10 Change to PCONP_PCUSB to solve signed vs. unsigned compilation error. TODO: I recommend that bit-#defines be declared as shifting an unsigned value (e.g. "1U << 31"), instead of the implied signed-in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
    [lpc17.h]
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2011-04-10 Initial implementation of USB DFU protocol in C++ (or rather "C+", using a few of the nicer aspects of C++ to make C development cleaner). The protocol itself seems to be working well, but integratio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
    [iap.h]
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2011-04-11 Changed run_application() function to assembly implementation that expects the application code block to start with the initial stack pointer value and reset vector. This matches the vector table lay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
2011-04-14 moved pin 1 label to correct layer
    [pogoprog.brd]
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2011-04-22 set paste layer clearance to -12%
    [pogoprog.brd]
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2011-05-07 Removed extraneous printing of DFU get_state() values. Added "usage" output if the command is unknown. Right now, argument/options parsing is very crude and done too late (after the USB device is loc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
2011-06-15 Missed some command-renaming bits (the usage string in the code itself). Improved error handling and status printing some. Throwing RuntimeErrors for exceptions that are expected and should be report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
2011-06-25 improved libusb error reporting, patch 3315254 (Thanks, thebigguy!)
    [ubertooth.c]
2011-06-25 fixed some return values
    [ubertooth.c]
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2011-06-26 tolerate LIBUSB_ERROR_OTHER on resets
    [ubertooth.c]
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2011-06-27 fixed wrong expected libusb errors
    [ubertooth.c]
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2011-07-10 artichoke: fixed some erc errors, removed ADC section
    [artichoke.sch]
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2011-08-14 Broccoli: replaced some bogus modules
    [broccoli.brd, broccoli.sch]
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2011-08-14 fixed battery holder polarity
    [broccoli.brd]
2011-08-14 Broccoli: fixed broken wire
    [broccoli.brd, broccoli.sch]
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2011-08-15 Broccoli paste clearance, BK-912 silkscreen
    [broccoli.brd]
2011-08-15 Broccoli paste clearance, for real this time
    [broccoli.brd]
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2011-10-27 Initial support for Ubertooth function on ToorCon 13 Badge. You must update firmware on both the R8C and the LPC175x for this to work. Automatic switching from ToorCon mode (LED specan on R8C) to Ube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
    [bluetooth_rxtx.c, tc13badge.c, tc13badge.h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]
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2011-12-05 ubertooth-hop: Don't get excited yet. So far it just does hop reversal, not hop-along.
    [ubertooth.c, ubertooth.h]
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2011-12-19 pogoprog bom corrections
    [pogoprog.sch]
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2012-02-17 oops. missed getting true/false bool from where they should really come from
    [ubertooth.h]
2012-02-17 Output correct operating channel. Thanks, Will!
    [ubertooth.c, ubertooth.h]
2012-02-17 support for multiple ubertooth devices (-u#) more missing spcecan stuff (sigh)
    [ubertooth.c]
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2012-02-18 missed a couple of reports put options in alphabetical order -u no longer needs to be 1st option
    [ubertooth.c]
2012-02-18 identify ubertooth device by flashing leds (ubertooth-util) add multi-device support to all other utilities move multi-device flag to -U to avoid already used -u in other tools
    [ubertooth.c]
2012-02-19 stop ubertooth without full reset (ubertooth-util -S)
    [bluetooth_rxtx.c, ubertooth.c, ubertooth.h]
2012-02-20 Use corrected LAP information from libbtbb sniff_ac()
    [ubertooth.c]
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2012-02-21 fix init timer as per comment (//FIXME only need to wait 50us)
    [ubertooth.c]
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2012-03-08 Firmware: recalibrate wait_us ... nobody likes their blinky at the wrong speed
    [ubertooth.c]
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2012-03-10 Firmware: fix clkn wrapping
    [bluetooth_rxtx.c]
2012-03-10 Host: maybe correct clkn calculation
    [ubertooth.c]
2012-03-11 Firmware: rework TIMER0 to be CLKN - Make timer fire every 312.5 us, can be used to control hopping, etc. - Update msleep() - NOTE: interrupt is now hit every 32000 cpu clock cycles
    [bluetooth_rxtx.c]
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2012-03-12 Firmware: sweep during bt_stream_rx() Change hop_mode to HOP_SWEEP to enable at 200 hop/s sweep. Bluetooth hopping could be triggered this way too, with the addition of detection of missed hops.
    [bluetooth_rxtx.c]
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2012-03-17 Firmware: board side squelch - Currently at a fixed 6dB "SNR" (max - avg power within a 400 usec packet). - There should be a command to control this. - Fix: channel was not updated when switching fr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
    [bluetooth_rxtx.c]
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2012-03-25 Move squelch to firmware. - Use "carrier sense" on CC2400 as a trigger, received LPC17XX interrupt - Keep squelch open for min 2 packets (CS_HOLD_TIME) - Set squelch level with ubertooth-util -z-70 (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
    [bluetooth_rxtx.c, ubertooth.c, ubertooth.h]
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2012-03-30 Firmware: send keepalive data at 6Hz to prevent host timeout at high squelch
    [bluetooth_rxtx.c]
2012-03-31 Firmware: replace float math in IIR with scaled int math - saves 4K flash (float library) - saves 160 bytes RAM - should be much faster
    [bluetooth_rxtx.c]
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2012-04-06 Firmware: add per-channel max-to-iir thresholding - a positive threshold (ubertooth-util -z20) uses max-to-iir per channel - a negative threshold (ubertooth-util -z-70) is a single value used by all 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
    Per-channel threshold is not used in single channel mode, since the rssi iir
    is kept only for Bluetooth channels. In single channel mode, -z20 means
    +20dBm, i.e., no packets.
    [bluetooth_rxtx.c]
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2012-04-13 Host: ubertooth-lap: lap-triggered dump, max_ac_errors parameter - -d <dumpfile> option will dump packets to a dumpfile only when a LAP decodes - -e <max_ac_errors> option will ignore decodes with > 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
    [ubertooth.c]
2012-04-17 removing outdated python bindings that lack a maintainer (and presumably users)
    [ubertooth.c]
2012-04-17 fixed some compiler warnings
    [ubertooth.c]
2012-04-17 fixed some more compiler warnings
    [ubertooth.c]
2012-04-21 Host: -D option and -Wall hunt - If -d (LAP-squelched dump) is used, an experimental -D option can be added to prepend each packet with the system time. Without this, capture time for packets in dump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
    [ubertooth.c, ubertooth.h]
2012-04-25 Host: cleanups to correct (or defeat) compiler warnings Now compiles cleanly with -Wall -Werror -pedantic. Nothing important found.
    [ubertooth.c, ubertooth.h]
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2012-05-17 Host: pull clk100ns and other values from correct packet (bug pointed out by Brandon Enochs)
    [ubertooth.c]
2012-05-17 fixed bug introduced in r520 (Thanks, Brandon!)
    [ubertooth.c]
2012-05-17 avoiding more fwrite() compiler warnings
    [ubertooth.c]
2012-07-02 fixed specan bug introduced in r466 (not enough delay for cc2400 to acquire rssi reading)
    [bluetooth_rxtx.c]
2012-07-02 reduced RSSI wait time, applied fix to led_specan()
    [bluetooth_rxtx.c]
2012-07-02 applied fix to bt_stream_rx() after frequency change
    [bluetooth_rxtx.c]
2012-07-02 reversed r528 - it does not seem to be necessary
    [bluetooth_rxtx.c]
2012-07-03 Host: Change default max_ac_errors to 1 to avoid false positives
    [ubertooth.c]
2012-07-04 Host - Make input/optput file formats consistent - Add max errors option to ubertooth-uap
    [ubertooth.c]
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2012-07-09 Use Openmoko vendor and product IDs - Still signing firmware with 0xffff/0x0004 so no need to flash bootloader - Reorg of ubertooth-dfu to move non-ubertooth code to module - Fix vendorId in udev rul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
    [bluetooth_rxtx.c, ubertooth.c, ubertooth.h]
2012-07-09 Replace call to libusb_name_error with our own show_libusb_error - Supports libusb 1.0.x < 1.0.3 (RHEL, Centos, etc) (Thanks to Brandon for spotting this)
    [ubertooth.c]
2012-07-24 Firmware - Comment out code that fails to build (and is currently unused)
    [bluetooth_rxtx.c]
2012-07-24 Host - Hopping changes to avoid USB errors
    [ubertooth.c]
2012-08-04 Host - DFU - Ingore errors which are safe (detach) - If we don't find a device, look for ubertooth devices and switch them in to DFU mode, this could be better (i.e. we should check which mode 0xffff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
2012-08-05 Build - Makefile for host tools (only bluetooth_rxtx and usb_dfu) - Improved Makefile for firmware - Fixed inludes in bootloader and assembly test
2012-08-31 Add clock_debug mode for sniffing a connection for a local device Split libubertooth into control and sniffing sections (1300 lines was too long)
    [bluetooth_rxtx.c, ubertooth.c, ubertooth.h]
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2012-09-30 usb: do not send data from dequeue
    This was an error in the previous commit. dequeue simply returns the
    packet that was enqueued. dequeue_send is responsible for sending it.
    [bluetooth_rxtx.c]
2012-10-01 Use new versions of sniff_ac and find_ac - No longer uese a struct as a return value
    [ubertooth.c]
2012-10-02 le: use the USB interrupt handler
    This also works around a bug where every other packet was getting
    submitted to the bulk endpoint.
    [bluetooth_rxtx.c]
2012-10-02 Remove commented out code - won't be used
    [ubertooth.c]
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2012-10-03 Fix LE file input/output errors
    [ubertooth.c]
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2012-10-06 le: reset queue when re-entering modes
    This prevents stale packets from being flooded over USB when a mode is
    reentered.
    [bluetooth_rxtx.c]
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2012-10-23 Fix shift that has no effect
    [bluetooth_rxtx.c]
2012-10-24 Reset radio packet format defaults for rangetest and txtest functions
    [bluetooth_rxtx.c]
2012-11-22 Change device reset handling to avoid spurious error messages. (Most requested bug fix ever)
    [bluetooth_rxtx.c]
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2012-11-28 firmware: Fix interrupt disable bugs
    Interrupts were not being disabled correctly in cs_trigger_enable()
    and dma_init(). No current effect, but would have caused trouble in
    the future. Thanks to Steven Köppel.
    [bluetooth_rxtx.c]
2012-12-02 firmware: attempt to fix active/idle clock tracking
    [bluetooth_rxtx.c]
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2012-12-06 Migrate to libbtbb API in btbb.h - no longer using bluetooth_packet.h or bluettoh_piconet.h
    [ubertooth.c, ubertooth.h]
2012-12-16 Initialize btbb library with user-selected number of AC errors. Update for libbtbb changes. Print strings for rx libbtbb errors.
    [ubertooth.c]
2013-01-28 le: jump to next channel earlier
    Jump to the next channel in a hop pattern well in advance of when the
    next packet is scheduled to arrive. This should help address issues with
    clock desync between Ubertooth and
    devices.
    The previous behavior was to jump just moments before the next packet
    was sched to arrive. If the device clock was slightly slower than
    Ubertooth clock, we would jump too late and miss packets.
    [bluetooth_rxtx.c]
2013-02-03 le: switch modulation mode to LE in bt_le_generic
    This corrects an amazingly bone-headed error wherein we left the device
    in BR modulation mode when trying to sniff LE packets. This resulted in
    Ubertooth not seeing a majority of packets transmitted by the slave
    device.
    [bluetooth_rxtx.c]
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2013-02-13 le: improve and simplify promiscuous mode
    - search for other types of empty packets
    - automatically jump to a sane channel
    - squelch away the noise
    - reduce number of times we must witness an AA
    - keep a bigger LFU cache of AA's
    [bluetooth_rxtx.c]
2013-02-16 ubertooth.c: add missing braces
    [ubertooth.c]
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2013-05-07 le: partially working RX with sync detection
    first packet received correctly, rest are garbage
    [bluetooth_rxtx.c]
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2013-05-14 Spelling correction (patch 5) [JonathanWMiner]
    [ubertooth.c]
2013-05-14 Remove missed merge conflicts and warnings.
    [ubertooth.c]
2013-05-15 Patch 7 - enhance error handling in ubertooth.c [JonathanWMiner]
    [ubertooth.c]
2013-05-21 Patch 10 - Spelling correction [JonathanWMiner] + tidy setting up sweep mode.
    [bluetooth_rxtx.c]
2013-05-28 Host - Fix error when checking serial numbers but no device found.
    [ubertooth.c]
2013-05-29 Avoid compiler warnings for unused variables in callbacks - Works in both gcc and clang
    [ubertooth.c, ubertooth.h]
2013-05-30 Avoid strict aliasing warning from gcc arm 4.7 - it's a silly warning.
    [bluetooth_rxtx.c]
2013-05-30 Add ability to look register up by %NAME; fix string length bug
    [cc2400.h]
2013-06-10 le: determine packet type by lower nibble only (reject upper bits)
    This worked in the past because all devices tested so far used public
    addresses, leaving the upper bits clear. Testing devices which use
    random addresses tickled the bug: connection packets were properly
    displayed but connections weren't followed.
    [bluetooth_rxtx.c]
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2013-08-19 Add reg2name and replace strcmp with strncmp
    [cc2400.h]
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2013-12-16 Fix 64bit shifts - patch from Kim Lindberg Schwaner
    [bluetooth_rxtx.c]
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2014-02-05 Fix dumpfiles with zero timestamp on first packet
    [ubertooth.c]
2014-02-05 Fix Github issue #4 - Ubertooth-rx "uh oh, full_buf not emptied" https://github.com/greatscottgadgets/ubertooth/issues/4
    [ubertooth.c]
2014-02-10 Replace libusb_error_name() call as pre-1.0.9 libusb is still common
    [ubertooth.c]
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2014-04-09 le: reset CC2400 and DMA engine when exiting modes
    Gracefully exit modes when stopped using ubertooth-util -S. Prior to
    this standard operating procedure was to unplug and replug.
    [bluetooth_rxtx.c]
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2014-06-24 Second attempat at fixing issue #4 - ubertooth-rx buffer issue
    [ubertooth.c]
2014-07-03 Fix segfaults when no device present
    [ubertooth.c]
2014-07-04 Fix indices in unrolled memcpy
    [bluetooth_rxtx.c]
2014-09-07 le: test for transfer doneness based on DMA registers
    This works around an issue in which the firmware was hanging partly due
    to rx_tc not being incremented under certain circumstances. With my
    limited testing, this fixes #15.
    [bluetooth_rxtx.c]
2014-11-11 dump: flush packets immediately
    Fixes #29
    [ubertooth.c]
2014-11-11 Initial addition of version number for host tools (issue #12)
    [ubertooth.c, ubertooth.h]
2014-11-12 le: major improvements to promisc
    Switch to using CC2400 syncword detection for all phases of promiscuous
    mode except AA detection. All subsequent phases complete more reliably.
    Connection following not currently working, perhaps a rounding issue.
    Report mode changes via new USB message type.
    In support of #40.
    [bluetooth_rxtx.c, ubertooth.c]
2014-11-17 le: fix promisc
    Typo / brain fart resulted in us using hop_interval instead of
    hop_increment when calculating the next channel to hop to.
    Fixes #40
    [bluetooth_rxtx.c]
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2015-02-03 Support Connection Update Requests
    Fixes #42, closes #46
    Rebased and adapted David Palchaks's original patch [1] to keep
    promiscuous mode intact and removed debug code.
    I briefly tested follow-mode, promiscuous mode with and without
    target address set.
    [1] http://sourceforge.net/p/ubertooth/mailman/message/32943467/
    [bluetooth_rxtx.c]
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2015-03-09 switch middle and right button functionality and add keyboard shortcut for those with trackpads
2015-03-17 Clean up compiler warnings (missing headers, unused variables, etc)
    [ubertooth.c, ubertooth.h]
2015-03-17 Fix timing information for specan - Has been broken since the change to active/idle buffer clock values
    [bluetooth_rxtx.c]
2015-03-23 Fix USE_PCAP logic to test libBTBB for pcap support
    [ubertooth.c, ubertooth.h]
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2015-04-23 Remove variables that we always hardcode and no longer use anyway
    [ubertooth.c, ubertooth.h]
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2015-05-07 Minor updates to README files.
    Update firmware/bootloader/README for current DFU usage and remove
    references to non-existant directories.
    Fix typo in web/README.
2015-05-11 le: move promisc state into struct
    This allows us to easily keep track of state in one place and reset it
    cleanly as necessary. In the future this could be non-global.
    [bluetooth_rxtx.c]
2015-05-11 le: revert to promisc mode after connection stops being followed
    Previously the code would revert to follow mode, which didn't make
    sense.
    [bluetooth_rxtx.c]
2015-06-30 fix CLKN calculation in cb_br_rx()
    * make clk100ns values in the firmware volatile since they are modified inside an ISR
    * change the offset in the clkn calculation in cb_br_rx(). At 1 Mbps,
    each bit has a duration of 1 us or 10 units of 100 ns. The bit offset
    is multiplied by this duration to calculate the correct clock offset.
    this is related to:
    greatscottgadgets/ubertooth#84
    [bluetooth_rxtx.c, ubertooth.c]
2015-07-25 le: jammer
    Two jamming modes are supported for each of follow and promiscuous mode.
    This gives a total of four jam modes:
    - follow-single: jam the first connection followed and go back to idle
    - follow-continuous: follow new connection, jam, follow new, jam, etc
    - promisc-single: jam the first connection recovered, go back to idle
    - promisc-continuous: recover connection, jam, recover again, jam, etc
    [bluetooth_rxtx.c]
2015-07-31 ego: robustify code a bit and correct a few little things
    [bluetooth_rxtx.c]
2015-08-02 ego: complete rewrite into finite state machine
    Supports:
    - follow mode
    - continuous RX
    - jamming
    [bluetooth_rxtx.c, ubertooth.h]
2015-08-02 le: jam for 40 connection intervals by default
    [bluetooth_rxtx.c]
2015-08-07 jam: promisc jam on rando channels
    [bluetooth_rxtx.c]
2015-08-13 le: reset to MODE_IDLE when exiting connection following
    fixes #89
    [bluetooth_rxtx.c]
2015-08-13 implement #ifdef's for TX_ENABLE
    This allows us to ship a firmware without TX support but gives users the
    ability to enable it at compile time. Most commands emit graceful error
    messages when a lack of jamming support is detected.
    ubertooth-ego behaves a bit wonky
    Closes #95
    [bluetooth_rxtx.c]
2015-08-16 le: measure delta_t correctly when clk100ns rolls over
    Fixes #96
    [ubertooth.c]
2015-08-16 le: correct assumptions about CLK100NS rollover behavior
    See #101
    [bluetooth_rxtx.c]
2015-08-16 ego: calculate delta_t correctly accounting for CLK100NS rollover
    Closes #101
    [ubertooth.c]
2015-09-02 Increase stability and speed of ubertooth-specan-ui
    [ubertooth.c]
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2015-10-16 fix build errors when using strict compiler flags
    [ubertooth.c, ubertooth.h]
2016-01-06 fix indention in libuberooth
    [ubertooth.c, ubertooth.h]
2016-01-06 add ringbuffer datatype to ubertooth struct
    The ringbuffer stores the received USB packets and handles the
    conversion to a bluetooth bitstream. It replaces the arrays usb_packets
    and br_symbols and the banks index.
    [ubertooth.c, ubertooth.h]
2016-01-08 bugfix in specan method of the Ubertooth firmware
    [bluetooth_rxtx.c]
2016-01-21 fix a bug that prevents ubertooth from following a BR piconet
    [bluetooth_rxtx.c, ubertooth.c, ubertooth.h]
2016-01-21 fix build error in kismet plugin
    [ubertooth.c, ubertooth.h]
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2016-02-06 Revert "Switch ubertooth-scan from rx_live to ubertooth_bulk_*"
    This reverts commit b8920cfbbec2ce2e6535b0a41e9e37d7a4c2aef2.
    [ubertooth.c]
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2016-02-26 also handle stop_ubertooth correctly in stream_rx_usb()
    [ubertooth.c]
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2016-03-12 host: exit on ctrl-c for every command except ubertooth-scan
    Fixes a regression introduced by a56d1df that caused ctrl-c to
    essentially be a no-op for all commands.
    [ubertooth.c, ubertooth.h]
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2016-03-24 Reset global firmware variables to their initial value when entering IDLE state. This seems to finally solve issue #135. Also modularize the firmware.
    [bluetooth_rxtx.c]
2016-03-24 fix: also enable clkn in specan mode
    [bluetooth_rxtx.c]
2016-04-08 Fix endianness of serial number to match part number
    [ubertooth.c]
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2016-07-12 correct linear clock drift between piconet and ubertooth in ubertooth-rx
    [bluetooth_rxtx.c]
2016-07-13 firmware: fix compiler warnings
    [bluetooth_rxtx.c]
2016-07-13 fix bootloader USB connection loss in DFU mode
    [bluetooth_rxtx.c]
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2016-08-19 fix regression in bt_slave_le().
    call clkn_start() because a running clkn is needed by msleep()
    [bluetooth_rxtx.c]
2016-09-01 le: ignore malformed CONNECT_REQ packets
    We will only follow connections if:
    - the CONNECT_REQ is the correct length
    - the hop interval is in the legal range
    See #234
    [bluetooth_rxtx.c]
2016-11-21 fix some firmware bugs
    [bluetooth_rxtx.c]
2017-01-22 le: disable USB interrupts while touching USB data structures
    If a USB interrupt fires while we're modifing a USB data structure (such
    as enqueuing a packet in the FIFO), the interrupt handler can modify the
    data structure we're touching. This is akin to a multithreaded app not
    locking shared data structures. We avoid this by hackily disabling USB
    interrupts for the duration that we're modifying the data structure.
    For LE, this works because the host code polls Ubertooth in a tight
    loop. If the poll fails, the host code silently ignores it and retries
    again. This code should be rearchitected to handle USB without
    interrupts in a safe period between packets.
    Fixes #249
    [bluetooth_rxtx.c]
2017-03-03 usb: rssi types are int8_t instead of char
    On some ARM platforms, including Raspberry Pi, char is treated as
    unsigned. This was causing RSSI measurements to be incorrectly reported
    as very large values rather than the correct negative values.
2017-03-04 host: use average RSSI when calculating signal in LE
    The previous code used determine_signal_and_noise(), which assumes that
    packets are continuously streaming in (i.e., rx mode for BR). This
    solution doesn't work for LE since packets are bursty. Additionally we
    currently have no way of capturing noise values in LE.
    We simply convert the max RSSI measured by Ubertooth and set the noise
    value to INT8_MIN. It's a little gross but the best we can do.
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2017-06-23 Memory leak fix (#274)
    * Memory leak fix
    [ubertooth.c]
2017-12-25 firmware: disable individual DMA channels instead of whole controller
    Previously the code shut down the entire DMA controller when it wanted
    to reset state on an individual channel. This un-neighborly behavior
    makes it impossible for other firmware components to make use of DMA.
    This patch rejiggers things so that only individual channels are
    disabled when they are not needed. The GPDMA controller fully powered on
    at boot time, for a small power penalty when idle. But since when did
    this project care about power savings?
    Note that this is only lightly tested and possibly has weird corner
    case side effects.
    [bluetooth_rxtx.c]
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2018-06-25 host: Fix unreachable libusb_free_device_list() in ubertooth_count()
    [ubertooth.c]
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2018-11-19 le slave: limit packets to 32 bytes to work around FIFO issues
    See #208
    [bluetooth_rxtx.c]
2018-12-05 le: correctly return 0 on invalid mask
    [bluetooth_rxtx.c]
2018-12-05 le: handle USB interrupts correctly within LE slave mode
    [bluetooth_rxtx.c]
2018-12-13 le: Fixed CC2400 FIFO usage to allow BLE packets that are larger then 32 bytes
    Added some code to correctly fill-out the CC2400 FIFO while transmitting BLE and removed size limitation placed as a workaround.
    [bluetooth_rxtx.c]
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
